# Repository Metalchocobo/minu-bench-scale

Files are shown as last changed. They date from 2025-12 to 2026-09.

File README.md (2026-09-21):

# Minù Bench Scale — ESP32 + HX711 + OLED SSD1322 + INA219 (LiFePO4 USB-C + Mini360) · v2026-09-18

Bilancia da banco per uso interno in laboratorio (gelato/pasticceria), pensata per guidare e rendere affidabili le pesate ingredienti (non “pesatura legale”).

Progetto meccanico separato: la [soluzione economica proposta per un solo prototipo](docs/mechanical/prototype-affordability/README.md) prevede cella e supporti commerciali T130, con scocca, fondo e piatto FDM personalizzati; costo completo e innesti sono ancora da verificare. Il [CAD della Proposta 02](docs/mechanical/concept-02/README.md) contiene invece quattro parti in alluminio su misura e non è il pacchetto da ordinare per questa soluzione. L'obiettivo resta 20 kg utili, otto tasti, display posseduto e ricarica USB; portata e accoppiamenti richiedono collaudo. Le varianti meccaniche non definiscono l'alimentazione montata, descritta nella sezione 2 e in [WIRING](docs/WIRING.md).

Hardware di riferimento:
- **ESP32 DevKit**
- **HX711** (ADC 24 bit) per cella di carico con eccitazione a **5 V**
- **OLED SSD1322** 256×64 (3,12", SPI)
- **Batteria NASTIMA BK06-LF60-NATC**, LiFePO4 **6,4 V nominali / 6 Ah**, con BMS e ricarica USB-C integrati
- **Mini360 DAOKAI B0B82GL5XN**, chip **MP1482DS**, uscita regolata a **5,11 V** (valore riferito sul montaggio)
- **INA219** (CJMCU-219) per tensione/corrente batteria (high-side)
- **Tastierino 4×2** + **buzzer**

---

## 0) Stato e obiettivo

Target:
- Portata: **20 kg**
- Lettura visualizzata: **1 g** nel campo operativo fino a ±16 kg
- Oltre il campo operativo il peso reale non viene trasformato in 16.000 g: compare lo stato bloccante **SOVRACCARICO**, con isteresi di rientro

Funzioni principali (firmware HX711):
- Lettura HX711 con filtri + stati **STABLE / UNSTABLE / LIVE / SOVRACCARICO**
- **Zero-tracking** vicino allo zero + **snap-to-zero** allo scarico
- **TARA** automatica e manuale con centro robusto: tollera il rumore ambientale, distingue la deriva reale e segnala acusticamente gli errori tecnici
- Monitor batteria con **tacche** + stato **charging** stabilizzato; soltanto campioni INA219 validi, plausibili e freschi alimentano filtri e protezioni
- Protezione “batteria scarica” con **avviso + beep + light-sleep**, anti-flapping (debounce 10 s, recovery stabile 30 s) e cooldown avvisi 5 min
- **HX health** runtime: stati **OK / WARN / ERROR / ERROR HARD**, badge **"Errore Cella"** (testo piccolo + triangolino) in alto a destra in WARN, schermata error bloccante (senza mostrare l'ultimo peso), blocco tara/calib, audio 0015.mp3 una sola volta all’ingresso in ERROR

### HX health (runtime, HX711)

Scopo: gestire errori runtime dell’HX711 **senza blocchi in loop** (logica solo a timestamp) e senza impattare feature non correlate.

**Soglie (ms)**
- WARN se nessun campione valido per **≥ 500 ms**
- ERROR se nessun campione valido per **≥ 3.000 ms**
- ERROR HARD se nessun campione valido per **≥ 30.000 ms** oppure **mai** registrato un valore valido
- Ritorno a OK solo dopo campioni validi “OK stabile” per **≥ 800 ms**

**Cosa conta come “campione valido”**
- Valido quando nel loop: `hx711_is_ready()` è true e `hx711_read()` completa.
- Mitigazione “DOUT mascherato” (es. partitore/pull-down): se il raw resta inchiodato (±1 count) per **> 1500 ms**, quei campioni vengono trattati come **non validi** per HX health (non aggiornano `lastRawMs`). Le soglie WARN/ERROR si conteggiano dall’inizio della flatline.
- `hx711_is_ready() == true` e lettura `hx711_read()` completata nel normale loop (niente medie bloccanti).

**Nota importante (cablaggio DOUT su ESP32)**
- Se **DOUT è su GPIO34..39** (es. **GPIO35**), l’ESP32 **non ha pull-up interni**: a modulo scollegato il pin può fluttuare e risultare “ready” a caso.
- In quel caso la rilevazione “modulo non trovato” non è affidabile solo via firmware.
- Una modifica robusta richiede un GPIO libero con pull-up o una rete esterna coerente con i livelli dell'HX711. **GPIO22 non è libero**: nel pinout corrente pilota il buzzer. Qualsiasi cambio di DOUT va quindi coordinato tra cablaggio, `config/config_pins.h` e documentazione.

**Stati e comportamento**

| Stato | Quando | UI | Audio | Azioni |
|---|---|---|---|---|
| OK | campioni regolari | UI normale | nessuno | tara/calib abilitate |
| WARN | assenza campioni ≥ 500 ms | triangolino warning alto a destra | nessuno | tara manuale abilitata; ENTER bloccato finché HX torna OK |
| ERROR | assenza campioni ≥ 3.000 ms | schermata ERROR bloccante, senza mostrare l'ultimo peso | 0015.mp3 **una sola volta** all’ingresso | **tara/calib disabilitate** |
| ERROR HARD | assenza campioni ≥ 30.000 ms o nessun valore valido mai registrato | schermata ERROR bloccante, **non** mostra valore | 0015.mp3 una sola volta all’ingresso | **tara/calib disabilitate** |

---

## 1) Perché HX711 (e perché non NAU7802)

Vincolo emerso sul campo: la cella di carico è stabile/precisa solo se eccitata a **~5 V**.  
Con NAU7802 si è provato a lavorare a 5 V, ma in un setup reale si è verificato **backfeed verso GPIO ESP32** (tensione logica troppo alta) con danni hardware.

Scelta attuale:
- HX711 alimentato a **5 V**
- ESP32 resta a **3,3 V sui GPIO**
- La linea **DOUT va resa 3,3 V safe** (vedi cablaggio)

Firmware disponibili nel repo:
- ✅ `firmware/esp32_hx711_serial/` → corrente
- ⚠️ `archive/esp32_nau7802_serial/` → storico (non consigliato)
- 🧱 eventuali cartelle “legacy” → archivio, non usare per nuove modifiche

---

## 2) Alimentazione (architettura)

**Configurazione montata:** nuova batteria USB-C NASTIMA e Mini360; Andrea riferisce cablaggio completato e primo funzionamento apparentemente regolare. La regolazione ottenuta in uscita dal Mini360 è **5,11 V**; «linea 5 V» nel resto del documento indica questa alimentazione nominale. La conferma non comprende misure di autonomia, transitori, temperatura o ripartenza dopo intervento del BMS.

Schema logico:
1. Alimentatore USB esterno → passaggio USB-C nella scocca → ingresso USB-C del caricatore **interno alla batteria**; ingresso dichiarato **5 V / 1,5 A**.
2. Batteria **+ → F1 → INA219 VIN+ → VIN− → S1 → Mini360 IN+**.
3. Batteria **− → GND comune / Mini360 IN−**; Mini360 **OUT− → GND comune**.
4. Mini360 **OUT+ → linea nominale 5 V**: ESP32 **VIN/5V**, HX711, OLED compatibile e circuito audio con power-gate esistente.

**S1 è un interruttore semplice sul positivo dopo VIN− dell'INA219. VIN− non è massa.** In OFF stacca il Mini360 dalla batteria; la ricarica interna del pacco rimane indipendente. CTK3S e batteria al piombo non fanno parte dell'alimentazione montata. L'uscita del buck resta collegata all'ESP32: S1 non isola l'eventuale alimentazione proveniente dall'USB del PC. Il ritorno USB non è stato caratterizzato sull'esemplare e non è documentato come guasto.

Condensatori esterni, tutti **in parallelo** e con collegamenti corti vicino ai rispettivi pad del Mini360:
- **IN+ ↔ IN−**, dopo S1: **220 µF / 16 V elettrolitico + 100 nF ceramico**.
- **OUT+ ↔ OUT−**: **470 µF / 10 V elettrolitico + 100 nF ceramico**; sul montaggio il ceramico è più vicino al Mini360.
- Vicino all'ESP32 restano previsti **10–47 µF + 100 nF** fra VIN/5V e GND; non sostituiscono quelli del buck.

Cablaggio completo e polarità: [docs/WIRING.md](docs/WIRING.md). Tavole e dati del convertitore: [Mini360](artifacts/mini360/README.md). Le tacche usano fasce indicative LiFePO4 e l'icona `charging` stima la ricarica dalla tensione; avvisi sonori, countdown e protezioni conservano soglie e tempi, indipendenti dall'icona (sezioni 8–9). La combinazione **TOTAL + WIFI** permette di leggere tensione e corrente INA sul display.

---

## 3) Pinout (firmware HX711)

| Funzione | Modulo | GPIO ESP32 | Note |
|---|---|---:|---|
| I2C SDA | INA219 | 32 | attenzione a non invertire con SCL |
| I2C SCL | INA219 | 33 | |
| HX711 SCK | HX711 | 16 | spesso serigrafato **RX2** |
| HX711 DOUT | HX711 | 35 | input-only, scelto per evitare strap pin |
| SPI SCK | OLED SSD1322 | 18 | VSPI |
| SPI MOSI | OLED SSD1322 | 23 | |
| SPI CS | OLED SSD1322 | 25 | |
| SPI DC | OLED SSD1322 | 26 | |
| SPI RST | OLED SSD1322 | 27 | |
| Tastiera R1 | Keypad | 17 | |
| Tastiera R2 | Keypad | 5 | |
| Tastiera R3 | Keypad | 13 | |
| Tastiera R4 | Keypad | 14 | |
| Tastiera C1 | Keypad | 19 | |
| Tastiera C2 | Keypad | 21 | |
| Buzzer | buzzer passivo | 22 | LEDC |
| DFPlayer TX | DFPlayer RX | 4 | resistenza 1 kΩ in serie consigliata |
| DFPlayer RX | DFPlayer TX | 34 | opzionale, input-only |
| DFPlayer power-gate | high-side esterno | 2 | HIGH = ON; non alimenta direttamente il modulo |
| DFPlayer BUSY | DFPlayer | 39 | input-only; pull-up esterna consigliata |
| LED standby | LED esterno | 15 | active-high, con resistenza in serie |

---

## 4) Cablaggio HX711 (importante)

### 4.1 Cella di carico → HX711
Collega i 4 fili della cella su **E+, E-, A+, A-** (colori variabili: verifica lo schema della tua cella).

### 4.2 HX711 → ESP32 (logica)

**Alimentazioni**
- HX711 **VCC → 5 V**
- HX711 **GND → GND comune**

**SCK (clock)**
- ESP32 GPIO16 → HX711 SCK **diretto (3,3 V va bene)**  
- Consigli pratici:
  - **220 Ω in serie** sul filo SCK vicino all’ESP32 (anti-ringing/spike)
  - **100 kΩ pulldown** tra SCK e GND vicino al modulo HX711 (tiene SCK LOW durante boot/reset)

> Non usare i classici level shifter bidirezionali “I2C-style” (BSS138) su **SCK**: possono tenere la linea alta e mandare HX711 in **power-down**.

**DOUT (data)**
Se HX711 è a 5 V, **DOUT può andare a 5 V**: va reso “3,3 V safe”.

Soluzione consigliata: **partitore resistivo**
- DOUT (HX711) → **10 kΩ** → GPIO35 (ESP32)
- GPIO35 (ESP32) → **20 kΩ** → GND

(Altri valori equivalenti vanno bene, l’obiettivo è restare ~≤3,3 V sul pin ESP32).

Nota pratica:
- Se colleghi DOUT diretto, prima **misura** con multimetro: se HIGH >3,6 V, è rischioso (nel tempo può rovinare l’ESP32).

---

## 5) HX711: 10 SPS vs 80 SPS

La velocità **non** si imposta da software sull’HX711: dipende dal pin/ponte **RATE** del breakout.

- Tipico default: **10 SPS**
- Per passare a **80 SPS**: modifica la pista/ponticello “RATE” sul retro del modulo (dipende dal modello)

---

## 6) Firmware: comportamento “80 Hz senza rumore a display”

Con HX711 a **80 SPS**:
- il firmware legge tutti i campioni,
- ma **decima/filtra** diversamente per WORK vs LIVE.

Concetto:
- **WORK**: più stabile (decisioni di stato, zero-tracking, ecc.)
- **LIVE**: più reattivo a display, con anti-flicker (e smoothing leggero EMA sul float)

Impostazioni attuali (HX711=80 SPS):
- WORK: decimazione **N=5**
- LIVE: decimazione **N=3** + **EMA veloce** sul valore in grammi prima della quantizzazione (alpha ~0.45)

### Display: anti-flicker
WORK e LIVE usano due visualizzazioni diverse:
1) **LIVE**: il display usa mezzi grammi virtuali (`N.0` / `N.5`) solo sull'OLED. Il valore interno usato da stack/MQTT resta in grammi interi.
2) **LIVE zero clamp**: resta a `0.0` finche' `|g| < 0.50 g`; una volta uscito dallo zero torna a `0.0` solo sotto ~`0.35 g`.
3) **LIVE half window**: su circa **600 ms** analizza media filtrata e candidati interi:
   - frazione bassa / prevalenza bassa (`<= 30%` verso l'intero alto) -> mostra `N.0`
   - zona centrale / oscillazione bilanciata (`31-69%`) -> mostra `N.5`
   - frazione alta / prevalenza alta (`>= 70%`) -> mostra `N+1.0`
   - sticky band da ~`0.08 g` sui confini `.0/.5/1.0` per evitare rimbalzi continui
4) **WORK**: resta quantizzato a grammo intero con banda zero a `1.3 g` / `0.9 g` e isteresi tra interi.

### Anti-spike guard (RAW)
Taglia i glitch singoli (es. un salto momentaneo a valori negativi/assurdi): se un campione fa un salto > **150 g**,
viene scartato e accettato solo se il campione successivo conferma (oppure se anche il successivo resta oltre soglia,
così non rallentiamo i carichi rapidi).

Nota: la guard scarta solo **frame singoli** (o confermati) e quindi non cambia la logica WORK/zt/stati, se non in presenza di glitch reali.

### TARE
- Auto-TARE e tara manuale stimano lo zero con **trimmed mean**: ordinano i campioni e scartano le due code prima della media. Vibrazioni periodiche di frullatori o lavorazioni sul banco allargano il range ma non spostano necessariamente il centro, quindi il range resta diagnostico e non blocca la tara.
- La tara manuale parte dal rilascio del tasto, usa 64 campioni e rifiuta soltanto una deriva sostenuta fra l'inizio e la fine della finestra. Un doppio beep basso più l'audio opzionale `0016.mp3` segnalano un fallimento reale; un beep acuto conferma il successo.
- La tara di lavoro post-**ENTER** è immediata quando il peso è già quieto. Se non lo è, ENTER apre un'acquisizione visibile di massimo **1,5 s**: appena arriva STABLE registra e tara; al timeout usa un centro RAW robusto soltanto se non rileva una deriva continua.

### Auto-TARE al boot
- Dopo **300 ms** di assestamento raccoglie fino a **64 campioni** in un massimo di **2 s**. Con almeno 32 campioni validi calcola sempre il centro robusto, scartando un ottavo dei valori per ogni coda, applica lo zero e completa il boot anche su un banco rumoroso.
- La qualità del segnale non è un gate di avvio: il range viene scritto nel log per diagnosi, mentre lo **zero-tracking** resta prudente e rifinisce gli scarti residui entro la propria finestra di ±1,5 g soltanto quando trova una successiva finestra quieta. Non viene allargato, così non può inseguire le vibrazioni o assorbire più facilmente un peso reale.
- Il boot si blocca soltanto se non arrivano almeno 32 campioni validi o se la calibrazione non consente di convertire i raw. In quel caso mostra **Sensore non valido**, emette sempre il doppio beep del buzzer anche senza DFPlayer, richiede **TARE** e riproduce opzionalmente `0016.mp3`.

Questa separazione è intenzionale: il rumore ambientale influenza la precisione istantanea ma non equivale a un guasto; assenza di campioni e calibrazione invalida sono invece errori tecnici che non permettono di costruire uno zero.

Anche la differenza fra TARE ed ENTER è intenzionale. TARE è una richiesta esplicita dell'operatore di assumere il centro corrente come zero. ENTER registra invece una quantità: prova prima la quiete normale e, solo dopo il timeout visibile, accetta la media robusta di un liquido che oscilla attorno a un centro fermo; una variazione ancora direzionale viene rifiutata.

I parametri (N di media, isteresi, ecc.) sono nel firmware e sono pensati per essere ritoccati in base al tuo rumore reale.

---

## 7) TARA (UI e logica)

Tasto **TARE**:
- arma la tara alla pressione e avvia il campionamento dopo il rilascio debounced, così pressione e rilascio non contaminano la misura; una pressione trattenuta oltre 1,5 s annulla l'operazione
- dopo 60 ms di assestamento valuta gli ultimi 64 campioni, taglia gli 8 estremi per lato e applica il centro robusto normalmente entro circa 0,8–1,0 s dal rilascio
- il range non annulla più l'operazione; il confronto fra la media robusta dei primi e degli ultimi 16 campioni rifiuta soltanto una deriva oltre **10 g/s**, cioè un piatto ancora realmente in movimento. Il timeout tecnico è 1,6 s
- mostra “**- TARA -**” durante l’acquisizione; un movimento reale, campioni insufficienti o un blocco di sicurezza mostrano “**TARA FALLITA** / Premi TARA e riprova” e non modificano l’offset
- durante la tara la pesata è “bloccata” a display (l’utente non deve pesare)
- se la tara manuale riesce, emette un beep positivo, azzera lo stack e salva la tara di riferimento della sessione
- se fallisce, emette il doppio beep di errore e richiede opzionalmente `0016.mp3`; il buzzer resta autorevole anche con AUDIO OFF o DFPlayer assente
- è bloccato nello stato **SOVRACCARICO**, per evitare che un carico oltre il campo operativo venga nascosto impostandolo come zero

Zero di lavoro post-**ENTER**:
- con HX OK, snapshot fresco, peso positivo e assenza di sovraccarico, un peso già STABLE in WORK o quieto da almeno 400 ms in LIVE viene registrato subito
- se il gate normale non è pronto, emette un beep basso e mostra **ACQUISIZIONE PESO** con barra di avanzamento per un massimo di **1,5 s**; appena il peso diventa quieto registra e tara senza attendere la fine della barra
- al timeout calcola un centro robusto sui campioni RAW successivi alla pressione. Il range resta diagnostico per tollerare l'oscillazione dei liquidi; una deriva oltre **4 g/s**, campioni insufficienti o non freschi rifiutano l'operazione. Il valore robusto deve inoltre restare nel campo ±16 kg
- nel fallback applica come nuovo zero lo stesso centro RAW da cui ricava i grammi registrati
- registra nello stack anche offset/zero-tracking precedenti e, per un comando session-aware, UUID, `product_id`, sessione e receipt del `confirm`; questi dati rendono reversibile il commit con CLEAR breve
- solo dopo il nuovo zero registra il peso nello stack e prepara il `confirm` MQTT; la response resta in retry finché Laravel l'ha persistita e il browser completa clear + ACK
- durante l'attesa ricontrolla sensore, calibrazione, offset e identità esatta del comando MQTT; se una condizione cambia, oppure MQTT va offline con un comando attivo, offset, stack e comando restano invariati
- non azzera lo stack e non aggiorna la tara di riferimento della sessione

Durante acquisizione e feedback ENTER gli altri tasti vengono ignorati, evitando doppi inserimenti. Il successo **REGISTRATO / Tara applicata** resta visibile per circa **1,3 s** dopo il beep; il rifiuto mostra **PESO IN MOVIMENTO / NON REGISTRATO** oppure **ACQUISIZIONE FALLITA / NON REGISTRATO** per circa **2 s** dopo il doppio beep. Tutte queste schermate si chiudono da sole.
La tara manuale è rifiutata durante un upload OTA, che continua quindi senza interruzioni.

---

## 8) Monitoraggio batteria INA219

Il pacco montato è LiFePO4 con ricarica USB-C interna. L'INA219 esterno misura tensione ai morsetti e corrente verso il Mini360; non misura la corrente netta delle celle. Le tacche rappresentano fasce indicative di tensione, non percentuali calibrate di capacità residua.

### 8.1 Collegamenti INA219
- VCC → **3V3**
- GND → GND
- SDA → GPIO32
- SCL → GPIO33
- VIN+ dopo F1 sul positivo batteria; VIN− verso S1 e poi IN+ Mini360 (vedi [cablaggio](docs/WIRING.md))

Se INA non viene trovato:
- prima cosa: controlla **SDA/SCL non invertiti**.
- Il bus I2C usa un timeout `Wire` di **50 ms** per limitare blocchi su transazioni INA219 anomale.

Validità runtime:
- tensione e corrente aggiornano stato, filtro e rilevamento charging soltanto se ogni lettura I2C termina con successo e i valori sono finiti e plausibili
- un errore di lettura non viene convertito in una falsa tensione bassa: resta disponibile l'ultimo campione valido per la sola UI, marcato con la propria età; `charging` e i suoi timer vengono azzerati su letture invalide o scadute, senza far avanzare il debounce
- i limiti di plausibilità correnti sono 3–9 V sul bus, ±330 mV sullo shunt e ±3.500 mA
- countdown e sleep di protezione richiedono sempre un campione valido più recente di **1,5 s**; un valore stale non può spegnere la bilancia

Lettura sul display: tenere premuti insieme **TOTAL + WIFI**, in qualunque ordine. La schermata **BATTERIA** mostra la tensione filtrata ai morsetti con due decimali e la corrente verso il carico in mA, aggiornate dalle letture INA ogni **500 ms**. Al rilascio di uno dei due tasti torna la schermata ordinaria; entrambi devono essere rilasciati prima di usarli di nuovo. La combinazione non commuta il WiFi e non esegue TOTAL. Dopo **15 s** interviene la normale protezione da tasto bloccato, che chiude la lettura fino al rilascio completo.

Se il sensore è assente o la lettura è invalida/scaduta, appare il relativo messaggio senza valori numerici. Errori, sovraccarico, ENTER, TARE e calibrazione mantengono la priorità; campionamento peso, MQTT e protezione batteria continuano normalmente. Questa schermata non modifica soglie, calibrazione o rilevamento `charging`.

### 8.2 Soglie tacche (default firmware, tensione filtrata)
Fasce iniziali LiFePO4 definite in `config/config_battery.h`, da verificare durante una scarica reale:
- **4 tacche (FULL)**: ≥ **6,60 V**
- **3 tacche (GOOD)**: **6,50 V ≤ V < 6,60 V**
- **2 tacche (LOW)**: **6,35 V ≤ V < 6,50 V**
- **1 tacca (CRITICAL)**: **6,10 V ≤ V < 6,35 V**
- **0 tacche (EMPTY)**: < **6,10 V**

FULL indica la fascia alta, non certifica una carica completa. La lettura riferita di **6,63–6,64 V** dopo 15 minuti con USB scollegata rientra nella fascia alta; le soglie inferiori non derivano ancora da una scarica misurata. Restano il filtro di tensione e i tempi esistenti, senza nuova isteresi o debounce delle tacche.

Nota: c'è un **cuscinetto** tra 0 tacche e il light-sleep per batteria scarica. La sequenza di countdown parte a **≤ 5,80 V** dopo il debounce previsto.

### 8.3 Indicatore “in carica” da tensione
Con la NASTIMA, la corrente USB entra nel caricatore interno al pacco senza attraversare lo shunt esterno. L'INA219 misura **la corrente diretta al carico**, che resta disponibile nella diagnostica ma non determina `charging`. L'icona usa invece la tensione filtrata, con soglie iniziali scelte dalle letture riferite da Andrea:

- si accende con **V ≥ 6,70 V** per almeno **5 s** continui
- si spegne con **V ≤ 6,68 V** per almeno **10 s** continui
- nella banda **6,68 V < V < 6,70 V** conserva lo stato; una conferma interrotta riparte da zero
- non impone un tempo minimo acceso aggiuntivo
- usa soltanto campioni validi e freschi: una lettura invalida o scaduta spegne l'indicazione e azzera i timer; per riaccenderla serve una nuova conferma completa

Il campionamento resta ogni **500 ms**, con filtro EMA di tensione **α = 0,2**. È una **stima indicativa della ricarica**, non una prova di USB collegata né una misura della carica residua. Con batteria bassa la ricarica può essere attiva senza raggiungere 6,70 V; dopo aver scollegato l'USB l'icona resta accesa finché non è confermata la soglia di uscita. Questa indicazione non disabilita le protezioni per tensione bassa.

---

## 9) Batteria scarica: avviso + light-sleep (protezione ESP)

La protezione qui è pensata per l’ESP32 (evitare latenze/reset quando il buck 5V perde margine). Entra in light-sleep, ma non scollega fisicamente Mini360 o batteria e non sostituisce il BMS del pacco. Avvisi, countdown e soglia hard-low restano attivi anche con l'icona `charging` accesa: il collegamento USB o lo stato dell'icona non annullano la protezione. Il recupero dipende dalla tensione misurata.

Comportamento:
- **0 tacche (EMPTY)**: icona batteria **lampeggiante** sotto **6,10 V**. L'avviso sonoro ha una soglia separata dalle tacche:
  - **0011.mp3** (batteria bassa) con **cooldown 5 min**
  - beep buzzer con **cooldown 5 min**
  - L'avviso 0011 e il beep richiedono **5,80 V < V < 5,85 V** per almeno **10 s** (`V_EMPTY_WARNING_MAX_V`); sotto questa finestra interviene il percorso countdown/critico. Cambiare le tacche non cambia questa finestra o il recupero del countdown.
- Se V scende a **≤ 5,80 V** per ≥ **5 s**:
  - schermo “batteria scarica, collega alimentatore”
  - **0012.mp3** (batteria critica) **subito all'ingresso countdown** e **di nuovo a metà** (a ~60 s)
  - beep ogni **10 s** per **120 s**
  - segue la schermata **Zzz per 5 s**, poi entra in **LIGHT-SLEEP**; la soglia hard-low può anticipare lo sleep
- La soglia hard-low **≤ 5,70 V** deve restare confermata da campioni INA validi e freschi per circa **3 s** prima dello sleep; il debounce non aggiunge un rilevamento della presenza USB.
- Prima del light-sleep per batteria scarica: DFPlayer viene **spento** via MOSFET (zero consumo audio in sleep).
- Prima della disconnessione pulita MQTT viene pubblicato retained lo stato `sleeping`, così il gestionale non conserva uno status `online` mentre la bilancia dorme.
- Anti-troncamento audio (DFPlayer): applicato un gap ~200 ms tra stop → play e ignorati i primi ~300 ms di BUSY=idle dopo il play (evita tagli tipo 0001→0002).
  - Nota HW: BUSY su GPIO39 non ha pull-up interno; se il BUSY resta instabile, aggiungere pull-up esterno verso 3V3 (10k..47k).
- Wake: premendo un tasto la tastiera risveglia l'ESP32; quel tasto viene consumato fino al rilascio e non può avviare anche TARE, ENTER, CLEAR, SKIP o un nuovo sleep

---

---

## 10) Risparmio energetico per inattività (5 minuti)
Se per **5 minuti** non viene premuto alcun tasto, il peso visualizzato resta fermo entro ±5 g e non esistono comando MQTT operativo o response outbox ancora agganciato al Manager, la bilancia entra in **LIGHT-SLEEP**. Un outbox già passato alla modalità locale continua a vivere in RAM e riprende i retry al wake senza tenere acceso il display.

Caratteristiche:
- Wake: **qualsiasi tasto**.
- L'inattività viene azzerata anche da una variazione del peso visualizzato **> 5 g** (in LIVE o WORK).
- Ogni `weigh`/clear MQTT accettato azzera il timer; un comando operativo o una response ancora agganciata al Manager bloccano l'auto-sleep, mentre dopo il fallback locale non lo bloccano più.
- Prima della sospensione MQTT viene pubblicato retained `state=sleeping`; il LWT `offline` resta riservato alle disconnessioni impreviste.
- Il tasto che provoca il wake viene ignorato come comando finché non viene rilasciato.
- **Nessun reset** dello stato/pesata: riprende esattamente dove era.
- WiFi/OTA vengono sospesi prima dello sleep e riattivati dopo il wake **solo se l'utente ha lasciato il WiFi ON**.
- **SLEEP breve**: al rilascio avvia la sequenza di standby manuale (schermata **Zzz...** per ~5 s + audio 0003), poi light-sleep anche se è presente un semplice comando `weigh` MQTT. Se il worker MQTT sta connettendo, la richiesta resta accodata e lo sleep parte appena il trasporto viene rilasciato, senza richiedere una seconda pressione. Una response ancora nel lock operatore, un upload OTA o il sovraccarico continuano invece a bloccarlo; una response già detached no.
- **SLEEP tenuto per 2 secondi**: non entra in standby; commuta il DFPlayer tra **AUDIO OFF** e **AUDIO ON**, salva la scelta in NVS e la mantiene dopo riavvii e spegnimenti completi, con conferma sul display e buzzer.

### Indicatore esterno sleep (LED)
Quando il display è spento, per capire che la bilancia è in sleep, usa un LED su:
- **GPIO15** → **resistenza 330–2.2kΩ** → **anodo LED** → catodo a **GND** (HIGH = LED acceso).

## 11) WiFi + OTA (opzionale)

Il firmware HX711 supporta:
- WiFi **non bloccante** (background)
- OTA via Arduino IDE (porta di rete)

Dove si configura:
- Le credenziali **non** stanno nel codice e **non** vanno versionate.
- Si impostano via **seriale** e vengono salvate in **NVS** (persistono tra aggiornamenti firmware).

Note pratiche:
- di default è attivo **ENABLE_WIFI_OTA = 1**
- l’icona WiFi sul display segue lo stato di connessione (se WiFi è abilitato a compile-time)
- con due reti configurate, il firmware prova gli slot in sequenza; prima di passare allo slot successivo interrompe il tentativo STA corrente e attende una breve pausa non bloccante, cosi il nuovo SSID viene applicato davvero dal driver ESP32

Configurazione credenziali (max 2 reti, via seriale):
- `wifi set 1 "SSID" "PASS"`
- `wifi set 2 "SSID" "PASS"`
- `wifi creds` (lista SSID con password mascherata)
- `wifi creds showpass 1` / `wifi creds showpass 2` (recupero: stampa password in chiaro)
- `wifi clear 1` / `wifi clear 2` / `wifi clear all`
- `wifi apply` (ricarica credenziali e riavvia i tentativi senza reboot)

Password OTA (consigliata):
- `ota status`
- `ota set "PASS" [reboot]`
- `ota clear [reboot]`
- `ota reboot`

Note: la password non viene salvata in chiaro: in NVS resta solo un hash (MD5). Per rendere effettivi set/clear serve un reboot.

Persistenza:
- le credenziali restano in NVS anche dopo OTA/upload standard.
- si perdono solo con un **erase flash** completo o modifiche invasive alle partizioni.

Tasti:
- **WIFI**: al rilascio abilita/disabilita il WiFi in modo **persistente** (salvato in NVS), salvo utilizzo nella combinazione **TOTAL + WIFI**.
  - Feedback al rilascio: **bip** (buzzer). La connessione vera e propria avviene in background.
  - All’avvio il WiFi segue la preferenza utente, non l’ultimo stato momentaneo (es. WiFi spento in sleep).
  - Durante il light-sleep per inattività il WiFi viene comunque spento per consumi, ma al wake viene riattivato **solo** se la preferenza è ON.
  - Lo `scale_id` non dipende dallo stato del modulo WiFi: viene letto dal MAC STA in eFuse anche se la preferenza parte OFF. Se l'identità hardware non è valida, MQTT resta disabilitato invece di usare `000000000000`.
  - Audio:
    - **0005.mp3**: Wi‑Fi modulo ON (toggle manuale)
    - **0006.mp3**: Wi‑Fi modulo OFF (toggle manuale)
    - **0008.mp3**: connessione Wi‑Fi avvenuta (anche in background)
    - **0007.mp3**: errore connessione Wi‑Fi (connect failed / SSID non disponibile, con cooldown)
    - Dopo un wake da light-sleep la riconnessione **non** viene annunciata (comportamento come prima).

- **MODE**: cambio modalità WORK/LIVE con **bip** immediato (buzzer) + audio **0017/0018.mp3**.

Se non ti serve OTA/WiFi:
- imposta `#define ENABLE_WIFI_OTA 0` per ridurre consumi e complessità

---

## 12) MQTT — Integrazione gestionale

Il firmware comunica in tempo reale con il browser del gestionale Laravel/Backpack tramite Mosquitto. Il browser usa WSS, la bilancia MQTTS; Laravel gestisce associazioni, UI e persistenza REST, ma non è nel percorso MQTT real-time.

Abilitazione: `#define ENABLE_MQTT 1` in `net_ota_cloud.h` (richiede `ENABLE_WIFI_OTA 1`).

### Credenziali

Le credenziali MQTT (host, username, password) **non** sono nel codice sorgente. Si configurano via seriale e vengono salvate in NVS (persistono tra aggiornamenti firmware), come per WiFi e OTA.

Comandi seriali:
- `mqtt set "host" "user" "pass"` — salva credenziali MQTT in NVS
- `mqtt creds` — mostra host e user (password mascherata)
- `mqtt creds showpass` — mostra password in chiaro
- `mqtt clear` — cancella credenziali da NVS
- `mqtt apply` — ricarica credenziali e riconnette senza reboot
- `mqtt status` — mostra stato connessione, scale_id, comando attivo

Se le credenziali non sono configurate, MQTT resta inattivo (nessun tentativo di connessione).

Porta bilancia: **8883** (MQTTS/TLS). Porta browser: **8884** (WSS/TLS). Il certificato CA ISRG Root X1 è nel firmware. `MQTT_SCALE_NAME` e `MQTT_FW_VERSION` sono definiti in `net_ota_cloud.h`; la versione corrente è **1.5.2**.

### Topic e QoS effettivo

La bilancia si identifica con il MAC STA letto direttamente dall'eFuse ESP32 (lowercase, senza separatori, 12 hex), usato come `scale_id` nei topic MQTT. L'identità è disponibile anche con WiFi inizialmente OFF; il valore tutto zero è invalido e impedisce l'avvio MQTT.

| Topic | Direzione | QoS | Retain | Uso |
|---|---|---:|---:|---|
| `minu/scale/{scale_id}/command` | Browser → bilancia | 1 | `weigh`/`clear` sì; `confirm_request` no | comando retained e richiesta ENTER remota fenced |
| `minu/scale/{scale_id}/response` | Bilancia → browser | 0 | no | `command_ack`/`confirm_request_ack` transitori; `confirm`, `skip` e `undo` durable con retry applicativo |
| `minu/scale/{scale_id}/ack` | Browser → bilancia | 1 | no | `response_ack` o `response_reject` terminale |
| `minu/scale/{scale_id}/status` | Bilancia → browser | online/sleeping 0; LWT offline 1 | sì | heartbeat diagnostico e stato operativo |
| `minu/scale/{scale_id}/owner` | Browser → browser + bilancia | 1 | sì | lease della scheda e `expected_command_id` |

PubSubClient pubblica a QoS 0: per questo una response non viene considerata consegnata dal solo risultato di `publish()`. Il buffer della libreria viene impostato e verificato a runtime con `mqttClient.setBufferSize(640)`; il solo define `MQTT_MAX_PACKET_SIZE` non è sufficiente. L'envelope owner resta bounded perché `user_name` è normalizzato a massimo 48 byte UTF-8 e ciascun ID a 64 caratteri, incluso `expected_command_id`; lo stesso limite copre lo status diagnostico completo.

Firmware 1.5.2 ripubblica lo status retained ogni **5 secondi** e ad ogni variazione diagnostica. Oltre ai campi discovery contiene `boot_id`, `transport_id`, `status_seq`, `published_at` epoch, `uptime_ms`, `operational_mode`, `tare_required`, `fallback_reason`, `last_command_error`, `rx_probe_seq`, `rx_mask`, `rx_health` e `pending_response_id`. `tare_required` è un booleano esplicito: quando un incidente di sincronizzazione non è rollbackabile resta `true`, con `operational_mode=local`, finché una TARE fisica termina con successo. `rx_mask` usa bit owner=1, command=2, ack=4; `rx_probe_seq`, mantenuto per compatibilità dello schema, conta le generazioni SUBSCRIBE/resubscribe del watchdog passivo. `published_at` permette al Manager di non scambiare uno status retained online vecchio per una connessione corrente.

### Payload session-aware e command fence

Comando di pesatura:

```json
{"type":"weigh","uuid":"...","product_id":123,"name":"Zucchero","target_weight":450,"session_id":"...","connection_id":"...","command_id":"..."}
```

`command_id` identifica una singola attivazione del comando, è lungo 8–64 caratteri e ammette lettere ASCII, cifre, `-` e `_`. Il valore vuoto resta ammesso soltanto per compatibilità con i browser precedenti. Il Manager conserva l'ID sui retry soltanto quando sessione, UUID, prodotto, nome e target sono identici; una variazione semantica genera un ID nuovo. Un replay identico con lo stesso `command_id` non reinizializza il comando e riemette `command_ack`; su reload aggiorna soltanto il `connection_id` del documento corrente. Lo stesso ID riutilizzato con contenuto business diverso viene ignorato senza ACK e senza modificare lo stato attivo.

Da firmware 1.4.1 un `weigh` dotato di `connection_id` è attivabile soltanto quando il retained `owner` è fresco e coincide con la sua coppia sessione/connessione. La bilancia calcola la vita residua dai timestamp originali del lease, quindi un owner retained vecchio non viene ringiovanito al reconnect. Il lease di controllo resta di 30 secondi; da 1.5.0 la presenza operativa scade dopo 25 secondi dall'arrivo dell'ultimo owner valido, così tollera un heartbeat da 10 secondi saltato senza sommare lo skew dell'orologio alla finestra di presenza. Un heartbeat con timestamp strettamente avanzato sullo stesso lease può ottenere al massimo 5 secondi di tolleranza per clock/jitter quando l'età è entro 10 secondi; un retained replay uguale o un lease già scaduto non riceve mai questa tolleranza. Da 1.5.2, quando la bilancia è già in fallback con un baseline owner noto, il recupero non dipende più dal confronto tra epoch tablet ed ESP32. Il primo owner di una nuova connessione/lease viene conservato come candidato inattivo; soltanto un secondo heartbeat con timestamp strettamente avanzato sulla stessa generazione prova un publisher vivo e abilita la presenza monotona. Un retained isolato o un replay uguale non può quindi riaprire il controllo. Il percorso non si applica agli snapshot retained iniziali senza baseline, che restano soggetti al TTL wall-clock. Da 1.4.4 il loop elabora fino a quattro pacchetti MQTT già disponibili prima di valutare il fallback locale: il burst bounded copre il normale owner/command accodato senza affamare il campionamento di tasti e bilancia. Dopo ogni reconnect attende inoltre il nuovo snapshot retained `command`: il solo owner non può riattivare per un loop un vecchio comando RAM prima dell'arrivo di un eventuale clear o ingrediente nuovo. Se l'owner sparisce o gli snapshot necessari non arrivano, il comando moderno resta raw in RAM ma non è operativo né visibile. Lo sgancio abilita una modalità locale: TARE e ENTER fisici restano utilizzabili anche con MQTT connesso, senza generare una seconda response remota. Un retained `weigh` della connessione sganciata non può riattivarla: serve un heartbeat più nuovo o una nuova connessione. Solo il relativo `command_ack` riaggancia la modalità gestita. I comandi privi di `connection_id` conservano il comportamento legacy.

Da firmware 1.5.0 la bilancia non si fida più del solo risultato locale di `subscribe()`, perché PubSubClient 2.8 non espone il SUBACK. Il controllo è passivo e non pubblica probe sui topic business: durante un contesto remoto usa owner heartbeat validi, traffico retained `command` e ACK terminali come prova delle singole subscription. Se un ingresso realmente atteso tace, esegue al massimo tre subscribe distanziate di 2,5 secondi e poi ricostruisce una volta il trasporto, conservando byte-per-byte l'outbox. Da 1.5.1 la prova del topic è separata dalla convergenza business: un `command` ricevuto ma diverso da `expected_command_id` prova che la subscription funziona, mantiene il comando non azionabile e attende la riconciliazione senza risottoscrivere o riavviare il socket. La finestra per un comando realmente assente parte dal cambio effettivo dell'aspettativa e non viene prorogata dai successivi heartbeat con lo stesso valore. Un `weigh` moderno strutturalmente valido che precede l'owner esatto apre analogamente un'attesa owner deduplicata per `command_id + connection_id`: un PUBLISH owner successivo prova il trasporto anche se è malformed o appartiene ancora al proprietario precedente, mentre la vera assenza avvia il repair bounded. La stessa fingerprint può ricostruire il socket una sola volta; se anche il nuovo trasporto resta senza evidenza, la bilancia rimane in `LOC` senza loop di reconnect. L'evidenza non attraversa il cambio socket e il timer non viene prorogato dai retry o da nuovi ID arrivati mentre una grace è già aperta. Quando non c'è una response o `confirm_request` in corso, `expected_command_id=""` è una dichiarazione autorevole di clear e rimuove anche un comando raw RAM se il broker non possiede alcun retained da riprodurre; un `weigh` successivo resta ignorato finché l'owner continua ad attendere clear. Durante una response il campo è omesso e outbox/comando restano immutabili; l'assenza mantiene inoltre la compatibilità con Manager precedenti. L'assenza di traffico a bilancia idle senza owner non provoca reconnect. Per uno stesso outbox l'assenza ACK causa un solo rebuild; se il backend continua a non rispondere, il retry prosegue senza loop di reconnect e status espone `ack_timeout`.

Pulizia comando:

```json
{"type":"clear","session_id":"...","connection_id":"...","command_id":"..."}
{"type":"clear","session_id":"...","connection_id":"...","command_id":"...","lifecycle":"pagehide"}
{"type":"clear","session_id":"...","connection_id":"...","lifecycle":"pagehide"}
```

Senza response pending la bilancia accetta un `clear` live soltanto se la fence è coerente: un comando moderno richiede lo stesso `session_id`, lo stesso `command_id` e un `connection_id` non vuoto. Se esiste un owner fresco, la connessione deve essere la sua; in assenza di owner fresco, il retained clear esatto è trattato come tombstone autorevole del broker. Inoltre, il primo snapshot `command` dopo reconnect è autorevole sul raw RAM: un retained clear moderno lo rimuove anche se nel frattempo il broker è avanzato a un'altra coppia sessione/comando. Se il relativo weigh era stato respinto prima di entrare nel raw RAM per owner mancante, il clear con la stessa fingerprint `command_id + connection_id` chiude comunque l'attesa owner diagnostica senza toccare un eventuale outbox. Il nuovo documento proprietario può così pulire il comando del predecessore, mentre un `pagehide` tardivo della vecchia connessione non può cancellare quello nuovo finché il nuovo owner è vivo. Da 1.4.2 il clear `lifecycle=pagehide`, autenticato dall'esatta sessione/connessione owner, può sganciare subito l'operatore anche senza comando o con una response pending; cancella il raw soltanto quando coincide anche la fence comando e non modifica mai l'outbox. I clear normali REST-before-ACK restano ignorati durante il pending. Le regole v1.2/legacy restano invariate.

Conferma transitoria di attivazione firmware:

```json
{"type":"command_ack","command_id":"...","session_id":"...","connection_id":"...","uuid":"...","product_id":123,"state":"active"}
```

Il firmware pubblica `command_ack` sul topic `response` soltanto dopo avere attivato un `weigh` con `command_id` e quando lo stesso comando è realmente azionabile: non emette `state=active` durante fallback `LOC`, TARE obbligatoria o prima della convergenza owner/command. Lo ripubblica per ogni replay identico dello stesso ID una volta ristabilito lo stato azionabile. Da firmware 1.4 riecheggia anche la connessione corrente, così un documento ricaricato non diventa pronto prima che il firmware abbia visto il suo nuovo `connection_id`. Da 1.4.2 ogni nuova eco owner esatta invalida nel Manager la precedente prova di attivazione e forza il replay dello stesso `weigh`: la pagina torna pronta solo sul nuovo ACK, quindi un fallback firmware non può restare nascosto dietro un ACK in cache. Questo ACK è QoS 0, non usa l'outbox, non contiene `response_id` e non rappresenta una mutazione Laravel. I comandi precedenti senza `command_id` non producono il nuovo ACK.

Conferma remota dal Manager:

```json
{"type":"confirm_request","request_id":"...","session_id":"...","connection_id":"...","command_id":"...","uuid":"...","product_id":123}
{"type":"confirm_request_ack","request_id":"...","command_id":"...","connection_id":"...","state":"accepted|staged|failed|rejected","reason":"..."}
```

`confirm_request` è QoS 1 ma **non retained**. È accettata soltanto dalla connessione corrente e per l'esatta identità del `weigh`; il callback MQTT la accoda e il loop esegue lo stesso percorso di ENTER fisico: preflight, lock TARE, eventuale acquisizione da 1,5 s, zero di lavoro, push reversibile e staging del `confirm`. `request_id` rende idempotenti doppio click e retry: lo stesso ID riemette l'ultimo ACK senza ripetere ENTER, un ID diverso durante acquisizione/outbox riceve `rejected/busy`. Una cache RAM conserva gli ultimi due esiti terminali `failed`/`rejected`: finché l'ID resta in uno dei due slot, la perdita del relativo ACK QoS 0 non può trasformarlo più tardi in un nuovo ENTER. `accepted` e `staged` sono solo stati transitori e non fanno avanzare il Manager; `failed`/`rejected` lasciano attivo lo stesso ingrediente. L'unico successo funzionale resta la response durable `confirm` completata da Laravel, clear e `response_ack`.

Response firmware:

```json
{"type":"confirm","uuid":"...","product_id":123,"session_id":"...","command_id":"...","response_id":"a1b2c3d40000012300000001","actual_weight":448.0}
{"type":"skip","uuid":"...","product_id":123,"session_id":"...","command_id":"...","response_id":"a1b2c3d40000012300000002"}
{"type":"undo","uuid":"...","product_id":123,"session_id":"...","response_id":"a1b2c3d40000012300000003","undo_of_response_id":"a1b2c3d40000012300000001"}
```

`confirm` e `skip` riportano il `command_id` originale quando il comando lo possiede. `undo` è prodotto soltanto da un CLEAR breve su una voce session-aware reversibile: non inventa un nuovo `command_id`, perché la correlazione durabile è già espressa da `undo_of_response_id`, che punta alla receipt del `confirm` originario. Una voce locale o legacy priva di tale receipt viene annullata soltanto sul firmware.

ACK browser:

```json
{"type":"response_ack","response_id":"a1b2c3d40000012300000001"}
{"type":"response_reject","response_id":"a1b2c3d40000012300000001","reason":"manager_incident"}
```

Il firmware conserva una sola response session-aware in RAM e la ripubblica ogni **1 secondo** finché riceve un esito terminale con la stessa `response_id`. `response_ack` significa mutazione applicata; `response_reject` è accettato esclusivamente con `reason=manager_incident`, elimina l'outbox senza simulare un successo e resta idempotente sui replay. Il payload staged, inclusi `session_id`, l'eventuale `command_id` e `response_id`, resta byte-per-byte immutabile. Il lock fisico di consegna è limitato a **10 secondi**, termina prima su `pagehide` fenced/owner scaduto e viene sganciato immediatamente se l'operatore preme fisicamente TARE o ENTER. L'outbox continua in background, mentre quell'input e i successivi TARE/ENTER diventano esclusivamente locali. SKIP/CLEAR remoto, nuovi `weigh` e nuove response restano serializzati sul singolo outbox. Un `confirm` quarantinato viene ripristinato localmente una sola volta soltanto se la sua receipt è ancora l'ultima voce e il lock operatore non era stato sganciato; altrimenti stack e riferimento vengono invalidati, senza creare successi, undo o ACK per una receipt inesistente. Un `undo` rifiutato prima del detach lascia lo stack invariato. Se il restore detached era già stato applicato, un reject tardivo non tenta una compensazione pericolosa: invalida stack/riferimento locali, mostra `SYNC ERROR — Premi TARA`, blocca ENTER/SKIP/CLEAR e richiede una TARE fisica. Fino alla TARE riuscita lo status espone `tare_required=true`, la modalità resta locale e un eventuale comando raw viene conservato ma non è azionabile né riceve `command_ack`; dopo la TARE lo stesso contesto valido può essere riattivato e confermato una sola volta.

Outbox e cache dei due esiti terminali sono RAM: un reboot le perde, e più di due request terminali diversi possono espellere il più vecchio. Il Manager normale mantiene una sola richiesta irrisolta per scheda; una garanzia attraverso reboot o publisher concorrenti richiederebbe un journal persistente dedicato.

Per firmware/browser v1.4 l'ordine è transazionale:

1. il browser invia a Laravel la response completa, inclusi `scale_id`, `response_id`, `product_id`, UUID e azione;
2. Laravel registra una receipt durabile e applica la mutazione nella stessa transazione; il replay identico è idempotente;
3. soltanto dopo commit o replay già processato il browser pubblica il `clear` retained e attende il PUBACK QoS 1;
4. soltanto dopo il PUBACK del clear pubblica `response_ack` e ne attende il PUBACK QoS 1;
5. infine aggiorna la UI. Se la mutazione non può essere applicata ma Laravel registra durablemente l'incidente, il browser pubblica prima il clear e, dopo il relativo PUBACK, invia `response_reject` con `reason=manager_incident`; senza commit dell'incidente non invia alcun esito terminale.

Il PUBACK broker di `response_ack` non prova che il firmware fosse ancora online e l'abbia elaborato. Uno status `offline` o `sleeping` invalida quindi una consegna non conclusa; se il firmware ripubblica una response già persistita, il browser ripete clear e ACK senza ripetere REST o callback UI. Una response dello stesso prodotto della pagina, incluso `undo`, forza la riconciliazione anche se l'ingrediente desiderato è già avanzato o assente; una response di un altro prodotto viene conciliata senza cancellare il comando corrente.

La coppia (`scale_id`, `response_id`) resta l'identità della receipt. La `session_id` e l'eventuale `command_id` del payload staged descrivono l'origine e non vengono ritargettati. Solo un `response_ack` esatto o un `response_reject/manager_incident` esatto chiude l'outbox e azzera il comando; esiti estranei, nuovi comandi, clear e scadenza owner non possono alterarlo. Se il browser desidera attivare un comando arrivato mentre l'outbox era pending, lo ripubblica dopo avere completato receipt, clear retained ed esito terminale.

I browser precedenti restano supportati. Un comando v1.2 privo di `command_id` ma con sessione può essere cancellato solo da un clear anch'esso privo di ID con la stessa `session_id`; per un comando realmente legacy senza sessione il clear può riportare la sessione del Manager nuovo. Un comando privo di `session_id` usa response one-shot senza `response_id`, senza receipt/ACK applicativo e senza undo remoto.

### Ownership browser

Ogni scheda browser usa un `session_id` stabile durante reload e reconnect, un `connection_id` diverso per ogni documento e un nuovo `command_id` per ogni attivazione logica, conservato nei retry dello stesso comando. Un Web Lock esclusivo impedisce a una scheda duplicata di riusare l'ID copiato da `sessionStorage`; il fallback cross-tab ruota l'ID anche quando la presenza di un'altra istanza resta incerta. Il topic owner retained contiene anche `connection_id`, `lease_id` ed `expected_command_id` quando non c'è una response in corso: il valore è l'ID desiderato oppure `""` per dichiarare che il firmware non deve avere un comando attivo. Il controllo è confermato dall'eco esatta di utente, sessione, connessione e lease, mentre lo stato comando deve coincidere con l'hint. Il proprietario rinnova il lease ogni **10 secondi**; dopo **30 secondi** senza rinnovo un'altra scheda può reclamarlo. Il firmware considera presente il consumer per **25 secondi dall'arrivo** dell'ultimo owner valido, tollerando un heartbeat saltato. Una tolleranza massima di 5 secondi sul TTL è concessa soltanto a timestamp strettamente progressivi dello stesso lease con skew entro 10 secondi; replay uguali e lease scaduti restano esclusi. Il timestamp monotono è verificato soltanto all'interno dello stesso `connection_id + lease_id`. In fallback 1.5.2, una nuova generazione diventa prima un candidato inattivo e viene attivata solo dal secondo heartbeat strettamente progressivo sulla stessa lease; il Manager produce entrambe le prove nella recovery fenced. Il recupero non dipende dall'epoch ESP32 e un retained isolato resta innocuo.

```json
{"user_id":123,"user_name":"Andrea","session_id":"...","connection_id":"...","lease_id":"...","expected_command_id":"...","timestamp":1784720000}
```

**Alla connessione:**
- la bilancia pubblica status `online` retained con scale ID, nome e firmware version;
- registra un LWT `offline` retained;
- si sottoscrive prima a `owner`, poi a `command` e `ack`, richiedendo QoS 1;
- il browser attende i SUBACK di response/status/owner/command, uno status fresco e la conferma esatta del lease prima di pubblicare o ripubblicare un comando attivo; se un SUBACK manca/fallisce o lo status retained fresco non arriva, il connection barrier resta non-ready e ritenta per intero la coorte con callback fenced;
- il browser non registra un LWT che modifichi `command`: con firmware 1.4.2+, su una vera uscita `pagehide`, l'owner esatto pubblica un solo `clear` retained con `lifecycle=pagehide` e poi chiude il socket in modo graceful, anche senza comando o con una response in corso. I passaggi interni tra ingredienti/modalità, i form che tornano alla pesatura e il reload dopo una response marcano invece un handoff: chiudono il vecchio socket senza detach, così il nuovo documento può sostituire owner e comando senza attivare il fallback sticky. Il publish di uscita resta best-effort; se il processo viene terminato prima della consegna, il lock operatore di una response cede al primo TARE/ENTER o entro 10 secondi, mentre la presenza operativa owner decade entro 25 secondi;
- la UI è verde soltanto dopo l'eco retained del comando e il relativo `command_ack` firmware; durante reconnect o riparazione resta in sincronizzazione.
- quando il documento torna visibile, invalida subito la prova di attivazione precedente, sospende l'heartbeat e rilegge l'owner retained; rinnova lo stesso lease soltanto se è ancora esatto, quindi non sovrascrive un takeover avvenuto mentre la scheda era sospesa. La relativa eco fa ripubblicare lo stesso `weigh` e richiede un ACK nuovo.

Ordine di rollout 1.5 raccomandato: aggiornare prima il firmware, poi Manager/backend che pubblicano `expected_command_id`, gestiscono lo status diagnostico e possono usare `response_reject`. Così un terminale reject non incontra mai un firmware precedente che lo ignorerebbe lasciando l'outbox aperto. Non è richiesto alcun cambio ACL: la bilancia continua a pubblicare soltanto `status` e `response`, senza probe su `owner`, `command` o `ack`.

Cambio e disassociazione bilancia sono bloccati finché una `confirm_request` è attiva o una response è in sincronizzazione. Una request staged passata al timeout browser non mantiene il lock e non può essere rieseguita. Se la response inizia mentre il salvataggio del cambio è già in corso, la transizione MQTT attende in modo non bloccante la fine della consegna. Clear e rilascio owner sulla vecchia bilancia vengono pubblicati soltanto dalla connessione che possiede il lease esatto.

**Comando `weigh`:** il browser invia UUID ingrediente, `product_id`, nome e peso target. La bilancia emette un bip distintivo di ricezione, azzera il timer inattività e mostra il target sul display (icona target + grammi).

**Comando `confirm_request`:** il pulsante Conferma del Manager, con bilancia associata, chiede alla bilancia di eseguire ENTER. Non sostituisce il retained `weigh`, non chiama direttamente la conferma Laravel e viene ritentato con lo stesso `request_id` finché il firmware comunica `staged`, `failed` o `rejected`. Dopo reconnect il Manager riattiva prima lo stesso `weigh` e attende un `command_ack` fresco. Se dopo `staged` cade il trasporto o viene revocato l'owner esatto e la response non torna entro 10 secondi, sblocca il percorso manuale senza ripetere ENTER e continua a conciliare un eventuale `confirm` tardivo.

**Conferma manuale:** il pulsante **Pesata già fatta** marca l'ingrediente eseguito senza inventare un peso o una provenienza bilancia. Resta l'unica conferma quando la bilancia non è pronta; nello stato verde `ready` viene mostrato insieme a **Conferma bilancia**. Durante una `confirm_request` attiva o response in corso entrambe le azioni restano bloccate; il timeout browser di una request già staged riabilita soltanto il manuale.

**Comando `clear`:** per i comandi moderni annulla soltanto la stessa coppia `session_id + command_id`; con owner fresco richiede la sua connessione, senza owner accetta il retained tombstone con connessione non vuota. Le eccezioni compatibili per v1.2/legacy sono quelle descritte sopra. Non modifica lo stack locale.

### Tasti (con MQTT attivo)

- **ENTER**: con un owner vivo usa soltanto il comando `weigh` esatto; senza comando emette un warning. Quando non esiste più un consumer remoto, un outbox supera 10 secondi senza ACK oppure l'operatore preme ENTER mentre quell'outbox è ancora agganciato, passa immediatamente alla modalità locale anche con MQTT connesso: applica tara/push locali senza creare una seconda response. Una cattura già iniziata viene annullata se cambia contesto
- **Conferma dal Manager**: con firmware 1.4+ richiama lo stesso flusso di ENTER. La pagina non cambia ingrediente su `accepted`/`staged` né su errore; avanza soltanto dopo la persistenza durable della pesata e l'ACK end-to-end
- **SKIP breve**: scatta al rilascio e prepara `skip` per il comando attivo; senza comando emette un buzzer di avviso
- **SKIP tenuto 5 secondi**: apre il wizard calibrazione senza inviare prima uno `skip`
- **CLEAR breve**: annulla subito una voce locale; per una voce con receipt session-aware prepara `undo` e ripristina offset/zero-tracking soltanto al relativo ACK
- Finché il lock remoto è attaccato SKIP/CLEAR vengono rifiutati. Una pressione fisica di TARE/ENTER forza invece il fallback e prosegue localmente; non crea una seconda response

### Display MQTT

- **Icona MQTT** (frecce ↑↓) nella barra di stato: visibile quando il WiFi è connesso
  - Fissa: connesso al broker
  - Lampeggiante: disconnesso dal broker; il fallback locale non altera più questa icona
- **Badge modalità** compatto nella stessa barra:
  - `APP`: owner Manager fresco e modalità remota ancora agganciata
  - `LOC`: nessun Manager operativo, fallback locale oppure trasporto non disponibile
  - Il badge resta fisso: il lampeggio è riservato alla riconnessione MQTT
- **Riga info**: valori only, senza label (`WORK | STABLE` / `WORK | UNSTABLE`); in modalità LIVE mostra solo `LIVE`
- **Ingrediente**: quando arriva un comando `weigh`, il nome ingrediente è mostrato sulla riga sotto (max 15 caratteri; oltre: 15 + tre puntini ravvicinati)
- **Peso target**: quando è attivo un comando `weigh`, il peso obiettivo viene mostrato accanto all'icona target

### Disconnessione e riconnessione

- Alla disconnessione dal broker: **doppio beep** buzzer + icona MQTT lampeggiante
- Riconnessione automatica con **backoff esponenziale** (2s → 4s → 8s → 16s → 30s max)
- DNS, connessione TCP, handshake TLS, MQTT CONNECT e SUBSCRIBE sono eseguiti da un worker FreeRTOS separato con proprietà esclusiva del trasporto. Il loop principale continua quindi a campionare tastiera, HX711 e UI anche se broker o DNS non rispondono
- Il tentativo usa timeout TCP **2,5s**, handshake TLS **10s**, socket MQTT **1s** e keepalive **15s**; dopo CONNECT il timeout I/O TLS scende a **500ms** e il client passa al loop principale con un handoff atomico
- Il worker non è registrato nel WDT del loop. Sleep normale e reload credenziali ne attendono l'handoff o richiedono un abort cooperativo, senza accessi concorrenti al client
- Prima di una sospensione pulita pubblica retained `sleeping`, poi esegue DISCONNECT; il retained non resta quindi falsamente `online`. Il LWT `offline` copre le cadute impreviste.
- Comando e outbox RAM restano disponibili e, al wake, la connessione e gli eventuali retry vengono ripristinati
- Il log di sospensione (`[MQTT] Sospeso`) viene emesso solo se c'era stato MQTT attivo da chiudere, evitando spam seriale quando il WiFi e' giu

### NTP

Il firmware sincronizza l'orologio via NTP (`pool.ntp.org`) all'avvio, necessario per la validazione del certificato TLS. I tentativi di connessione MQTT sono rinviati finché il clock non è sincronizzato.

---

## 13) Weigh Stack — Stack pesate locale

Stack pesate in RAM (LIFO, max 50 elementi). Ogni voce conserva grammi, offset e zero-tracking precedenti; le pesate session-aware conservano inoltre UUID, `product_id`, sessione e `response_id` del confirm. Lo stack sopravvive al light-sleep ma viene azzerato a ogni reboot, incluso un reset WDT.

### Workflow tipico

1. Metti contenitore, premi **TARA** → avvia tara manuale; se riesce azzera stack e salva la tara di riferimento
2. Aggiungi ingrediente e premi **ENTER** sulla bilancia oppure **Conferma** nel Manager → se è già quieto accetta subito; altrimenti mostra la barra **ACQUISIZIONE PESO** fino a 1,5 s, poi accetta appena STABLE o usa il centro robusto se non c'è deriva. A quel punto applica lo zero di lavoro, registra nello stack e prepara il `confirm` MQTT
3. Ripeti per ogni ingrediente
4. **TOTAL** (breve, al rilascio) → mostra overlay di controllo con **Registrato**, **Effettivo** e **Differenza** (10 secondi)
5. **CLEAR** (breve) → annulla realmente l'ultima pesata: subito se locale, oppure dopo receipt/ACK dell'`undo` se associata a Laravel; a quel punto ripristina offset/zero-tracking e rimuove la voce LIFO
6. **CLEAR** (2 secondi) → svuota soltanto lo stack locale, senza produrre una serie di undo remoti

### Tasti

| Tasto | Breve | Lungo (2s) |
|---|---|---|
| **TARE** | Tara manuale; se riesce azzera stack e salva riferimento | — |
| **ENTER** | Valida peso + zero di lavoro + push + MQTT confirm | — |
| **TOTAL** | Al rilascio mostra overlay confronto: Registrato / Effettivo / Differenza | Con WIFI tenuto: lettura batteria |
| **CLEAR** | Avvia undo LIFO; per una voce remota applica il ripristino dello zero dopo l'ACK | Svuota solo lo stack locale |

**Note:**
- ENTER con peso <= 0: ignorato (nessun push, nessuna tara, nessun MQTT)
- ENTER con HX non OK o snapshot vecchio è ignorato. Un peso non quieto avvia invece l'acquisizione da 1,5 s; se continua a muoversi o i campioni non sono validi, il doppio beep e l'avviso auto-dismiss confermano che non è stato registrato
- ENTER e TARE in **SOVRACCARICO**: bloccati senza modificare zero, stack o MQTT
- Lo zero di lavoro post-ENTER NON azzera lo stack e NON aggiorna il riferimento
- Se la tara manuale fallisce per deriva reale o campioni insufficienti, offset, riferimento e stack restano invariati
- Le overlay si chiudono dopo 10 secondi; l'overlay TOTAL si chiude anche con TOTAL, TARE o ENTER
- Long press "solido" usato su CLEAR: l'azione breve scatta al rilascio solo se la soglia non è stata raggiunta. Il clear lungo è una manutenzione locale e non annulla in massa le azioni già persistite in Laravel.

### Comandi seriali

- `stack [status]` — mostra contatore, totale, stato riferimento
- `stack list` — lista tutti gli elementi con indice e peso
- `stack clear` — svuota lo stack

### Interazione con MQTT

- ENTER session-aware esegue: validazione → zero di lavoro → push reversibile → staging del `confirm` → associazione della receipt generata alla voce. Se lo staging non riesce, push e zero vengono annullati.
- La richiesta remota del Manager non duplica questa logica: viene consumata nel loop, rispetta lo stesso lock TARE e chiama lo stesso helper di ENTER. Un fallimento non genera `confirm`, quindi Laravel e la pagina restano sull'ingrediente corrente.
- CLEAR breve legge la voce senza rimuoverla. Se contiene una receipt remota, prepara un nuovo outbox `undo` con `undo_of_response_id`; offset/zero-tracking vengono ripristinati e la voce viene rimossa soltanto dopo l'ACK browser, quindi dopo la persistenza Laravel. Se il primo publish QoS 0 fallisce, lo stato locale resta invariato e l'outbox continua i retry.
- Una voce locale o legacy senza receipt viene annullata subito e solo localmente; non viene inventato un undo Laravel non correlabile.
- Una response in attesa continua a serializzare SKIP, CLEAR e le mutazioni del wizard. TARE ed ENTER non vengono mai scartati: la prima pressione fisica forza lo sgancio locale immediato, mentre senza input il fail-safe scatta comunque entro 10 secondi. Il payload remoto continua il retry immutabile e le mutazioni seriali/calibrazione restano serializzate sul singolo outbox.
- Il payload MQTT `clear` inviato dal browser non equivale al tasto CLEAR: pulisce soltanto UUID, target e sessione del comando retained e non modifica lo stack.

---

## 14) Troubleshooting rapido (i classici)

**DOUT sempre HIGH / letture 0 fisse**
- spesso SCK resta HIGH → HX711 in power-down
- verifica pulldown 100 kΩ su SCK e che non ci sia un level shifter “I2C” su SCK

**INA219 “non trovato”**
- SDA/SCL invertiti (errore più comune)
- indirizzo diverso da 0x40 (raro, ma possibile)

**Rumore alto a 80 SPS**
- normale: si gestisce con decimazione/filtri e con layout/cavi puliti (cella, massa, schermature se serve)

---

## 15) Firmware e cartelle

Firmware corrente (HX711):
- `firmware/esp32_hx711_serial/`

Archivio (legacy, non mantenuto):
- `archive/esp32_nau7802_serial/`

> Nota: la documentazione operativa (cablaggi, comandi seriali, DFPlayer, sleep, debug) è in questo README.

### Architettura modulare

Il firmware è organizzato in moduli con namespace C++ per una migliore manutenibilità:

```
firmware/esp32_hx711_serial/
├── esp32_hx711_serial.ino   # Main loop, comandi seriali e gestione tasti
├── config/
│   ├── config_pins.h        # Pin hardware (HX711, I2C, SPI, keypad, buzzer, DFPlayer)
│   ├── config_audio.h       # AudioConfig:: (volume, timing, tracce MP3)
│   ├── config_scale.h       # ScaleConfig:: (filtri, stati, ZT, display)
│   └── config_battery.h     # BatteryConfig:: (soglie tensione, timing shutdown)
├── audio.h / audio.cpp      # Audio:: (DFPlayer: play, coda, power-gating)
├── scale_filters.h / .cpp   # ScaleFilters:: (mediana, MA, spike guard, storico)
├── scale_state.h / .cpp     # ScaleState:: (offset, tara, stati, ZT, display)
├── dfplayer_driver.h / .cpp # DFPlayer:: (UART, comandi base)
├── buzzer.h / .cpp          # Buzzer:: (beep, toni)
├── hx711_driver.h / .cpp    # HX711 low-level (SCK/DOUT, read)
├── keypad.h / .cpp          # Keypad:: (4x2, debounce, one-shot, wake suppression)
├── battery_monitor.h / .cpp # BatteryMonitor:: (INA219, validità/freshness, charging)
├── hx_health.h / .cpp       # HxHealth:: (OK/WARN/ERROR/ERROR_HARD)
├── ui_display.h / .cpp      # UiDisplay:: (OLED SSD1322, layout, icone)
├── net_ota_cloud.h / .cpp   # Net:: (WiFi/OTA/MQTT, outbox confirm/skip/undo)
├── mqtt_store.h / .cpp      # MqttStore:: (credenziali MQTT in NVS)
├── weigh_stack.h / .cpp     # WeighStack:: (stack LIFO reversibile + receipt metadata)
└── calibration_wizard.h/.cpp # CalWizard:: (wizard calibrazione on-display)
```

**Namespace principali:**
- `Audio::` — gestione DFPlayer (coda FIFO, priorità, power-gating, anti-troncamento)
- `ScaleFilters::` — filtri segnale (mediana 3, media mobile, spike guard, storico range/slope)
- `ScaleState::` — macchina a stati (STABLE/UNSTABLE/LIVE), zero-tracking, tara, quantizzazione display
- `Net::` — WiFi/OTA/MQTT (TLS, identity eFuse, status, comandi e outbox response)
- `MqttStore::` — persistenza credenziali MQTT in NVS
- `WeighStack::` — stack pesate locale reversibile (grammi, offset/ZT precedenti, provenienza e receipt)
- `ScaleConfig::` / `AudioConfig::` / `BatteryConfig::` — parametri configurabili (soglie, timing, tracce)

### Task Watchdog
Il firmware include un **Task Watchdog** (8 secondi) attivo già durante il setup, con reset esplicito nei loop di boot intenzionali. Nel loop principale viene resettato a ogni iterazione. Il worker di connessione MQTT è separato e non è registrato nel WDT del loop, quindi DNS/TCP/TLS non richiedono di alterarne il timeout.

All'avvio il firmware verifica che il `loopTask` sia davvero iscritto al WDT: in seriale stampa `[WDT] OK` se l'aggancio e' attivo, oppure `[WDT] FAIL i=... a=... s=...` se init/add/status falliscono. Il reset periodico del watchdog viene eseguito solo dopo questa verifica.

Dopo un reset WDT la sessione runtime viene azzerata in modo coerente: stack, riferimento, offset di lavoro, zero-tracking e filtri. Nessuna tara runtime parziale viene recuperata da RTC. La UI informa del reset e avvia direttamente una nuova Auto-TARE robusta: il rumore non blocca il recupero, mentre l'assenza di campioni validi mantiene il blocco tecnico con richiesta TARE. La calibrazione persistente in NVS resta valida.

### DFPlayer Mini (audio eventi) + power-gating controllato
Il firmware può suonare file MP3 (es. avviso sleep). Per evitare click e stati strani, **non fa power-cycle a fine brano**.

Comportamento attuale:
- DFPlayer viene portato in stato **pronto** automaticamente **all’avvio** e a ogni **wake** (alimentazione ON + UART init + volume), così un suono può partire subito.
- La riproduzione MP3 è progettata per essere **non bloccante**: mentre l’audio suona, la bilancia continua a leggere HX711 e ad aggiornare UI/log.
- I comandi UART verso DFPlayer vengono inviati senza `flush()` bloccanti: se il modulo audio o UART1 si pianta, il firmware non resta fermo in attesa infinita dello svuotamento TX.
- **Gestione priorità audio**: alcuni MP3 sono **non interrompibili** e, se richiesti mentre un altro non interrompibile sta suonando, vengono messi in **coda FIFO** (solo fra loro). Tutti gli altri MP3 sono **interrompibili**: interrompono l’audio interrompibile in corso e ripartono subito, **senza accodarsi**. Se è in corso un non interrompibile, le richieste interrompibili vengono ignorate (resta il **bip** del buzzer sui tasti).
  - Non interrompibili: **0002, 0007, 0008, 0012, 0013, 0014, 0015, 0016**.
- Durante l’uso resta alimentato, salvo recovery automatico/manuale.
- Se un brano supera il timeout di riproduzione, il firmware fa un **hard reset non bloccante** del DFPlayer: chiude UART, porta GPIO2 LOW per ~800 ms, riaccende il modulo, reinizializza UART/volume e svuota la coda audio.
- **SLEEP tenuto per 2 secondi** commuta manualmente il DFPlayer:
  - da ON a OFF: chiude UART, svuota la coda, taglia VCC via GPIO2 e salva uno snapshot diagnostico;
  - da OFF a ON: esegue un power-cycle non bloccante e mostra prima `RIAVVIO MODULO...`, poi `DFPLAYER PRONTO`;
  - la scelta ON/OFF viene salvata nella NVS `minu_audio` e ripristinata dopo light-sleep, reboot e interruzioni di alimentazione; sui dispositivi senza preferenza salvata il valore predefinito resta ON.
- Il comando seriale `mp3 reset` forza lo stesso hard reset per debug da banco.
- Viene spento **quando la bilancia entra in standby/light-sleep per inattività** e anche **prima del light-sleep per batteria scarica**.

Diagnostica audio:
- un ring buffer RAM conserva gli ultimi **24 eventi** (`request`, `play`, assenza transizione BUSY, timeout, reset, ready e toggle manuali); sopravvive al light-sleep ma non a un'interruzione di alimentazione;
- al timeout e quando l'operatore passa manualmente ad AUDIO OFF viene salvato in NVS un solo snapshot compatto con stato, traccia, BUSY e comando GPIO2; non vengono eseguite scritture flash per ogni riproduzione;
- `mp3 history` stampa snapshot persistente e cronologia RAM; `mp3 history clear` cancella entrambi senza modificare la preferenza AUDIO ON/OFF;
- `mp3 status` include anche enable manuale, stato alimentazione firmware, UART e livello GPIO2.

Nota: il firmware mantiene comunque il percorso “cold-start” sul primo `mp3` (utile se in futuro vuoi tornare all’accensione on-demand).

### Collegamenti minimi
- **ESP32 GPIO4 (TX1)** → **1kΩ in serie** → **DFPlayer RX**
- **DFPlayer TX** → **ESP32 GPIO34 (RX1)** (opzionale, ma consigliato)
- **DFPlayer BUSY** → **ESP32 GPIO39**
  - BUSY è tipicamente **3.3V** (ok per ESP32)
  - GPIO39 non ha pull interni: se a riposo il segnale risulta instabile/flottante, aggiungi **pull-up 10k..47k a 3V3**
  - evita il pulldown a GND (rischi di leggere "busy" fisso)
- **Altoparlante**: usa **SPK1/SPK2** (8Ω ok)

### Power-gating (high-side) consigliato
- **ESP32 GPIO2** comanda l'alimentazione DFPlayer (HIGH=ON) tramite **NPN + P-MOSFET high-side**.

> Nota: evitiamo di usare il comando "sleep" interno del DFPlayer (0x0A) perché su molti cloni non si risveglia in modo affidabile; per risparmio batteria serio è meglio tagliare VCC.

### Bypass per test (senza MOSFET)
Per provare oggi:
- collega **DFPlayer VCC direttamente a +5V** e **GND a GND**
- lascia GPIO2 non connesso (o connesso ma senza circuito), il firmware funziona lo stesso
- in bypass il comando `mp3 reset` può reinizializzare UART/stato firmware, ma **non può tagliare davvero VCC** al DFPlayer

> Nota: non usiamo più il comando DFPlayer "sleep" (0x0A) durante i test perché su molti cloni non si risveglia in modo affidabile.
> Per il risparmio energetico vero, la strada solida è tagliare VCC con MOSFET high-side.

### Comandi seriale
- `mp3 1` (suona `/MP3/0001.mp3`)
- `mp3 1 5` (cap a 5s, solo come paracadute)
- `stop` (stop della riproduzione; **non** spegne il DFPlayer)
- `vol 20`
- `mp3 status`
- `mp3 reset` (hard reset DFPlayer via power-gate; richiede MOSFET/GPIO2 per tagliare VCC)
- `mp3 history` (snapshot persistente + ultimi 24 eventi RAM)
- `mp3 history clear` (cancella la diagnostica audio)

### Calibrazione

La bilancia può essere calibrata in due modi:
1. **Wizard on-display** — per calibrazione guidata senza PC
2. **Comandi seriali** — per calibrazione remota/debug

#### Wizard calibrazione (on-display)

Il wizard si attiva tenendo premuto **SKIP** per 5 secondi.

**Passi del wizard:**

| Step | Schermata | Azione | Tasti |
|---:|---|---|---|
| 1/4 | ZERO | Piatto vuoto, acquisisci offset | **ENTER** = conferma, **CLEAR** = annulla |
| 2/4 | PLACE | Appoggia peso di riferimento | **ENTER** = conferma, **CLEAR** = annulla |
| 3/4 | VALUE | Seleziona peso in grammi | **SKIP** = +, **TARE** = -, **ENTER** = vai a conferma |
| 4/4 | CONFIRM | Verifica CPG calcolato | **ENTER** = salva in NVS, **CLEAR** = annulla |

**Selezione peso:**
- Da 500g a 20kg
- Step di 500g sotto 2000g
- Step di 50g sopra 2000g

**Validazione:**
- Il CPG deve essere nel range 20-1000 (supporta diverse celle di carico)
- Se fuori range, il wizard rifiuta la calibrazione

**Feedback:**
- Beep singolo: conferma step
- Beep doppio + schermata **SALVATA**: calibrazione scritta e riletta da NVS
- Schermata **ERRORE**: salvataggio o verifica NVS fallita
- Doppio beep basso: errore/annullato

#### Calibrazione via seriale

Per calibrazione remota o debug:

- `cal status` — stampa offset, CPG, ZT counts, grammi attuali
- `cal zero` — imposta il valore raw corrente come nuovo offset (tara "permanente")
- `cal ref <grammi>` — con un peso noto posizionato, calcola il nuovo CPG
- `cal save` — salva offset e CPG in NVS e segnala errore se `Preferences` fallisce
- `cal load` — ricarica offset e CPG da NVS

**Procedura di calibrazione seriale:**
1. Bilancia vuota, esegui `cal zero`
2. Posiziona un peso noto (es. 500g), esegui `cal ref 500`
3. Verifica con `cal status` che i grammi siano corretti
4. Salva con `cal save`

**Note:**
- `cal zero` e `cal ref` sono disabilitati se HX health è in ERROR
- tara/calibrazione sono bloccate durante **SOVRACCARICO**
- `cal ref` rifiuta valori ≤ 0 e CPG fuori range 20-1000
- Dopo `cal zero` o `cal ref` i filtri vengono resettati automaticamente
- dopo WDT viene ricaricata la calibrazione NVS senza applicare una tara runtime RTC

### Legenda MP3 eventi (cartella /MP3)
Metti i file in **SD:/MP3/** con nome a 4 cifre (es. `0001.mp3`).

| File | Evento |
|---:|---|
| 0001.mp3 | Avvio bilancia |
| 0002.mp3 | Boot completato |
| 0003.mp3 | Entrata risparmio energetico (standby manuale o automatico: schermata Zzz... 5s prima del light-sleep) |
| 0004.mp3 | Uscita risparmio energetico (wake) |
| 0005.mp3 | Wi‑Fi **modulo ON** (toggle manuale) |
| 0006.mp3 | Wi‑Fi **modulo OFF** (toggle manuale) |
| 0007.mp3 | Errore connessione Wi‑Fi (connect failed / SSID non disponibile, con cooldown) |
| 0008.mp3 | Connessione Wi‑Fi avvenuta (anche in background) |
| 0011.mp3 | Batteria bassa (una sola volta all'ingresso in 0 tacche, beep resta attivo) |
| 0012.mp3 | Batteria critica (una sola volta all'ingresso fase critica, beep resta attivo) |
| 0013.mp3 | Standby pre‑sleep per batteria scarica (schermata Zzz... 5s prima del light-sleep) |
| 0014.mp3 | Errore lettura batteria (INA) |
| 0015.mp3 | Errore sensore peso (HX) |
| 0016.mp3 | Tara non eseguita, riprovare (errore tecnico al boot o movimento reale nella tara manuale; il buzzer suona comunque) |
| 0017.mp3 | Modalità WORK |
| 0018.mp3 | Modalità LIVE |

### Debug seriale HX711 (opzionale)
Di default il log continuo del sensore è disattivato.

Nota: il parser comandi seriali è **non bloccante** (nessun timeout/attesa). I comandi vengono eseguiti solo quando invii una riga completa (terminata da invio). 
Comandi:
- `hxlog on` / `hxlog off`
- `hxlog ?`
- `hxlog rate <ms>` (50..5000)

### Tastiera: debounce + one-shot + long press
La tastiera ha un debounce software (40 ms) e genera eventi **one-shot**: una pressione produce **un solo evento**, anche se tieni premuto il tasto. **WIFI e TOTAL agiscono al rilascio**, così possono essere premuti insieme per la lettura batteria senza attivare le rispettive azioni singole.

Se un tasto o una linea resta chiusa per almeno 15 secondi, quel tasto viene soppresso fino al rilascio elettrico: il loop continua a girare e gli altri tasti restano leggibili.

Dopo un wake il tasto che ha risvegliato la bilancia resta soppresso fino al rilascio: il wake non genera una seconda azione applicativa. Se il wake o la protezione da tasto bloccato coinvolgono WIFI/TOTAL, viene consumata l'intera coppia fino al rilascio completo.

**Combinazione batteria:** tenere **TOTAL + WIFI** per leggere volt e mA; rilasciare per tornare alla pesata. Dettagli e limiti della misura nella sezione 8.1.

**Long press:**
- **SKIP breve**: l'azione scatta al rilascio
- **SKIP tenuto per 5 secondi**: avvia il wizard di calibrazione on-display senza eseguire prima lo SKIP breve/MQTT
- **CLEAR breve**: al rilascio avvia l'undo LIFO reale
- **CLEAR tenuto per 2 secondi**: svuota soltanto lo stack locale, senza undo Laravel multipli
- **SLEEP breve**: entra in standby al rilascio
- **SLEEP tenuto per 2 secondi**: commuta DFPlayer AUDIO OFF/ON, salva il log quando passa a OFF e annulla lo standby

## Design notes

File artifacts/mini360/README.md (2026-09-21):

# Alimentazione montata: batteria USB-C e Mini360 DAOKAI

Configurazione montata con batteria USB-C NASTIMA e convertitore DAOKAI, Amazon ASIN **B0B82GL5XN**, con integrato **MP1482DS identificato nella foto dell'esemplare**. Andrea conferma cablaggio completato e primo funzionamento apparentemente regolare il **18 settembre 2026**. Uscita regolata a **5,11 V**, valore ottenuto e riferito da Andrea; il riferimento nominale resta una linea a 5 V. Nessuna modifica o caricamento del firmware eseguiti per questo montaggio.

Il task di cablaggio e documentazione è completato. La conferma di funzionamento è una prova pratica iniziale; non sono riportate misure di autonomia, stabilità con Wi-Fi/audio, temperatura, transitori USB o recupero dopo intervento del BMS.

## Tavole

- [1 — Alimentazione, positivo/GND, fusibile e condensatori (PNG)](./01-alimentazione-mini360.png) · [SVG ingrandibile](./01-alimentazione-mini360.svg)
- [2 — Pad reali del retro, regolazione e INA219 (PNG)](./02-pad-regolazione-ina219.png) · [SVG ingrandibile](./02-pad-regolazione-ina219.svg)
- [3 — Condensatori sui morsetti di ingresso e uscita (PNG)](./03-condensatori-mini360.png) · [SVG ingrandibile](./03-condensatori-mini360.svg)

Le tre tavole rappresentano gli stessi componenti. I blocchi delle tavole 1 e 3 sono funzionali, non viste fisiche dei piedini. La tavola 2 riproduce l'orientamento del **retro** mostrato nell'immagine originale del venditore: scritta MINI-360 dritta, freccia a sinistra; OUT− in alto a sinistra, OUT+ in basso a sinistra, IN− in alto a destra, IN+ in basso a destra. La tavola 3 ingrandisce soltanto i collegamenti dei quattro condensatori.

## Batteria e ricarica

La batteria USB scelta per il montaggio è la NASTIMA **BK06-LF60-NATC**, ASIN **B0FDB3VWDF**, LiFePO4 **6,4 V nominali / 6 Ah**, con BMS e caricatore USB-C interni. «6 V» è la denominazione commerciale del pacco; la configurazione montata non usa la precedente SLA con CTK3S.

La ricarica usa l'ingresso USB-C del pacco attraverso il collegamento femmina da scocca → maschio interno. Il limite dichiarato dell'ingresso è **5 V / 1,5 A (7,5 W)**; un alimentatore con maggiore potenza nominale non aumenta questo limite. Il ramo di potenza esterno usa i morsetti del pacco. Non applicare direttamente i 5 V USB ai morsetti batteria. La prova iniziale riferita non documenta separatamente il funzionamento durante ricarica o l'avvio dopo stacco del BMS.

## Collegamenti del ramo di potenza

| Da | A |
|---|---|
| Morsetto positivo batteria | F1 vicino alla batteria → VIN+ INA219 |
| VIN− INA219 | Interruttore semplice S1 → IN+ Mini360 e positivo di C1/C2 |
| Morsetto negativo batteria | IN− Mini360 e negativo comune |
| OUT+ Mini360 | Linea 5 V di tutti i carichi |
| OUT− Mini360 | Negativo comune/GND |
| Linea 5 V | ESP32 VIN/5V, HX711 VCC, OLED compatibile 5 V e circuito audio esistente |
| GND comune | ESP32, HX711, OLED, INA219 e circuito audio |
| VCC INA219 | 3V3 ESP32 |
| SDA INA219 | GPIO32 ESP32 |
| SCL INA219 | GPIO33 ESP32 |

**VIN− dell'INA219 è ancora sul positivo; non è GND.** Il suo shunt è prima del buck, così la tensione misurata resta quella del ramo batteria. Il circuito audio conserva il power-gate esistente: GPIO2 non alimenta direttamente il DFPlayer.

**S1 è l'interruttore semplice ON/OFF, posto sul positivo dopo VIN− dell'INA219 e prima di IN+ del Mini360 e di C1/C2.** In OFF interrompe l'alimentazione del buck dalla batteria. OUT+ rimane collegato alla linea 5 V dell'ESP32 e delle periferiche; la massa resta comune. Gli ingressi di misura dell'INA219 restano sul ramo batteria anche quando il suo VCC è spento: il datasheet TI ammette questa condizione (§8.3.1). La ricarica USB interna del pacco rimane indipendente da S1. I contatti di S1 devono avere una portata DC adatta alla corrente del ramo batteria.

| Posizione di un interruttore semplice | Effetto in OFF |
|---|---|
| Prima del Mini360, come disegnato | Toglie il consumo del buck dalla batteria; lascia la sua uscita collegata all'ESP32. |
| Dopo il Mini360, sul positivo di tutti i carichi | Separa il buck dalla linea ESP32/USB; lascia il buck alimentato dalla batteria. |

**USB del PC collegata all'ESP32:** se i 5 V USB raggiungono il pin VIN/5V della scheda, raggiungono anche OUT+ del Mini360. Con S1 OFF possono rialimentare internamente il convertitore e il suo ingresso; S1 aperto impedisce a questo percorso di raggiungere il positivo della batteria. Il circuito USB/VIN dell'esatta scheda ESP32 e il comportamento del Mini360 in questa condizione non sono stati verificati. OFF, da solo, non garantisce quindi isolamento dall'USB del PC. Con S1 ON, l'interruttore non separa le due sorgenti di alimentazione.

Applicare 5 V all'uscita non costituisce di per sé una sovratensione su un'uscita regolata a 5 V. L'eventuale ritorno di corrente non implica automaticamente un danno: l'effetto dipende dal circuito e dalla corrente. Per isolare il Mini360 durante la programmazione senza dipendere dalle protezioni non verificate, occorre separare fisicamente OUT+ dalla linea 5 V dei carichi, a circuito disalimentato. Il semplice cablaggio disegnato non realizza tale separazione automaticamente.

L'USB di ricarica del pacco è un collegamento diverso dall'USB del PC sull'ESP32: entra nel caricatore interno della batteria. In OFF viene eliminato l'assorbimento del Mini360 dalla batteria; restano le funzioni interne al pacco (BMS e caricatore). Non si dichiara quindi consumo totale nullo della batteria.

F1 **T2 A** è il valore progettuale proposto per cablaggio corto di potenza in rame di almeno **0,5 mm²**; valore effettivamente montato e spunti non sono stati riferiti separatamente. Usare portafusibile isolato e rating DC idoneo. Non è una misura della corrente della bilancia o una garanzia di protezione dei semiconduttori del buck.

Condensatori ripresi dalle indicazioni già presenti nel README del progetto:

| Lato del Mini360 | Componente | Collegamenti |
|---|---|---|
| **Ingresso** | C1, elettrolitico **220 µF / 16 V** | + a IN+, − a IN− |
| **Ingresso** | C2, ceramico **100 nF** | Tra IN+ e IN−, in parallelo a C1; senza polarità |
| **Uscita** | C3, elettrolitico **470 µF / 10 V** | + a OUT+, − a OUT− |
| **Uscita** | C4, ceramico **100 nF** | Tra OUT+ e OUT−, in parallelo a C3; senza polarità |

**Saldare ogni coppia il più vicino possibile ai rispettivi pad del Mini360**, direttamente sulla schedina se c'è spazio oppure subito accanto con collegamenti corti. In particolare, il ceramico deve avere un percorso corto fra positivo e negativo. Le distanze nelle tavole servono solo alla leggibilità: non indicano di collocare C1/C2 presso l'INA219 o C3/C4 presso l'audio. I condensatori sono in parallelo all'alimentazione, mai in serie sul filo positivo. C1/C2 sono entrambi dopo S1.

100 nF = 0,1 µF, spesso marcato **104**. Sugli elettrolitici la banda con il simbolo − indica il terminale negativo. Non rimuovere i condensatori già montati sul Mini360. Riutilizzare gli eventuali condensatori esterni già presenti se idonei, senza duplicarli automaticamente.

Sul montaggio Andrea ha posizionato **prima il ceramico di uscita, più vicino al Mini360, poi l'elettrolitico**. È coerente con lo schema: entrambi sono collegati agli stessi OUT+ e OUT−, in parallelo.

Vicino all'ESP32 rimangono i condensatori locali già previsti: **10–47 µF + 100 nF** fra VIN/5V e GND. Servono nel punto di alimentazione dell'ESP32 e non sono ripetuti come nuovi componenti nelle tavole.

## Regolazione del convertitore

**Regolazione del montaggio: 5,11 V riferiti da Andrea.** Non è stato riferito un collaudo strumentale delle variazioni a vuoto, con Wi-Fi/audio e durante le commutazioni. La procedura seguente mantiene il riferimento nominale di 5,00 V per una futura regolazione; non richiede di modificare il montaggio funzionante per inseguire il centesimo.

1. Con PC scollegato, lasciare il filo **OUT+ → linea 5 V dei carichi fisicamente staccato e isolato**. Il carico non deve essere collegato al buck ancora da regolare.
2. Collegare correttamente IN+ e IN− tramite il ramo F1 → INA219 → S1, poi portare S1 su ON per alimentare il convertitore.
3. Misurare direttamente OUT+ rispetto a OUT− con tester in volt DC e ruotare a piccoli passi il trimmer fino a **5,00 V**.
4. Portare S1 su OFF e scollegare la batteria prima di completare la saldatura del filo OUT+ verso i carichi. Nessuna saldatura a circuito alimentato.
5. Ricollegare la batteria, chiudere S1 e verificare la tensione anche con Wi-Fi e audio attivi. Se la tensione scende perché manca margine in ingresso, non compensare aumentando arbitrariamente il trimmer.
6. Fissare il modulo con supporto isolante; nessun pad o saldatura deve toccare la scocca metallica.

È un **buck**, non un buck-boost: non può mantenere 5 V regolati quando l'ingresso si avvicina a 5 V. Il chip **MP1482DS**, leggibile sui moduli fotografati, ha un ingresso operativo di **4,75–18 V** e una corrente d'uscita nominale dell'integrato di **2 A**. La minima tensione d'ingresso non garantisce 5 V in uscita a quel valore. Le specifiche commerciali generiche 23 V / 3 A non qualificano questo esemplare; i 2 A del chip non certificano la corrente continua sostenibile dalla schedina nel vano. Restano da misurare margine d'ingresso e comportamento termico con il carico reale. I limiti del chip non sostituiscono quelli degli altri componenti, inclusi i condensatori esterni.

## Monitoraggio quando la ricarica è interna al pacco

Con la NASTIMA, la corrente USB entra nel pacco internamente e non attraversa l'INA219 posto sui morsetti di uscita: questo cablaggio misura **la corrente diretta al buck**, non la corrente netta delle celle. Il firmware stima `charging` dalla tensione filtrata: ON a **≥ 6,70 V per 5 s**, OFF a **≤ 6,68 V per 10 s**, stato conservato nella banda intermedia. Campioni invalidi/scaduti azzerano indicazione e timer. Le soglie sono basate sulle letture riferite da Andrea: **l'icona non prova la presenza USB o la ricarica**, che a batteria bassa può essere attiva senza raggiungere 6,70 V. Le tacche usano fasce indicative LiFePO4, non percentuali calibrate.

Avvisi sonori e protezioni restano attivi anche con l'icona accesa. Il countdown parte a **≤ 5,80 V dopo 5 s**, dura **120 s**, poi mostra **Zzz per 5 s** prima del light-sleep; la soglia hard-low **≤ 5,70 V per 3 s** può anticiparlo. Soglie e tempi restano indipendenti dalla mappa delle tacche. Il light-sleep non scollega fisicamente il Mini360. Soglie e comportamento corrente sono nel [README principale](../../README.md#8-monitoraggio-batteria-ina219).

## Analisi e verifica del ritorno dall'USB del PC

**Identificazione:** nella foto fornita da Andrea si legge **MP1482DS** sui moduli centrale e destro. La marcatura corrisponde a quella prevista dal datasheet MPS. La foto mostra il fronte, con integrato, induttore, trimmer e passivi; non costituisce una verifica della continuità completa delle piste o del lato posteriore.

Nel datasheet originale MP1482, pagina 2, i massimi assoluti sono **21 V sul nodo SW** e **20 V su VIN**. Applicare 5 V all'uscita non dimostra di per sé il superamento di questi limiti. Il limite massimo operativo di VIN è invece 18 V: un massimo assoluto non è una tensione d'impiego.

Nel circuito applicativo MPS, OUT è collegato a SW attraverso l'induttore. La struttura del MOSFET superiore permette il percorso `OUT+ → induttore → SW → diodo interno → IN+`. IN aperto non è fissato a zero: può caricarsi dal lato OUT. La soglia di avvio per sottotensione è **4,10 V tipici** (3,80–4,40 V), pagina 3; il circuito applicativo prevede una resistenza di pull-up da 100 kΩ su EN. Da questi dati si deduce che una sorgente esterna sull'uscita può anche riattivare il regolatore. È un'inferenza circuitale, non una misura sull'esemplare. Il datasheet non garantisce questa modalità né consente di concludere che un guasto sia inevitabile. La limitazione di corrente del MOSFET basso non equivale all'isolamento OUT/IN.

**Rilevanza pratica:** la sola rialimentazione del Mini360 non è un difetto. Se tensioni, corrente e temperatura rimangono accettabili, il suo assorbimento dal PC può essere irrilevante per l'uso previsto. Va distinto questo caso dal trasferimento attivo di energia verso IN. La nota TI SLYT689, sezione 6, descrive quest'ultimo nei buck in PWM forzato quando l'uscita esterna supera il riferimento e il lato ingresso non assorbe l'energia. L'analisi del controllo MP1482 rende questo comportamento pertinente da verificare, senza dimostrarlo sull'esemplare.

Le fonti consultate includono una prova strumentale del DSN-MINI-360 con MP1482DS pubblicata da Gough: misura un assorbimento a vuoto di circa 3–12,5 mA nelle condizioni provate, alimentando IN. Non misura il ritorno alimentando OUT, quindi quei numeri non sono una previsione dell'assorbimento dall'USB. Sul forum ufficiale MPS, una discussione sul Nano Every riporta 4,65 V applicati a OUT e 5,46 V misurati a IN: è un esempio concreto di rialimentazione attiva, ma riguarda MPM3610 e non MP1482. Nelle fonti pubbliche consultate non è emersa una prova specifica di MP1482 con OUT a 5 V e IN aperto che ne quantifichi corrente e transitori.

**Prima misura, sul solo ESP32:**

1. Con tutte le sorgenti scollegate, separare la batteria e il filo OUT+ del buck dalla linea 5 V della scheda. Lasciare l'ESP32 senza altre alimentazioni esterne.
2. Alimentare l'ESP32 soltanto dalla sua USB.
3. Usare il multimetro in volt DC, puntale nero su GND e rosso sul pin VIN/5V, senza cortocircuitare pin adiacenti.
4. Una lettura prossima a 5 V dimostra la presenza della tensione USB su quel pin nelle condizioni della prova. Collegare il buck a quel pin esporrebbe anche OUT+ a tale tensione. La misura non caratterizza il buck né i transitori; una lettura nulla non certifica da sola ogni stato della scheda.

Per caratterizzare il Mini360 servono modulo isolato, sorgente da banco con limitazione di corrente e osservazione delle tensioni e della corrente, incluse le transizioni. La sola limitazione di corrente non esclude una sovratensione su IN generata da un convertitore sincrono. Una prova di accensione prolungata dall'uscita, usando direttamente il PC, non è un criterio di validazione. Il multimetro può rilevare il ritorno a regime; per escludere picchi e commutazioni indesiderate serve anche un oscilloscopio. Non sono riportate queste misure specifiche; la prima prova positiva della bilancia non viene estesa a una caratterizzazione del ritorno USB.

## Fonti e riproduzione

- [Prodotto indicato da Andrea](https://www.amazon.it/dp/B0B82GL5XN).
- [Immagine originale DAOKAI con i quattro pad e la vista del retro](https://m.media-amazon.com/images/I/71XIQphK08L._US500_.jpg).
- [Descrizione DAOKAI e galleria riportate dal distributore](https://snapklik.com/en-ca/product/daokai-10pcs-mini-360-power-supply-buck-module-dc-to-dc-adjustable-buck-converter-4-75-23v-to-1-0-17v-ultra-small-step-down-voltag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).
- [Manuale originale della NASTIMA USB-C](https://m.media-amazon.com/images/I/91H3v%2BEZy2L.pdf).
- [Texas Instruments: effetti generali dell'alimentazione applicata all'uscita di un buck spento](https://www.ti.com/document-viewer/lit/html/SSZTAG7/GUID-A966A819-DB0C-4D5D-AA2C-345810AA0674). Non è una caratterizzazione del Mini360 specifico.
- [Foto dell'esemplare fornita da Andrea](../../.codex-remote-attachments/01a0916e-df51-71a3-a685-71b7142ab0dd/86ad795f-8b1d-4ca9-9806-ef48b400f0ee/1-Photo-1.jpg): marcatura MP1482DS.
- [Datasheet originale MPS MP1482, revisione 1.31](https://www.monolithicpower.com/en/documentview/productdocument/index/version/2/document_type/Datasheet/lang/en/sku/MP1482/document_id/344/), pagine 2–6 e circuito applicativo a pagina 11.
- [Gough: prova strumentale DSN-MINI-360 con MP1482DS](https://goughlui.com/2025/09/30/tested-dsn-mini-360-mp1482-based-2a-buck-converter-module-4-5-18v-in/): funzionamento normale, non prova del ritorno da OUT.
- [MPS: MPM3610 su Arduino Nano Every alimentato da USB](https://forum.monolithicpower.com/t/mpm3610-in-arduino-nano-every/1284): caso analogo con integrato diverso.
- [TI SLYT689: alimentare l'uscita senza alimentazione all'ingresso](https://www.ti.com/lit/an/slyt689/slyt689.pdf): sezioni 2, 3 e 6 distinguono assorbimento e funzionamento inverso attivo.
- [Pinout attuale della bilancia](../../docs/WIRING.md).
- [Datasheet Texas Instruments INA219](https://www.ti.com/lit/ds/symlink/ina219.pdf), §8.3.1: tensione sul bus ammessa anche con alimentazione VCC spenta.

Rigenerare con `python artifacts/mini360/draw_wiring.py`, poi `node artifacts/mini360/render.cjs`. Il renderer usa Sharp dal runtime locale configurato; aggiornare il percorso se il runtime cambia.

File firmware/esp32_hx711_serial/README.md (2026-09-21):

# esp32_hx711_serial — Firmware HX711 (ESP32)

Le fonti canoniche sono mantenute nella root del repository:

- `../../README.md` — comportamento firmware, comandi, MQTT, build e diagnostica.
- `../../docs/WIRING.md` — pinout e cablaggio fisico.

## Alimentazione montata e configurazione firmware

La bilancia usa la batteria USB-C NASTIMA LiFePO4 e il Mini360 MP1482DS, con uscita regolata a **5,11 V** e primo funzionamento positivo riferito da Andrea. Le tacche usano fasce indicative LiFePO4 definite in `config/config_battery.h`. L'icona `charging` usa la tensione filtrata: ON a **≥ 6,70 V per 5 s**, OFF a **≤ 6,68 V per 10 s**, stato conservato nella banda intermedia, senza un tempo minimo acceso aggiuntivo. Campioni invalidi/scaduti azzerano indicazione e timer. La corrente INA219 è quella del carico: la ricarica interna USB non attraversa lo shunt esterno. Queste soglie, scelte dalle letture riferite, non provano la presenza USB o la carica residua; a batteria bassa la ricarica può essere attiva senza raggiungerle. Avvisi sonori, countdown e protezioni conservano soglie e tempi e restano attivi anche con `charging` acceso. Soglie effettive e limiti sono nel [README principale](../../README.md#8-monitoraggio-batteria-ina219); percorso elettrico in [WIRING](../../docs/WIRING.md#9-alimentazione-e-masse).

**Lettura batteria:** tenere premuti **TOTAL + WIFI** per visualizzare tensione e corrente INA aggiornate; rilasciare per chiudere. I tasti singoli WIFI/TOTAL agiscono al rilascio e vengono consumati dalla combinazione. Campioni invalidi/scaduti non vengono mostrati; safety, TARE, ENTER e calibrazione hanno priorità. La schermata è diagnostica e non modifica soglie o rilevamento ricarica. Dettagli nella [sezione INA219](../../README.md#81-collegamenti-ina219).

## Riferimento rapido MQTT firmware 1.5.2

- Un `weigh` può includere `command_id` (8–64 caratteri; lettere ASCII, cifre, `-`, `_`; vuoto solo per legacy). Il firmware lo memorizza con UUID, prodotto, `session_id` e `connection_id`. Se quest'ultima è presente, il comando diventa operativo soltanto con l'owner retained fresco ed esatto e, dopo reconnect, dopo avere processato anche lo snapshot retained `command` corrente.
- Dopo l'attivazione di un comando tokenizzato e solo quando è realmente azionabile pubblica sul topic `response` un `command_ack` transitorio con `command_id`, `session_id`, `connection_id`, UUID, prodotto e `state=active`. Fallback `LOC`, TARE obbligatoria e convergenza owner/command incompleta non producono ACK. Un replay identico dello stesso ID non reinizializza la pesata, ma riaggancia un eventuale fallback locale, aggiorna la connessione corrente e riemette l'ACK. Un payload business conflittuale viene ignorato senza ACK.
- Il Manager può pubblicare sul topic `command`, QoS 1 e non retained, una `confirm_request` fenced da `request_id`, sessione, connessione, comando, UUID e prodotto. Il loop la esegue tramite lo stesso helper e lo stesso lock TARE di ENTER fisico. Lo stesso request ID non ripete l'azione; una cache RAM mantiene gli ultimi due esiti terminali anche se il relativo ACK si perde. `accepted`/`staged` non avanzano la pagina e `failed`/`rejected` lasciano attivo l'ingrediente corrente.
- Un `clear` live cancella un comando moderno solo se coincidono `command_id` e `session_id`: con owner fresco richiede la connessione corrente, mentre senza owner accetta il retained tombstone esatto. Al reconnect il primo retained clear moderno è invece lo snapshot autorevole del broker e pulisce il raw RAM anche se la coppia è già avanzata. La stessa fingerprint comando/connessione chiude inoltre l'attesa owner se il weigh era stato respinto prima di entrare nel raw RAM, senza modificare l'outbox. Il clear speciale `lifecycle=pagehide` sgancia l'owner corrente anche senza comando; cancella il raw solo se coincide anche la fence comando. Un comando v1.2 senza ID richiede la stessa sessione; un comando realmente legacy senza sessione accetta il clear senza ID del Manager nuovo.
- Una response durable `confirm` o `skip` conserva il `command_id` originale. L'`undo` usa `undo_of_response_id` e non inventa un nuovo command ID.
- Se l'owner scade, un comando moderno viene conservato raw in RAM ma reso non operativo e non visibile. Da 1.4.2 la bilancia passa alla modalità locale: TARE e ENTER fisici funzionano senza creare nuove response MQTT; un nuovo `weigh` valido riaggancia il Manager. Da 1.4.4 il loop elabora prima un burst limitato a quattro pacchetti MQTT già disponibili e soltanto dopo valuta la scadenza. Da 1.5.0 la presenza usa 25 secondi dall'arrivo di un owner valido, tollerando un heartbeat da 10 secondi saltato. Solo un timestamp strettamente avanzato sullo stesso lease, con età entro 10 secondi, ottiene fino a 5 secondi di clock/jitter grace; replay uguali e lease scaduti non vengono estesi. Da 1.5.2 il takeover da `LOC` non dipende più dal confronto tra epoch tablet ed ESP32: una nuova connessione/lease diventa un candidato inattivo e soltanto un secondo heartbeat con timestamp strettamente avanzato sulla stessa generazione prova che il tablet è vivo. Gli snapshot retained iniziali e i replay uguali non diventano freschi.
- Il watchdog passivo valida le subscription con i soli owner heartbeat, retained command ed esiti ACK già previsti dal protocollo. Non pubblica probe sui topic business e non richiede nuove ACL. Da 1.5.1 un messaggio `command` ricevuto prova il canale anche quando il suo stato non coincide ancora con `expected_command_id`: la bilancia resta non azionabile fino alla convergenza, ma non risottoscrive né riconnette un socket sano. Un `weigh` moderno valido arrivato prima dell'owner esatto apre una grace owner monotona e deduplicata per comando/connessione; un successivo PUBLISH owner prova il topic anche se il payload è business-divergente. Solo la vera assenza avvia le subscribe bounded ogni 2,5 secondi e al massimo un reconnect per fingerprint; al secondo esaurimento resta `LOC` senza socket churn. L'evidenza owner deve appartenere al trasporto corrente e nuovi ID durante una grace non ne prorogano la scadenza. La grace command parte dal cambio effettivo dell'aspettativa e non viene estesa da heartbeat uguali. Un owner fresco con `expected_command_id=""` pulisce autorevolmente il raw RAM anche senza retained clear, salvo response o `confirm_request` pendenti, e ignora weigh tardivi finché attende clear. Manager legacy senza il campo resta invariato. Per la stessa response l'ACK timeout causa un solo reconnect e resta diagnosticato come `ack_timeout`.
- L'outbox durable resta immutabile e continua il retry ogni secondo fino al `response_ack` esatto o al terminale `response_reject/manager_incident`, ma non può bloccare indefinitamente l'operatore. Il lock fisico dura al massimo 10 secondi, termina prima su `clear` con `lifecycle=pagehide`/perdita owner e viene sganciato immediatamente dalla prima pressione fisica di TARE o ENTER. Un owner/snapshot remoto mai ricevuto usa la stessa grace. DNS, TCP, TLS e MQTT CONNECT vengono eseguiti da un worker FreeRTOS separato: il loop continua sempre a campionare tastiera e bilancia. TARE/ENTER diventano locali; SKIP/CLEAR remoto e nuovi outbox restano serializzati. Un `confirm` quarantinato viene rollbackato una sola volta solo con receipt esatta ancora in testa e operatore non sganciato; altrimenti la cronologia viene invalidata, senza fake success, undo o ACK. Un undo rifiutato prima del detach non cambia lo stack; se era già stato applicato localmente, il firmware invalida stack/riferimento, mostra `SYNC ERROR` e attiva lo stesso gate cross-layer. Lo status espone `tare_required=true`, resta `operational_mode=local` e conserva un eventuale comando raw senza renderlo azionabile o ACKarlo. Solo una TARE fisica riuscita rimuove entrambi i gate e consente allo stesso comando valido di riattivarsi con un singolo `command_ack`.
- Lo status retained viene aggiornato ogni 5 secondi con epoch, boot/transport ID, sequenza, modalità, `tare_required`, causa fallback, ultimo errore, mask owner/command/ack e response pending. Il buffer PubSubClient runtime è 640 byte; il Manager limita `user_name` owner a 48 byte UTF-8 e gli ID a 64 caratteri.
- Rollout base 1.5 raccomandato: prima il firmware, poi Manager/backend che pubblicano/interpretano i nuovi campi e possono emettere `response_reject`. Per le patch 1.5.1/1.5.2 su un impianto già 1.5.0, distribuire prima il bundle Manager con recovery owner fenced a doppia prova e poi aggiornare la bilancia. Il firmware precedente tollera la seconda pubblicazione; il firmware 1.5.2 la usa per rimuovere la dipendenza dall'epoch locale durante il takeover da `LOC`. Non serve modificare le ACL MQTT della bilancia.
- Con un owner vivo ENTER richiede un comando attivo. Senza consumer remoto usa il percorso standalone anche se MQTT è ancora connesso; con MQTT disconnesso e un comando remoto non ancora dichiarato stale attende al massimo la stessa finestra di 10 secondi.
- La barra OLED separa il trasporto dalla modalità operativa: le frecce MQTT sono fisse quando il broker è connesso e lampeggiano soltanto durante la disconnessione; il badge compatto `APP` indica un owner Manager fresco, mentre `LOC` indica fallback/standalone. Il badge non lampeggia.
- Se ENTER arriva prima della quiete, il firmware emette un beep basso e mostra **ACQUISIZIONE PESO** per massimo 1,5 s. Registra appena raggiunge STABLE; al timeout accetta il centro RAW robusto solo senza deriva continua e usa lo stesso centro per peso e zero. Movimento persistente o campioni non validi producono doppio beep e un avviso leggibile; successo e fallimento si chiudono automaticamente dopo circa 1,3 s e 2 s.

Verifica locale:

```sh
c++ -std=c++17 -Wall -Wextra -Werror tests/firmware_mqtt_protocol_harness.cpp -o /tmp/firmware_mqtt_protocol_harness
/tmp/firmware_mqtt_protocol_harness
arduino-cli compile --fqbn esp32:esp32:esp32 firmware/esp32_hx711_serial
```

Il test batteria compila il monitor reale con letture INA219 simulate e verifica soglie, tempi, isteresi e interruzioni dei campioni. Dalla root, nel Developer Command Prompt MSVC (output fuori dal repository):

```bat
if not exist "%TEMP%\minu-battery-harness" mkdir "%TEMP%\minu-battery-harness"
cl /nologo /std:c++17 /EHsc /W4 /I tests\battery_stubs tests\firmware_battery_harness.cpp firmware\esp32_hx711_serial\battery_monitor.cpp /Fe:"%TEMP%\minu-battery-harness\firmware_battery_harness.exe" /Fo:"%TEMP%\minu-battery-harness/"
"%TEMP%\minu-battery-harness\firmware_battery_harness.exe"
```

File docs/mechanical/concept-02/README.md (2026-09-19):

# Minù — Proposta meccanica 02

**Stato economico:** questo assieme richiede quattro parti in alluminio su misura e non è la soluzione consigliata per il singolo prototipo economico. La [valutazione corrente](../prototype-affordability/README.md) propone un gruppo di pesatura commerciale e nuove plastiche FDM; i suoi innesti non sono rappresentati negli STEP/STL di questa cartella o nello ZIP Concept 02.

**Alimentazione installata:** batteria USB NASTIMA BK06-LF60-NATC LiFePO4 6,4 V / 6 Ah e Mini360 MP1482DS, con uscita regolata da Andrea a 5,11 V e primo funzionamento riferito positivo. Il gruppo Waveshare rappresentato in questo CAD resta una variante meccanica non installata. Per il cablaggio corrente vedere [WIRING](../../WIRING.md) e per il comportamento firmware il [README principale](../../../README.md).

Prototipo parametrico per una bilancia con **20 kg di carico utile di progetto**, scocca e piatto esterno in plastica, fondo interno piano e supporto del piatto in alluminio. Il pacchetto contiene l'assieme STEP con componenti separati, i pezzi custom STEP/STL, la distinta di acquisto e le note di montaggio. È una base concreta per il prototipo: la portata, gli accoppiamenti stampati e il funzionamento della ricarica non sono ancora collaudati fisicamente.

## Geometria e materiali

| Elemento | Scelta di progetto |
|---|---|
| Corpo | **300 × 320 × 81 mm**, altezza con piedi nella posizione nominale; la presa USB porta la larghezza complessiva a circa **312 mm** |
| Piatto esterno | **280 × 200 × 4 mm**, plastica PA12 proposta, spigoli raccordati R20 |
| Portapiatto | **276 × 196 × 8 mm**, alluminio 6061-T6, supporto quasi continuo della plastica |
| Fondo | **300 × 320 × 6 mm**, alluminio 6061-T6, superficie superiore piana |
| Guscio | PA12 MJF/SLS, pareti nominali 3 mm; rimovibile dal basamento |
| Cella | Zemic L6D-C3-30kg-0.4B, corpo 130 × 30 × 22 mm; capacità nominale 30 kg per lasciare margine al piatto e al supporto |
| Piedi | 4 Elesa D30, centri X ±132 / Y ±142 mm, regolazione M6 e controdado |
| Comandi | 2 tastierini adesivi BerryBase B-SM4T da 4 tasti, totale **8 tasti** |
| Display | Riutilizzo dell'**OLED SSD1322 SPI 256×64, 3,12 pollici** documentato nel progetto; cornice separata e sostituibile |
| Ricarica proposta | USB-C laterale Premier PCM-0726, verso modulo Waveshare UPS HAT(D) con due 21700 |

Il fondo non ha una griglia di nervature. Sono presenti soltanto i fissaggi funzionali: cella, piedini, fermi di sovraccarico e vassoi rimovibili. La scocca ha sedi per dadi lungo il perimetro. Le schede si dispongono sopra un vassoio isolante piano; non devono appoggiare direttamente sull'alluminio.

Il percorso del carico è **piatto plastico → portapiatto metallico → distanziale mobile → cella → distanziale fisso → fondo metallico → piedi**. Il guscio e i cavi devono rimanere separati dal piatto mobile. Gli arresti regolabili sono previsti per intervenire oltre il campo di misura; il gioco corretto deve essere determinato sul prototipo.

## File da aprire

- [Schema quotato di ingombro e percorso del carico](drawings/layout-and-load-path.svg): pianta e disposizione del gruppo di pesatura.
- [Assieme STEP completo](step/MINU_concept_02_COMPLETE_NOMINAL_ASSEMBLY.step): ogni componente è un solido nominato, compresi viti, dadi, rondelle e i sottopezzi del modello ufficiale del gruppo UPS. Filetti standard semplificati nei pezzi generati; non sono eliche da stampare.
- [Distinta con link ai fornitori](distinta-acquisti.md) e [CSV](distinta-acquisti.csv): acquisti, componenti inclusi nei kit e parti da produrre sono distinti.
- [Note di lavorazione CNC](manufacturing-notes.md): coordinate dei fori, filetti e svasature. Queste specifiche accompagnano obbligatoriamente gli STEP nominali.
- [Revisione strutturale](structural-review.md): equilibrio statico, screening analitico degli spessori e limiti dei calcoli.
- [Revisione comandi e passaggi](review-controls.md): controlli degli innesti e misure ancora da confermare.
- [Verifica geometrica automatica](verification.json): **444 solidi**, STEP reimportato valido e **15 STL** chiusi con orientamento coerente. Il [controllo delle interferenze](interference-audit.json) riporta zero intersezioni inattese nelle 1.004 coppie candidate: verifica completa, seguita dal ricalcolo dei tre pezzi modificati nell'ultimo percorso USB-C. I contatti interni al kit ufficiale UPS sono esclusi; gli innesti elettrici intenzionali sono elencati separatamente.

I file della cartella `stl/` sono soltanto parti in plastica da stampare; i metalli e la viteria si acquistano o lavorano separatamente. Gli STL conservano le coordinate dell'assieme: lo stampatore deve orientare e posare ogni pezzo sul piano. Le quote nominali non incorporano una compensazione specifica della macchina o del materiale.

## Fornitori e parti custom

La cella è disponibile tramite [Essmann](https://www.essmann-shop.com/en/single-point-load-cell-zemic-l6d-c3-30kg-0.4b/11250496); i tastierini tramite [BerryBase](https://www.berrybase.de/en/membrane-keypad-4-keys-without-labelling-with-adhesive-layer); il passapannello tramite [Adafruit](https://www.adafruit.com/product/6069) oppure direttamente [Premier Cable, Cina](https://www.premier-cable.store/products/panel-mount-usb-3-1-type-c-waterproof-cable). Per l'alimentazione è indicato il [kit Waveshare cinese 25507](https://www.waveshare.net/shop/UPS-HAT-D.htm), comprendente le batterie.

**Piatto, guscio, cornice e supporti non sono ricambi generici da marketplace:** sono i pezzi a disegno allegati. [JLC3DP](https://jlc3dp.com/) è un fornitore cinese per la stampa PA12; [JLCCNC](https://jlccnc.com/) per i quattro pezzi in alluminio e la valutazione delle lavorazioni custom. I file possono essere forniti anche a un'officina e a uno stampatore locali. Non sono stati caricati presso terzi, né sono stati effettuati ordini.

## Sequenza di montaggio prevista

1. Lavorare e sbavare basamento, portapiatto e distanziali secondo le note CNC. Controllare la planarità delle zone che stringono la cella e del piano che sostiene la plastica.
2. Avvitare i quattro piedini nei filetti M6 del fondo e montare i controdadi. Inserire i quattro grani di arresto; tenerli inizialmente arretrati per non influenzare la prima caratterizzazione.
3. Fissare il lato cavo della cella al distanziale da 6 mm e al fondo con due M6×25 e rondelle. Collegare il lato mobile al distanziale da 22 mm. Serrare alla coppia confermata per la cella e per la specifica giunzione.
4. Montare i vassoi isolanti e il gruppo UPS con i suoi ritegni. Disporre le schede esistenti sul vassoio elettronica; definire i loro attacchi dopo aver misurato i PCB posseduti. Fermare i cavi sul fondo, lasciando libero il corpo deformabile della cella.
5. Assemblare la cornice OLED, il vetrino e il supporto posteriore. Adattare il carrier al display reale, senza serrare componenti o connettori del PCB. Incollare le due membrane nelle sedi e far passare le code attraverso i passaggi protetti.
6. Inserire la USB-C dall'interno, con flangia e O-ring interni e dado esterno. Nella variante Waveshare rappresentata dal CAD, collegare la prolunga all'ingresso USB-C dell'UPS; l'uscita USB-A alimenta il cablaggio 5 V. Questa variante richiede la verifica elettrica e l'adattamento firmware descritti sotto.
7. Inserire i dadi M3 nelle sedi captive del guscio, chiudere la scocca e fissarla dal fondo. Collegare il portapiatto al distanziale mobile con due M6×45 svasate, quindi fissare il piatto plastico con sei M3×10 svasate.
8. Livellare i piedi. Con masse note crescenti, misurare il comportamento al centro e ai bordi, i giochi verso scocca e arresti e il ritorno allo zero. Regolare gli arresti sulla deformazione reale; bloccare i controdadi senza precaricare il piatto.

L'accesso alle schede richiede lo smontaggio di piatto/portapiatto e guscio. Non sollevare la bilancia afferrando il piatto: la cella riceverebbe un carico di segno opposto.

## Cosa resta da confermare prima della produzione funzionale

1. **Display e schede possedute.** Nel repository sono identificati i moduli elettrici, non tutti gli ingombri e interassi dei PCB. La cornice OLED e il vassoio sono predisposizioni sostituibili; i singoli attacchi non possono essere dichiarati compatibili con moduli non misurati.
2. **Campioni commerciali e stampa.** Verificare uscita/pinout delle code BerryBase, sagoma reale di dado e tappo USB, giochi delle sedi captive e adesione delle membrane sul PA12 scelto. Il percorso USB-C misura circa 303,7 mm, rispetto ai 300 ±15 mm dichiarati: deve essere adattato alla lunghezza effettiva del campione, specialmente se corta. Scegliere compensazioni di stampa con il fornitore.
3. **Cella e carico.** Confermare con Zemic orientamento ammesso del piatto 280×200 e coppia di serraggio per 30 kg, quindi collaudare i 20 kg utili, anche eccentrici. Una lettura da 1 g non equivale ad accuratezza da 1 g; il solo errore combinato dichiarato della cella C3 equivale a 6 g sul fondo scala.
4. **Variante batteria nel CAD.** Il modello presenta il gruppo Waveshare con due 21700, non la NASTIMA e il Mini360 già installati. I suoi ingombri e fissaggi non attestano la compatibilità con la batteria posseduta. Il firmware attuale usa tacche indicative LiFePO4 2S e protezioni a 5,80/5,70 V: l'eventuale adozione della variante Waveshare richiede un intervento elettrico/firmware separato. Vedere [ricarica e alimentazione](research-power.md), compreso il limite di corrente non pubblicato della prolunga USB-C.

La validità del CAD e degli STL non dimostra la portata fisica o la precisione della bilancia. Gli accoppiamenti verificati sono nominali e i cablaggi flessibili rappresentano percorsi di progetto.

## Riproducibilità

Generatore [generate_assembly.py](generate_assembly.py), unità millimetri, assi X larghezza, Y profondità (fronte negativo), Z verticale. Ambiente verificato: Python 3.12, CadQuery 2.8, trimesh. Il modello originale Waveshare resta sotto `sources/`.

```powershell
python -m pip install cadquery==2.8.0 trimesh
python docs/mechanical/concept-02/generate_assembly.py
python docs/mechanical/concept-02/build_bom.py
python docs/mechanical/concept-02/structural_screening.py
```

L'anteprima leggera usa `build_preview.py` e richiede inoltre `fast-simplification`. Riduce le triangolazioni e omette i componenti elettronici vendor più piccoli soltanto per la visualizzazione; non modifica STEP e STL. Nessuna modifica al firmware, al pinout o alla configurazione elettrica installata in questa proposta.

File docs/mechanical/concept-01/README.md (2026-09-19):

# Minù — Scocca Concept 01

Proposta preliminare per una bilancia da banco con scocca, basamento e piatto in plastica. **20 kg è il requisito di progetto; la portata dell'insieme non è ancora verificata.** Il concept permette di valutare forma, ingombri e disposizione delle nervature. Gli attacchi della cella e le giunzioni tra pezzi devono essere definiti prima di realizzare una bilancia funzionante.

## Forma e ingombri

- Larghezza × profondità × altezza complessiva: **280 × 300 × 110 mm**, con piedini indicativi.
- Piatto: **280 × 200 mm**, nella zona posteriore.
- Angoli raccordati, frontale inclinato liscio, basamento arretrato e piatto separato dalla scocca.
- Nessun display, tastiera o connettore definito in questa fase.
- Nessun telaio generale in alluminio. La cella e futuri inserti o viti locali restano componenti separati.

Le dimensioni sono scelte di questo concept, ispirate agli ingombri della [EVA 9901 descritti nella scheda commerciale METRO](https://www.metro.it/marketplace/product/8e3196b6-624e-4b28-9775-db98ee96afa2). Non costituiscono un rilievo della bilancia di Andrea. La scheda attuale Kaufgut presenta campi dimensionali diversi; per questa proposta si usa esplicitamente il riferimento commerciale 280 × 300 × 110 mm.

## Struttura proposta

Tre parti plastiche separate:

1. **Basamento nervato:** collega la zona di appoggio fissa della futura cella alle zone dei quattro piedi.
2. **Scocca:** protegge il volume interno e forma il frontale. Non deve sostenere direttamente il piatto durante la pesata.
3. **Piatto nervato:** distribuisce il carico verso la zona mobile della futura cella. La faccia superiore resta piana.

Il percorso previsto del peso è **piatto → attacco mobile → cella → attacco fisso → basamento → piedi**. La cella single-point è un'ipotesi di architettura; il suo volume nel CAD è soltanto una riserva di spazio. Non è stata selezionata una cella e non sono definiti interassi, distanziali, coppie di serraggio o arresti di sovraccarico. Il piatto non deve appoggiarsi alla scocca: un contatto parassita aggirerebbe il sensore.

Quote effettive del modello:

| Elemento | Geometria preliminare |
|---|---|
| Pelle superiore del piatto | 6 mm |
| Nervature del piatto | 6 mm di spessore × 30 mm di altezza, passo 40 mm |
| Isola mobile del piatto | 80 × 64 mm, centrata sotto il piatto |
| Fondo basamento | 6 mm |
| Nervature principali basamento | 4 mm di spessore × 25 mm di altezza |
| Pareti scocca | 3,2 mm nominali |
| Riserva indicativa cella | 38 × 100 × 22 mm, senza interassi |

La riserva cella non interseca i tre solidi plastici a riposo. Le isole interne hanno aperture di alleggerimento e accesso per la rimozione della polvere; tali aperture non sono fori di montaggio della cella.

Il controllo preliminare delle sezioni è in [structural-screening.md](structural-screening.md). Serve per scegliere proporzioni plausibili delle nervature; non sostituisce il calcolo dell'assemblato né le prove sotto carico.

## File

- `concept-estetico.png`: immagine illustrativa generata con ImageGen. Mostra la direzione estetica; le superfici non sono un rendering metrico del CAD.
- `generate_concept.py`: modello parametrico in CadQuery, commentato in inglese.
- `step/`: solidi modificabili, singoli e assemblato con riferimenti separati.
- `stl-forma/`: tre parti triangolate per valutare e stampare la geometria preliminare. Nessuna cella o piedino di riferimento incluso.
- `preview-mesh.json`: triangolazione alleggerita dello stesso CAD per l'anteprima.
- `verification.json`: controlli geometrici effettivamente eseguiti e parametri del modello.
- `imagegen-prompt.txt`: prompt del concept estetico; generazione tramite strumento integrato, senza CLI/API esterna.

Tutte le quote sono in **millimetri**. Gli STL non contengono l'unità: impostare mm nel software di stampa. Le parti mantengono le coordinate dell'assemblato; il service deve orientare e posizionare ciascuna parte sul piano di costruzione.

Verifica locale eseguita: ciascun pezzo è un solido CAD valido; ogni STL è una mesh chiusa con orientamento coerente e un solo componente. Non risultano volumi di intersezione fra le tre parti plastiche, né fra esse e il riferimento cella. Questi controlli verificano la geometria, non la resistenza sotto carico.

## Stampa presso terzi

Per lo sviluppo funzionale si propone **PA12 con MJF o SLS**, previa verifica di materiale, processo, tolleranze e orientamento con il service. HP indica il PA12 fra i materiali adatti a scocche e componenti tecnici: [materiali HP](https://www.hp.com/us-en/printers/3d-printers/materials.html). La scelta di processo fa parte del dimensionamento; una stampa di forma in un materiale diverso non dimostra il comportamento della futura versione funzionale.

Il service può usare gli STL per un preventivo o un campione di forma. **Non presentare questo pacchetto come progetto già verificato per sostenere 20 kg in esercizio.** Prima della stampa funzionale vanno chiusi gli attacchi della cella, le giunzioni, i piedi reali e i finecorsa, quindi ricontrollate deformazioni e interferenze. Le prove dovranno comprendere carico centrato, ai bordi e agli angoli, ritorno a zero e permanenza del peso nel tempo.

Per le interfacce della cella, il produttore richiede appoggi rigidi e piani e indica la protezione meccanica dai sovraccarichi: [manuale A&D LCB27](https://www.aandd.jp/products/manual/loadcells/lcb27.pdf). È una fonte per l'architettura, non una selezione di quel modello.

## Rigenerazione

Usare Python compatibile con CadQuery e installare le dipendenze in un ambiente esterno al repository:

```sh
python -m pip install cadquery==2.8.0 trimesh
python generate_concept.py
```

Questo progetto meccanico non modifica firmware, cablaggio o calibrazione della bilancia esistente.

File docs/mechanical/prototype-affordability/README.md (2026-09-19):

# Un solo prototipo: supporti commerciali e plastiche personalizzate

La prima soluzione da sviluppare è **cella con due supporti commerciali della famiglia T130, piatto e scocca in plastica stampata**, secondo le immagini fornite da Andrea. La [valutazione tecnica e di acquisto](t130-assessment.md) distingue quote leggibili, ipotesi di montaggio e dati ancora mancanti. La bilancia donatrice resta un'alternativa economica di confronto.

## Architettura proposta

- Cella da **30 kg candidata**, per lasciare spazio alla tara mobile oltre ai **20 kg utili** richiesti.
- Staffa media **220 × 125 mm** mobile sotto il piatto; staffa grande **259 × 169 mm** fissa sotto la cella. Ruoli coerenti con le fotografie, da confermare sul kit.
- Piatto plastico **280 × 200 mm**, nervato inferiormente e sostenuto dalla staffa superiore.
- Fondo plastico con piano interno liscio, nervature inferiori e piedi più esterni dei fori 240 × 150 mm della staffa. Le zone plastiche fra staffa e piedi restano strutturali.
- Guscio moderno con OLED già posseduto, almeno otto tasti e predisposizione USB. Batteria e circuito di ricarica richiedono integrazione separata.
- Viti, dadi, rondelle, piedi e distanziali da scegliere in formati standard e includere nel futuro CAD.

## Stato dei costi

La schermata AliExpress mostra **17,39 € per la variante selezionata «20kg load cell»**; non dimostra il prezzo di un kit completo. Le staffe sono presentate come opzioni separate. Prezzi di cella 30 kg, staffe, MOQ e consegna sono ancora da verificare, anche per la seconda inserzione Alibaba indicata dall'utente.

Il limite di **250 €** discusso resta soltanto un obiettivo progettuale proposto, non un budget approvato né un preventivo dimostrato. Non si applica al T130 la ripartizione di costo della soluzione con donatrice. La stampa va quotata per **una copia di ogni pezzo**, sul file effettivo e con materiale e orientamento definiti.

## Riferimenti

- [Supporti T130: quote, carico, stabilità e acquisto](t130-assessment.md).
- [Servizi di stampa singola e limiti delle tariffe di esempio](printing-route.md).
- [Altri telai commerciali](ready-made-frames.md).
- [Bilance donatrici come alternativa](donor-options.md): Steinberg completa a 43 € alla ricerca del 7 settembre 2026, non costo della bilancia personalizzata.

Il [Concept 02](../concept-02/README.md) e il relativo ZIP rappresentano ancora quattro parti metalliche custom: **non sono i file da ordinare per il gruppo T130**. Le immagini non bastano per dichiarare accoppiamenti definitivi, portata del nuovo assieme o accuratezza di 1 g. Mancano quote complete, prezzi del singolo ordine e verifica strutturale. Nessun nuovo CAD o acquisto; firmware e alimentazione installata restano invariati.

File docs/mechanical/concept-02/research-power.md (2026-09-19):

# Alimentazione USB-C della proposta meccanica

Variante meccanica Waveshare del 7 settembre 2026, non installata: permette di definire un ingombro concreto e rimovibile nel CAD. L'alimentazione corrente usa invece la batteria USB NASTIMA BK06-LF60-NATC LiFePO4 6,4 V / 6 Ah e il Mini360 MP1482DS, con uscita regolata da Andrea a 5,11 V e primo funzionamento riferito positivo. Il vecchio impianto SLA / CTK3S è sostituito; cablaggio corrente e limiti del monitoraggio firmware sono descritti in [WIRING](../../WIRING.md) e nel [README principale](../../../README.md).

## Componenti selezionati

| Quantità | Componente | Acquisto e documentazione | Interfaccia meccanica |
|---:|---|---|---|
| 1 kit | **Waveshare UPS HAT (D), SKU 25507**, versione cinese con 2 batterie 21700, protezione acrilica e viteria | [Waveshare Cina](https://www.waveshare.net/shop/UPS-HAT-D.htm). Contenuto del kit verificato nella pagina; prezzo e spedizione in Italia da confermare. | PCB 85 × 56 mm; ingombro complessivo del modello ufficiale **85 × 62,464 × 38,6 mm**. Batterie e protezione inferiori comprese. |
| alternativa | **Waveshare UPS HAT (D) EN, SKU 25567** | [Waveshare internazionale](https://www.waveshare.com/product/ups-hat-d.htm), USD 24,99 rilevati. **Batterie escluse**: non sommare i due kit nella distinta. | Stesso riferimento meccanico; procurare le due batterie 21700 compatibili dal fornitore. |
| 1 | **Premier PCM-0726 / Adafruit 6069**, prolunga USB-C da pannello, 300 mm | [Adafruit](https://www.adafruit.com/product/6069), oppure [Premier Cable Cina](https://www.premier-cable.store/products/panel-mount-usb-3-1-type-c-waterproof-cable). | Flangia interna, dado e tappo esterni; foro e fissaggi nel CAD. Dettagli in research-controls.md. |
| 1 | **Adafruit 2697**, cavo USB-A → jack, 22 AWG, 1 m, da trasformare in cablaggio interno | [Adafruit](https://www.adafruit.com/product/2697), USD 2,75 rilevati. | Conservare il maschio USB-A, accorciare a circa 200 mm, eliminare il jack e terminare sul distributore 5 V esistente. Lunghezza definitiva secondo percorso, con riserva di manutenzione. Sagoma del connettore e percorso sono inviluppi di progetto. |
| 1 esterno | **Raspberry Pi alimentatore USB-C 15 W, spina EU**, 5,1 V / 3 A | [Produttore e rivenditori](https://www.raspberrypi.com/products/power-supply/), [scheda ufficiale](https://datasheets.raspberrypi.org/power-supply/usb-c-power-supply-product-brief.pdf). | Esterno alla bilancia; il cavo entra nella presa sul guscio. Non inserito tra i pezzi interni da stampare. |

Prezzi osservati, in valute e regimi fiscali diversi: non rappresentano il costo totale consegnato. Nessun acquisto effettuato per questa variante Waveshare. Il kit cinese con batterie evita di dichiarare compatibile un elemento 21700 più lungo del vano nominale: il produttore indica **21 × 70 mm**. Ad esempio, una Samsung 50E da 70,6 mm non è stata approvata come sostituzione.

## Funzione e disposizione

Percorso previsto: alimentatore USB-C esterno → prolunga da pannello → ingresso USB-C UPS → batterie / convertitore → uscita USB-A 5 V → cablaggio verso l'elettronica esistente. Il modulo integra caricatore con gestione simultanea di carica e carico, protezioni, convertitore e misura INA219. Fonte: [manuale Waveshare](https://www.waveshare.com/wiki/UPS_HAT_%28D%29).

Il vano di alimentazione è sul fondo piano, su un vassoio isolante rimovibile. L'ingombro comprende la protezione acrilica e i contatti superiori: non è stato usato il solo spessore del PCB. I cablaggi si fissano al basamento; nessun cavo deve tendersi contro cella o piatto mobile. L'accesso ai connettori e ai comandi del modulo richiede l'apertura del guscio.

Il modello 3D ufficiale è conservato in [sources/waveshare-ups-hat-d/UPS-HAT_D.stp](sources/waveshare-ups-hat-d/UPS-HAT_D.stp), scaricato dal [file ZIP del produttore](https://files.waveshare.com/wiki/UPS-HAT-D/UPS-HAT-D%203D%20Drawing.zip). Il riferimento contiene 297 solidi; limiti originali X −85…0, Y 0…62,464, Z −28,1…10,5 mm. Lo schema è in [sources/waveshare-ups-hat-d-schematic.pdf](sources/waveshare-ups-hat-d-schematic.pdf).

## Verifiche elettriche che il CAD non sostituisce

- Il produttore descrive l'UPS come uscita fino a 2,5 A; la corrente effettiva dipende dallo stato batteria e dal carico. Il progetto deve misurare consumo e picchi di ESP32, OLED e audio prima di fissare autonomia e margine.
- La prolunga PCM-0726 riporta conduttori 24 AWG ma non una corrente continua certificata di 3 A. Verificare il limite del fornitore e la caduta di tensione del percorso completo; la dimensione dei fili da sola non certifica i connettori.
- Il firmware attuale usa tacche indicative per **LiFePO4 2S** e protezioni a **5,80/5,70 V**, incompatibili con il pacco 1S della variante Waveshare. Prima dell'eventuale adozione di questa variante occorre una modifica separata di monitoraggio, soglie batteria, calibrazione corrente e gestione spegnimento. INA219 UPS usa indirizzo 0x43 e il gestore MCU 0x2D secondo manuale; non sono una sostituzione automatica del sensore attuale. Per i limiti delle tacche e dello stato charging con la NASTIMA installata, vedere il [README principale](../../../README.md).
- Terminare il cablaggio 5 V verificando polarità e isolamento. Non alimentare simultaneamente l'ESP32 dalla USB di programmazione e dalla nuova linea VIN senza avere verificato il circuito della specifica DevKit.

Questa è una predisposizione meccanica per la variante Waveshare; la sua catena di ricarica non è stata provata sul banco.

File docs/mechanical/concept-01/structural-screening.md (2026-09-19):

# Controllo preliminare della rigidezza — concept 01

Il requisito di progetto è **20 kg di carico utile**. Il CAD rappresenta un piatto e un basamento portanti in plastica; la scocca esterna non deve sostenere il piatto. Questo controllo orienta le proporzioni delle nervature: **non dimostra ancora la portata dell'assemblato**.

## Geometria considerata

Quote lette in `generate_concept.py`, in millimetri:

- Piatto 280 × 200, pelle superiore 6, superficie a Z = 110.
- Nervature monolitiche 6 × 30, passo 40, da Z = 74 a Z = 104.
- Isola mobile 80 × 64, centrata in X = 0, Y = 50; fondo, pilastri e setti ancora senza interfaccia con una cella selezionata.
- Traverso a Y = 30: bordo laterale a X = 136 e bordo dell'isola a X = 40; tratto esterno **L = 96**.
- Nervatura longitudinale a X = 20: estremità anteriore Y = −47 e bordo isola Y = 18; tratto esterno **L = 65**.
- Distanza geometrica nominale fra fondo nervature e tetto della scocca: 3.
- Basamento: pavimento 6 e nervature 4 × 25. Il presente calcolo non verifica il basamento.

## Modello semplificato

Si isola una nervatura con una striscia della pelle larga **24 mm**: questa sezione a T esiste nel CAD lungo i due tratti considerati. La larghezza ridotta mantiene la striscia entro la proiezione dell'isola alla radice del traverso Y = 30. Il resto della griglia, il bordo e la restante pelle non contribuiscono al modello.

Alla radice si assume un **incastro perfettamente rigido al bordo dell'isola**. L'isola reale, la sua connessione alla cella e il basamento non sono incastri ideali: la loro deformazione è esclusa. Si applica all'estremità della singola nervatura l'intero carico verticale statico di 20 kg, senza ripartirlo arbitrariamente fra più nervature.

Omettere il resto della griglia penalizza la nervatura isolata; assumere la radice rigida favorisce il risultato. Per questo **il calcolo non è un limite superiore garantito della deformazione del piatto completo**. Non copre un carico all'angolo, la flessione locale della pelle fra nervature, il breve bordo oltre la nervatura o una torsione dell'insieme.

## Materiale e formule

Ipotesi di screening: PA12, comportamento elastico lineare isotropo, **E = 1500 N/mm²**. È il modulo di flessione tipico X dichiarato per EOS PA 2200 asciutto ed è inferiore al suo modulo di trazione tipico di 1650 N/mm². Non è un minimo garantito per qualsiasi PA12, orientamento, condizionamento o service. [Scheda primaria EOS PA 2200](https://www.eos.info/es/soluciones-de-polimeros/materiales-polimeros/fichas-tecnicas/mds-pa-2200).

La sezione comprende anima 6 × 30 e ala 24 × 6. Misurando Z dal fondo dell'anima:

- area anima = 180 mm²; baricentro a 15 mm;
- area ala = 144 mm²; baricentro a 33 mm;
- baricentro complessivo = 23 mm;
- momento d'inerzia **I = 39 852 mm⁴**;
- massima distanza dal baricentro **c = 23 mm**.

Con F = 20 × 9,81 = **196,2 N**:

```text
z_bar = sum(A_i * z_i) / sum(A_i)
I = sum(b_i * h_i^3 / 12 + A_i * (z_i - z_bar)^2)
M_root = F * L
sigma_max = M_root * c / I
delta_bending = F * L^3 / (3 * E * I)
```

I tratti sono relativamente corti rispetto alla loro altezza. Si aggiunge quindi una stima del contributo di taglio, senza presentare la sola flessione come spostamento totale. Assumendo Poisson ν = 0,40, G = E / [2(1 + ν)] = 535,7 N/mm² e una sezione resistente a taglio pari alla sola anima A_web = 180 mm²:

```text
k = 5 / 6
delta_shear = F * L / (k * G * A_web)
delta_section_estimate = delta_bending + delta_shear
```

ν e il fattore di taglio sono assunzioni del modello, non proprietà misurate sul pezzo. La stima non include concentrazioni di tensione nei raccordi e nelle giunzioni.

## Risultati

| Tratto isolato | Carico | Tensione normale massima nominale | Freccia da flessione | Contributo stimato di taglio | Somma stimata |
|---|---:|---:|---:|---:|---:|
| Laterale, L = 96 mm | 20 kg | 10,87 MPa | 0,968 mm | 0,234 mm | **1,20 mm** |
| Anteriore/posteriore, L = 65 mm | 20 kg | 7,36 MPa | 0,300 mm | 0,159 mm | **0,46 mm** |

I risultati descrivono una singola sezione con i vincoli sopra indicati. Rendono plausibile l'impiego di nervature profonde in plastica per il requisito di 20 kg e motivano la centratura dell'isola mobile. **Non costituiscono un esito di verifica dell'assemblato né un margine di sicurezza certificato.** Non si può sottrarre semplicemente 1,20 mm dal gioco nominale di 3 mm e dichiarare garantita l'assenza di contatto: mancano deformazioni dell'isola/base/cella, tolleranze e condizioni di carico fuori da questo modello.

## Verifiche necessarie per un prototipo funzionale da 20 kg

- Definire la cella e i suoi fissaggi, considerando anche il peso del piatto e dei componenti mobili oltre ai 20 kg utili. La sola riserva volumetrica non chiude il percorso del carico.
- Verificare basamento, isole, giunzioni e fissaggi; la flessione del sensore deve avvenire senza contatti con scocca o arresti durante la pesatura normale.
- Verificare piatto intero con carico centrale, laterale e ai quattro angoli, incluse deformazioni locali e distribuzione effettiva del carico. Un'analisi numerica deve usare la geometria dell'assemblato e dati del processo scelto.
- Verificare il pezzo stampato con carico noto, scarico/ritorno a zero, ripetibilità, carico eccentrico e permanenza sotto carico nelle condizioni d'uso. Impatti e arresti di sovraccarico richiedono una verifica separata.
- Confermare materiale, orientamento, qualità e tolleranze con il service. Il comportamento sotto carico prolungato non deriva dal solo modulo elastico: prove su PA12 SLS documentano componenti elastiche, viscoelastiche e irreversibili della deformazione. [Krönert et al., ricerca originale sul creep del PA12 SLS](https://link.springer.com/article/10.1007/s00170-022-09446-z).

**Stato:** geometria stampabile e proporzioni delle nervature controllate preliminarmente; cella/assemblaggio e portata funzionale da verificare. Nessuna FEA o prova fisica eseguita.

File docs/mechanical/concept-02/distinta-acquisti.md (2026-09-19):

# Distinta componenti e lavorazioni - Proposta 02

Quantità derivate dall’assieme CAD. Ricerca del 7 settembre 2026; nessun ordine effettuato. Prezzi, spedizione in Italia e disponibilità richiedono conferma al momento dell’acquisto. I link sono riferimenti concreti di prodotto o lavorazione, non un carrello già verificato. Le quantità da ordinare tengono conto dei componenti inclusi e delle strip da tagliare.

I sottopezzi inclusi nei kit sono elencati per riconoscere i solidi del CAD: **non vanno acquistati due volte**. Il display e le schede gia presenti vengono riutilizzati.

Le voci di alimentazione Waveshare e i relativi cablaggi appartengono soltanto alla variante rappresentata nel CAD, non installata. L'alimentazione corrente NASTIMA + Mini360 e documentata in [WIRING](../../WIRING.md); questa distinta non ne richiede la sostituzione.

| Q.tà CAD | Da ordinare / produrre | Componente / codice | Azione | Fonte |
|---:|---|---|---|---|
| 1 | 1 pezzo | Fondo portante piano alluminio 6 mm — `6061-T6, pezzo a disegno` | Lavorare su file | [Prodotto / servizio](https://jlccnc.com/) |
| 1 | 1 pezzo | Scocca superiore rimovibile — `PA12 MJF/SLS, pezzo a disegno` | Stampare su file | [Prodotto / servizio](https://jlc3dp.com/) |
| 1 | 1 pezzo | Distanziale fisso cella 25 x30 x6 — `6061-T6, pezzo a disegno` | Lavorare su file | [Prodotto / servizio](https://jlccnc.com/) |
| 1 | 1 pezzo | Distanziale mobile cella 25 x30 x22 — `6061-T6, pezzo a disegno` | Lavorare su file | [Prodotto / servizio](https://jlccnc.com/) |
| 1 | 1 pezzo | Zemic L6D-C3-30kg - involucro meccanico — `Essmann 11250496` | Acquistare | [Prodotto / servizio](https://www.essmann-shop.com/en/single-point-load-cell-zemic-l6d-c3-30kg-0.4b/11250496) |
| 1 | 1 pezzo | Portapiatto piano alluminio 8 mm — `6061-T6, pezzo a disegno` | Lavorare su file | [Prodotto / servizio](https://jlccnc.com/) |
| 1 | 1 pezzo | Piatto plastico liscio 280 x200 x4 — `PA12 MJF/SLS, pezzo a disegno` | Stampare su file | [Prodotto / servizio](https://jlc3dp.com/) |
| 2 | 2 pezzi | Rondella M6 ISO7089 — `ISO7089 M6 200HV` | Acquistare | [Prodotto / servizio](https://www.westfieldfasteners.co.uk/BZP-Washer-M6.html) |
| 2 | 2 pezzi | Vite M6 x 25 testa cilindrica — `Keller 240912625, 8.8` | Acquistare | [Prodotto / servizio](https://www.keller-kalmbach.com/products/fasteners/screws/hexagon-socket-cap-screws/iso-4762--din-912-cap-screw/p/240912625) |
| 2 | 2 pezzi | Vite svasata M6 x 45 — `Accu SSK-M6-45-10.9-Z` | Acquistare | [Prodotto / servizio](https://www.accu.co.uk/countersunk-socket-head-screws/495060-SSK-M6-45-10-9-Z) |
| 10 | 10 pezzi | Vite svasata M3 x 10 — `Orbital 5500020 A4` | Acquistare | [Prodotto / servizio](https://www.orbitalfasteners.co.uk/products/m3x10-csk-skt-screw-stst-a4-din-7991) |
| 12 | 12 pezzi | Vite M3 x 16 testa cilindrica — `Westfield WF14263 A4` | Acquistare | [Prodotto / servizio](https://www.westfieldfasteners.co.uk/Bolts-Screws-Metric/A4-Socket-Head-Cap-Screw-M3x16mm.html) |
| 16 | 16 pezzi | Dado M3 — `Westfield WF15111` | Acquistare | [Prodotto / servizio](https://www.westfieldfasteners.co.uk/Metric-Nuts/Hex-Nut-M3-Bright-Zinc-Plate-Class-8.html) |
| 4 | — | Pattino antiscivolo piede Elesa — `INCLUDED_FOOT_SBR` | Incluso nel componente | Su misura / posseduto |
| 4 | 4 pezzi | Piede Elesa LX.30-SW17-AS-M6x22 — `Elesa 531051` | Acquistare | [Prodotto / servizio](https://www.elesa-ganter.nl/p/lx-30-sw17-as-m6x22/127394/) |
| 8 | 8 pezzi | Dado M6 — `M6 DIN934 zincato` | Acquistare | [Prodotto / servizio](https://www.essentracomponents.com/en-gb/p/standard-hex-nuts-metal/051060040952) |
| 4 | 4 pezzi | Grano M6 x60 arresto regolabile — `RW D913V060060, DIN913 45H` | Acquistare | [Prodotto / servizio](https://www.rwproducts.nl/din-913-stelschroef-binnenzeskant-met-afschuining-elvz-m6x60) |
| 1 | 1 pezzo | Vassoio potenza rimovibile — `PA12 MJF/SLS, pezzo a disegno` | Stampare su file | [Prodotto / servizio](https://jlc3dp.com/) |
| 2 | 2 pezzi | Staffa rimovibile ritegno verticale UPS — `PA12 MJF/SLS, pezzo a disegno` | Stampare su file | [Prodotto / servizio](https://jlc3dp.com/) |
| 8 | 8 pezzi | Vite M3 x 10 testa cilindrica — `Westfield WF14261 A4` | Acquistare | [Prodotto / servizio](https://www.westfieldfasteners.co.uk/A4-ScrewBolt-SHCap-M3.html) |
| 1 | 1 pezzo | Piastra elettronica universale rimovibile - faccia piana — `PA12 MJF/SLS, pezzo a disegno` | Stampare su file | [Prodotto / servizio](https://jlc3dp.com/) |
| 4 | 4 pezzi | Vite M3 x 8 testa cilindrica — `Westfield WF14272 A4` | Acquistare | [Prodotto / servizio](https://www.westfieldfasteners.co.uk/A4-ScrewBolt-SHCap-M3.html) |
| 1 | 1 pezzo | Cornice OLED sostituibile con sede universale — `PA12 MJF/SLS, pezzo a disegno` | Stampare su file | [Prodotto / servizio](https://jlc3dp.com/) |
| 1 | 1 pezzo | Vetrino piano OLED 82 x 24 x 1.5 — `PMMA trasparente 1,5 mm` | Tagliare su file | [Prodotto / servizio](https://jlccnc.com/) |
| 1 | — | OLED SSD1322 - inviluppo da confermare — `Posseduto: SSD1322 SPI256x64 3,12pollici` | Riutilizzare | Su misura / posseduto |
| 2 | 2 pezzi | Traversino fermo OLED — `PA12 MJF/SLS, pezzo a disegno` | Stampare su file | [Prodotto / servizio](https://jlc3dp.com/) |
| 2 | 2 pezzi | Tastiera adesiva 1x4 - striscia 1 — `BerryBase B-SM4T` | Acquistare | [Prodotto / servizio](https://www.berrybase.de/en/membrane-keypad-4-keys-without-labelling-with-adhesive-layer) |
| 1 | 1 pezzo | USB-C pannello PCM-0726 / Adafruit 6069 — `Premier PCM-0726 / Adafruit6069` | Acquistare | [Prodotto / servizio](https://www.adafruit.com/product/6069) |
| 1 | — | Dado plastico USB-C - ingombro provvisorio — `INCLUDED_USB_NUT` | Incluso nel componente | Su misura / posseduto |
| 1 | — | O-ring USB-C incluso — `INCLUDED_USB_ORING` | Incluso nel componente | Su misura / posseduto |
| 1 | — | Tappo USB-C parcheggiato - ingombro — `INCLUDED_USB_CAP` | Incluso nel componente | Su misura / posseduto |
| 1 | — | Spina USB-C interna - inviluppo — `INCLUDED_USB_C_PLUG_BODY` | Incluso nel componente | Su misura / posseduto |
| 1 | — | Innesto USB-C nella UPS — `INCLUDED_USB_C_PLUG_METAL` | Incluso nel componente | Su misura / posseduto |
| 1 | 1 pezzo | Spina USB-A uscita 5 V - inviluppo — `Adafruit 2697, 22 AWG` | Acquistare | [Prodotto / servizio](https://www.adafruit.com/product/2697) |
| 1 | — | Innesto USB-A nella UPS — `INCLUDED_USB_A_PLUG_METAL` | Incluso nel componente | Su misura / posseduto |
| 1 | — | Cavo USB-C pannello 300 mm - percorso — `INCLUDED_USB_C_CABLE_300MM` | Incluso nel componente | Su misura / posseduto |
| 1 | — | Cablaggio uscita 5 V 200 mm - percorso — `Adafruit2697 22AWG da accorciare` | Incluso nel cablaggio | [Prodotto / servizio](https://www.adafruit.com/product/2697) |
| 2 | 2 pezzi | Fermacavo apribile - base — `PA12 MJF/SLS, pezzo a disegno` | Stampare su file | [Prodotto / servizio](https://jlc3dp.com/) |
| 2 | 2 pezzi | Fermacavo apribile - coperchio — `PA12 MJF/SLS, pezzo a disegno` | Stampare su file | [Prodotto / servizio](https://jlc3dp.com/) |
| 1 | — | Terminazione 5 V sul vano elettronica - riferimento — `Interfaccia alla distribuzione 5 V posseduta` | Riutilizzare / adattare | Su misura / posseduto |
| 1 | — | Cavo cella verso HX711 - percorso — `INCLUDED_L6D_4WIRE_CABLE_400MM` | Incluso nel componente | Su misura / posseduto |
| 4 | — | Conduttore cella verso HX711 — `INCLUDED_L6D_WIRE_END` | Incluso nel componente | Su misura / posseduto |
| 2 | 2 pezzi | Ponte copricoda tastiera adesivo — `PA12 MJF/SLS, pezzo a disegno` | Stampare su file | [Prodotto / servizio](https://jlc3dp.com/) |
| 6 | 1 ritaglio per 6 piazzole | Adesivo copricoda 0.13 mm — `3M468MP, spessore 0,13 mm` | Consumabile da ritagliare | [Prodotto / servizio](https://www.3m.com/3M/en_US/p/dc/v100808810/) |
| 2 | — | Coda tastiera curva - inviluppo 88 mm con connettore — `INCLUDED_KEYPAD_TAIL` | Incluso nel componente | Su misura / posseduto |
| 2 | — | Connettore femmina 5 pin incluso nella membrana — `INCLUDED_KEYPAD_5P_FEMALE` | Incluso nel componente | Su misura / posseduto |
| 2 | 1 strip da 20 poli | Pettine maschio 1x5 adattatore tastiera — `BerryBase PINH-1X20P` | Acquistare | [Prodotto / servizio](https://www.berrybase.de/en/male-connector-1x-20-pin-rm-2.54-straight) |
| 10 | — | Contatto pettine tastiera — `INCLUDED_HEADER_CONTACT` | Incluso nel componente | Su misura / posseduto |
| 2 | 1 nastro 10 fili da 1 m | Cablaggio su misura matrice tastiera - ramo — `Adafruit6182` | Cablaggio da assemblare | [Prodotto / servizio](https://www.adafruit.com/product/6182) |
| 1 | 1 pezzo | Terminazione adattatore tastiera 6 fili — `BerryBase DUPH-1X06` | Acquistare | [Prodotto / servizio](https://www.berrybase.de/en/dupont-housing-1x6-pin) |
| 6 | 6 pezzi | Contatto terminazione tastiera 6 fili — `BerryBase DUPCP-F` | Acquistare | [Prodotto / servizio](https://www.berrybase.de/en/dupont-crimp-contact-for-cable-awg-22-28-female) |
| 1 | 1 pezzo | Kit USB-C UPS HAT(D), due21700, protezione e viti — `Waveshare25507 CN` | Acquistare | [Prodotto / servizio](https://www.waveshare.net/shop/UPS-HAT-D.htm) |
| 1 | 1 pezzo | Alimentatore USB-C esterno15W spina EU — `Raspberry Pi USB-C5,1V3A` | Acquistare se necessario | [Prodotto / servizio](https://www.raspberrypi.com/products/power-supply/) |
| 1 | 1 pezzo | Adesivo sottile per perimetro vetrino — `3M467MP, ritaglio` | Consumabile | [Prodotto / servizio](https://www.3m.com/3M/en_US/p/dc/v000185218/) |
| 2 | 2 pezzi | Etichette funzioni per tastierini blank — `Strisce grafiche su misura70x20mm` | Stampare grafica | Su misura / posseduto |

## Note di assemblaggio e acquisto

- **CNC_BASE_300x320x6**: Faccia superiore piana. Fori filettati rappresentati al diametro nominale; usare le specifiche di maschiatura nelle note CNC.
- **PRINT_OUTER_SHELL**: Guscio rimovibile, pareti da 3 mm e sedi per dadi M3. Giochi delle sedi da verificare con lo stampatore.
- **CNC_CELL_FIXED_SPACER**: Distanziale fisso da 6 mm; superfici di serraggio piane e sbavate secondo le note CNC.
- **CNC_CELL_MOVING_SPACER**: Distanziale mobile da 22 mm; mantiene il portapiatto separato dal guscio.
- **ZEMIC_L6D_C3_30KG_0_4B**: Cella 30 kg; carico utile di progetto 20 kg, accuratezza 1 g non provata.
- **CNC_CARRIER_276x196x8**: Due svasature M6 e sei filetti M3. Sostiene quasi tutta la superficie inferiore del piatto plastico.
- **PRINT_PAN_280x200x4**: Piatto da stampare, sostenuto dal portapiatto metallico; sei viti M3 svasate.
- **WASHER_M6_ISO7089**: 6,4 x12 x1,6 mm.
- **SCREW_M6x25_ISO4762**: Lato fisso della cella; rondella ISO7089.
- **SCREW_M6x45_DIN7991**: Lato mobile; testa D12, cono90. Coppia e giunto da confermare con Zemic.
- **SCREW_M3x10_DIN7991**: Testa D6; svasatura90; lunghezza totale10.
- **SCREW_M3x16_ISO4762**: Testa D5,5 x3.
- **NUT_M3_DIN934**: Chiave5,5, altezza2,4; sedi captive stampate.
- **ELESA_531051**: 4 piedi completi di pattino; filetto M6 nel basamento.
- **NUT_M6_DIN934**: Chiave10, altezza5. Acquistabile a standard anche in ferramenta.
- **SETSCREW_M6x60_DIN913_FLAT_END**: 4 fermi regolabili; gioco di progetto da tarare sul prototipo.
- **PRINT_POWER_TRAY**: Vassoio isolante rimovibile del gruppo UPS, con quattro fissaggi al fondo.
- **PRINT_POWER_RETAINING_STRAP**: Due staffe trattengono il bordo della lastra acrilica inferiore del kit UPS; stampare entrambi i file, le sagome differiscono.
- **SCREW_M3x10_ISO4762**: Selezionare M3 x10, testa D5,5 x3.
- **PRINT_ELECTRONICS_TRAY**: Superficie piana isolante per le schede possedute. I loro singoli attacchi richiedono le misure dei PCB.
- **SCREW_M3x8_ISO4762**: Selezionare M3 x8, testa D5,5 x3.
- **PRINT_DISPLAY_BEZEL**: Cornice sostituibile; sede del modulo e superficie sicura di serraggio da adattare al display posseduto.
- **CUT_DISPLAY_WINDOW**: Richiedere taglio/fresatura82x24x1,5; tolleranza e disponibilita lastra da preventivo.
- **REUSE_OLED_SSD1322**: Non acquistare. Ingombro e serraggio carrier da adattare al modulo reale.
- **PRINT_DISPLAY_REAR_BAR**: Due traversini rimovibili. Verificare che il modulo reale abbia bordi liberi sui quali serrare.
- **KEYPAD_1x4_BERRYBASE_B_SM4T**: 2 membrane adesive70x20x1, totale8tasti. Pinout/coda da campione. Origine Cina.
- **USB_C_PANEL_6069**: Prolunga USB-C300mm, include dado, O-ring e tappo. Alternativa diretta Cina in research-controls.md.
- **USB_A_OUTPUT_HARNESS_2697**: Un cavo da 1 m: conservare USB-A, accorciare a circa 200 mm ed eliminare il jack. Terminare sulla distribuzione 5 V posseduta dopo verifica elettrica.
- **CUSTOM_USB_A_5V_HARNESS_200MM**: Ricavato dal cavo Adafruit 2697 già elencato; non acquistare un secondo cavo. Percorso CAD indicativo; lunghezza e terminali secondo montaggio. Illustrative routed centreline 188.9 mm; supplied/cut cable nominal 200 mm. Connector bodies and service slack require sample fitting.
- **PRINT_CABLE_CLAMP_LOWER**: Due guide apribili per i percorsi USB; usare i file distinti per le due posizioni.
- **PRINT_CABLE_CLAMP_UPPER**: Coperchi delle guide con quattro viti M3 complessive. Diametro e curvatura dei cavi reali da verificare.
- **CUSTOM_5V_TERMINATION**: Segnaposto di interfaccia, non un morsetto commerciale selezionato. Sagoma e innesto da adattare alla scheda reale.
- **PRINT_KEYPAD_CABLE_HOOD**: Due ponti coprono le uscite delle code; appoggi adesivi esterni alle membrane, senza pressione sulle zone dei tasti.
- **CUT_3M468MP_KEYPAD_HOOD_PAD**: Ritagliare due piazzole 24×2 e quattro 2×6 mm. Spessore 0,13 mm; adesione sulla finitura stampata da verificare.
- **HEADER_1x5_2p54**: Tagliare due pettini da 5 poli da una sola strip. Verificare profondità di innesto sul campione; pin inclusi. Alternativa Cina LCSC C2977586 con minimo 5 strip.
- **CUSTOM_KEYPAD_MATRIX_BRANCH**: Ricavare due rami da 5 fili, taglio iniziale 200 mm ciascuno. Unire le quattro righe a monte dei sei contatti; saldare e isolare i giunti, non inserire due fili nello stesso crimp non specificato. Adeguare le lunghezze al montaggio.
- **HOUSING_1x6_2p54**: Quote dei connettori da verificare sul campione.
- **CRIMP_CONTACT_2p54**: Sei contatti femmina per fili AWG22–28; verificare ritenuta nel contenitore DUPH-1X06 e crimpatura sul filo AWG26 selezionato.
- **WAVESHARE_UPS_HAT_D_KIT**: Un kit; 297 solidi del relativo gruppo nel CAD. EN25567 alternativo senza batterie. Variante meccanica non installata, non ancora provata con firmware.
- **EXTERNAL_USB_C_PSU**: Esterno alla scocca; non fa parte degli STL.
- **DISPLAY_ADHESIVE**: Spessore tipico0,05-0,06mm; adesione sul materiale stampato da verificare. Ritagliare senza coprire apertura80x22.
- **KEY_LABEL_OVERLAY**: SKIP/WIFI/SLEEP/CLEAR e ENTER/TOTAL/MODE/TARE; allineare le zone sensibili al campione. Grafica illustrativa nel viewer.

## Parti gia presenti

ESP32 DevKit, HX711, INA219, DFPlayer Mini, buzzer e altoparlante restano quelli del progetto. Sono previsti spazio e vassoio isolante rimovibile; i singoli attacchi PCB richiedono le misure delle varianti possedute. Sono gia installati la batteria USB NASTIMA BK06-LF60-NATC LiFePO4 6,4 V / 6 Ah e il Mini360 MP1482DS, con uscita regolata da Andrea a 5,11 V e primo funzionamento riferito positivo. Sostituiscono la configurazione SLA / CTK3S; non sono rappresentati dal gruppo Waveshare e dai suoi fissaggi nel CAD.

Il piatto e i supporti sono **pezzi a disegno**: stampare le plastiche e lavorare le quattro parti metalliche dai file allegati. Consultare manufacturing-notes.md per filetti e svasature: i cilindri nominali nel STEP non indicano il diametro di preforo per maschiatura.

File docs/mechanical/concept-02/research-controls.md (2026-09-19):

# Concept 02 - comandi, USB-C e display esistente

Stato: ricerca per il prototipo meccanico, verificata il 7 settembre 2026. Nessun componente acquistato. Le quote di catalogo, le quote progettate e gli ingombri ancora da misurare sono distinti; questi ultimi non costituiscono un attacco produttivo validato.

## 1. Vincoli derivati dal firmware

Il progetto documenta un **OLED SSD1322 SPI da 3,12 pollici, 256 x 64** (`README.md`, elenco hardware), ma non indica produttore, codice del modulo, interassi o profondita del connettore. Si riutilizza il display di Andrea; la distinta non ne prevede l'acquisto.

La tastiera attuale e una matrice passiva **4 righe x 2 colonne**: R1-R4 sui GPIO 17, 5, 13, 14 e C1-C2 sui GPIO 19, 21. Le otto funzioni sono definite in `firmware/esp32_hx711_serial/keypad.cpp`: SKIP, WIFI, SLEEP, CLEAR nella prima colonna; ENTER, TOTAL, MODE, TARE nella seconda. Due tastiere 1 x 4 con un comune indipendente ciascuna possono realizzare la stessa topologia, unendo soltanto le quattro linee dei singoli tasti. Questa e una proposta di cablaggio, da provare sul campione, senza modifica firmware nel presente lavoro. Nessuna alimentazione esterna su righe o colonne.

## 2. Tastiera: otto tasti su due membrane adesive

**Selezione d'acquisto: 2 x BerryBase B-SM4T senza numeri**, produzione Cina. Ingombro dichiarato **70 x 20 x 1 mm**, cavo compreso connettore **88 mm**, cinque poli passo **2,54 mm**. La pagina visitata mostra EUR 1,60 e otto pezzi disponibili; prezzo e giacenza restano da rivedere al momento dell'ordine. Il fissaggio e adesivo e non richiede viti. Le etichette funzionali sono da stampare per il prototipo. L'ordine elettrico dei pin non e pubblicato: si rileva con una prova di continuita prima del collegamento. [BerryBase B-SM4T](https://www.berrybase.de/en/membrane-keypad-4-keys-without-labelling-with-adhesive-layer).

**Alternativa dimensionale e riferimento per la matrice: Adafruit PID 1332.** Ogni membrana misura 69,14 x 20,07 mm; coda e connettore misurano 87,31 x 14,28 mm; connettore femmina a cinque poli, passo 2,54 mm. Il produttore pubblica il pinout: pin 1 comune, pin 2 tasto 2, pin 3 tasto 1, pin 4 tasto 4, pin 5 tasto 3. I quattro tasti sono blu e numerati. La pagina diretta risulta esaurita; un risultato indicizzato riportava una giacenza contraddittoria e non e stato usato come conferma di disponibilita. Lo spessore di questa alternativa non e quotato nella pagina. **Il suo pinout non va trasferito automaticamente alla BerryBase.** [Adafruit 1332](https://www.adafruit.com/product/1332), [pinout ufficiale](https://learn.adafruit.com/matrix-keypad?view=all).

Il riferimento si trova anche dal fornitore cinese **ODSEVEN / Shenzhen Xuan Yao**, che dichiara lo stesso ingombro 69,14 x 20,07 mm. La pagina indica MOQ 10 e fascia USD 0,90-1,24: e una richiesta d'offerta, non una disponibilita confermata per due pezzi. Il codice fornitore e le quote della coda vanno riconfermati. [ODSEVEN su Made-in-China](https://xuanyao.en.made-in-china.com/product/ywxmLVDcCpWX/China-Membrane-1X4-Keypad-Extras-Wholesale.html).

Innesto progettato per entrambi: due sedi lisce **71 x 21 mm**, separate, con bordo e raccordi privi di spigoli taglienti; due passacavo nominali **16 x 6 mm** per far transitare il connettore senza smontarlo. Il posizionamento del passacavo rispetto al punto di uscita della coda e ancora una **quota da campione**. Le foto ufficiali BerryBase e Adafruit mostrano la coda centrata sul bordo lungo superiore, fra i due tasti centrali; la foto del retro Adafruit mostra la giunzione a pochi millimetri dal bordo. La larghezza esterna e lo spessore del connettore BerryBase non sono quotati: il suo passaggio nello slot 16 x 6 resta da verificare sul campione. Non collocare il passacavo al centro dell'intera membrana o sotto i centri di pressione. Il CAD prevede due ponti copricoda **24 x 11 x 2,4 mm**, fissati soltanto all'esterno dell'impronta della membrana con ritagli adesivi spessi 0,13 mm. La loro superficie inferiore lascia libera la curva della coda e non preme i tasti. La membrana e le coperture non attestano una classe IP dell'intera bilancia.

L'helper `controls_cable_details.py` include due nastri con centrolinea curva di 76 mm e connettori terminali lunghi 12 mm, per rappresentare l'ingombro totale di 88 mm pubblicato. Entrambi piegano nel piano YZ, senza curve laterali nel piano del nastro: il tratto inferiore della prima coda e 5 mm sotto quello della seconda, conservando lo sviluppo totale. **La suddivisione 76+12, lo spessore 0,3, la larghezza 14,28, i raggi 2/4 e i corpi dei connettori sono assunzioni CAD da verificare.** I due pettini 1 x 5 alimentano un adattatore cablato passivo verso una terminazione a sei fili sopra il vassoio elettronica. La terminazione non pretende di coincidere con una presa esistente sulla scheda ESP32 posseduta.

Per le coperture e proposto nastro di trasferimento **3M 468MP**, nominalmente 0,13 mm: l'adesione sul PA12 stampato e finito va provata. La scheda 3M riguarda il nastro, non approva questa specifica giunzione; si acquista un piccolo foglio o una striscia convertita per ricavare sei ritagli, con formato e prezzo da fornitore. [Fonte 3M](https://www.3m.com/3M/en_US/p/dc/v100808810/).

L'adattatore e un **cablaggio su misura**, costituito da due rami a cinque conduttori e una terminazione a sei segnali. Materiali da acquistare:

- **Due pettini 1 x 5:** si tagliano da una strip passo 2,54. Una [BerryBase PINH-1X20P](https://www.berrybase.de/en/male-connector-1x-20-pin-rm-2.54-straight), EUR 0,20 e oltre 100 pezzi visualizzati, e sufficiente. La [strip PINH-1X40P](https://www.berrybase.de/en/male-connector-1x-40-pin-rm-2.54-straight) resta un riferimento esaurito. Per acquisto cinese e disponibile [ZHOURI 2.54-1*40, LCSC C2977586](https://www.lcsc.com/product-detail/C2977586.html), MOQ cinque strip: ne viene consumata una, ricavando i due pettini. I dieci contatti metallici nel CAD sono inclusi nei pettini e non vanno ordinati nuovamente.
- **Un housing e sei contatti:** [BerryBase DUPH-1X06](https://www.berrybase.de/en/dupont-housing-1x6-pin), EUR 0,10, e sei [DUPCP-F singoli per AWG22-28](https://www.berrybase.de/en/dupont-crimp-contact-for-cable-awg-22-28-female), EUR 0,05 ciascuno, entrambi indicati disponibili. Sono la stessa famiglia generica proposta dallo stesso venditore; non e una coppia certificata da un fabbricante identificato. Verificare ritenuta del contatto e crimpatura dell'isolamento sul campione. Gli inviluppi dei contatti sono semplificati. Le quattro giunzioni delle righe vanno realizzate a monte: non inserire due conduttori in un crimp non dichiarato per tale uso.
- **Filo per i due rami:** [Adafruit 6182](https://www.adafruit.com/product/6182), nastro separabile a dieci conduttori AWG26, un metro, isolamento silicone e diametro esterno del singolo filo 1,3 mm. Prezzo USD 2,50; 65 pezzi visualizzati. Da un tratto nominale di 200 mm si ricavano dieci fili, riuniti in due rami da cinque; il metro fornito lascia materiale per le giunzioni. Il CAD usa fasci diametro **4,2 mm** come inviluppi di instradamento, non replica del fascio finito. I percorsi nominali sono lunghi 152,339 e 139,017 mm; la lunghezza di taglio si rifinisce sul montaggio.

Cablaggio proposto usando il pinout Adafruit:

| Linea | Membrana A | Membrana B | ESP32 |
|---|---|---|---|
| Comune A | pin 1 | - | C1 / GPIO19 |
| Comune B | - | pin 1 | C2 / GPIO21 |
| R1 | pin 3, SKIP | pin 3, ENTER | GPIO17 |
| R2 | pin 2, WIFI | pin 2, TOTAL | GPIO5 |
| R3 | pin 5, SLEEP | pin 5, MODE | GPIO13 |
| R4 | pin 4, CLEAR | pin 4, TARE | GPIO14 |

Realizzare le giunzioni in un cavetto adattatore a sei fili verso la scheda, con due ingressi a cinque pin; isolare singolarmente saldature e giunzioni prima di riunire il fascio. Verificare a circuito spento continuita e corrispondenza delle otto funzioni prima del collegamento. Il firmware e progettato per l'uso di un tasto alla volta.

## 3. Presa USB-C: connettore commerciale completo

Selezionato **Premier Cable PCM-0726, 0,3 m**, reperibile come **Adafruit 6069**. E una prolunga passiva USB-C femmina da pannello / USB-C maschio interno. Il disegno Adafruit riporta lo stesso codice PCM-0726 del produttore cinese. Include corpo, dado ABS, O-ring e tappo antipolvere con linguetta; la sua funzione nel progetto e portare la presa di ricarica alla parete. [Adafruit 6069](https://www.adafruit.com/product/6069), [acquisto diretto Premier Cable, Cina](https://www.premier-cable.store/products/panel-mount-usb-3-1-type-c-waterproof-cable).

Quote documentate dal produttore: filetto **M12 x 1** lungo **15 mm**, doppio piano **11,40 mm**, flangia **diametro 18 x 6 mm**, retro cilindrico **diametro 11 x 10 mm**. Il corpo e lungo 31 mm, somma di 15 e 16 mm del disegno. Cavo diametro **4,8 mm**, lunghezza libera **300 +/- 15 mm**. L'O-ring e indicato **11 x 1,5 x 14 mm** (interno, sezione, esterno). La pagina Adafruit ammette pareti fino a 13 mm.

La flangia rimane **all'interno**; il tratto filettato attraversa il pannello e riceve dado e tappo all'esterno. Per il prototipo: foro CAD **diametro 12,4 mm** in un pannello spesso **3 mm**, quote scelte dal progetto rispetto al foro nominale diametro 12 del produttore. Prevedere 16 mm interni per il corpo e almeno 25 mm di spazio aggiuntivo per instradare il cavo; quest'ultimo e un ingombro di progetto, non il raggio minimo certificato del cavo. Dado modellato come ingombro diametro 20 x 4 e tappo diametro 18 x 4: **dimensioni provvisorie**, non pubblicate. Usare il dado fornito, senza stampare un dado sostitutivo.

I PDF e il dettaglio quotato sono conservati in `sources/adafruit-6069-drawing.pdf` e `sources/adafruit-6069-dimensions.jpg`. [Disegno completo](https://cdn-shop.adafruit.com/product-files/6069/P6069+PCM-0726_TYPE_C___________F-M_L300MM.pdf), [dettaglio del corpo](https://cdn-shop.adafruit.com/product-files/6069/P6069_____________20240514182020______________%281%29.jpg).

Prezzi letti: Adafruit USD 4,50; Premier USD 16,00 senza IVA, vendita senza MOQ dichiarata. Trasporto e imposte non inclusi nel confronto. La selezione definisce l'interfaccia meccanica, **non il circuito di ricarica**: la prolunga USB deve terminare sull'ingresso del caricatore previsto. Il CAD rappresenta la variante Waveshare, non installata; il cablaggio corrente con batteria USB NASTIMA e Mini360 e descritto in [WIRING](../../WIRING.md). Il caricatore, la gestione CC e la tensione di alimentazione devono appartenere allo schema di alimentazione definito separatamente. Il disegno del cavo mostra la continuita dei contatti CC; la compatibilita effettiva del sistema di ricarica della variante Waveshare resta da provare. Per questa variante proposta nel concept, ingresso USB **5 V / 3 A**, la portata continua della prolunga **non e pubblicata nelle fonti consultate**: va confermata dal fornitore e poi verificata con misura della caduta di tensione e del riscaldamento al carico previsto. La sezione 24 AWG riportata nel disegno non sostituisce la portata nominale dell'assieme di cavo e contatti. Il blocco CAD di terminazione dell'uscita **5 V** indica il punto di collegamento all'elettronica posseduta: non identifica un morsetto commerciale selezionato o gia compatibile.

## 4. Display posseduto: carrier sostituibile

La famiglia e nota, il modulo preciso no. Un esempio plausibile della stessa famiglia e il **KS Display KSE25664-31M**, dichiarato 100,5 x 33,5 x 11,3 mm, area attiva 76,78 x 19,18 mm, sette pin. Serve esclusivamente a impostare un ingombro preliminare; **non identifica il display posseduto**. [KS Display, specifica del modulo](https://ksdisplay.com/mono-oled-display/3.12-inch-oled-display-module-256x64-ssd1322-kse25664-31m/).

Il CAD usa un carrier stampato smontabile con tasca nominale **101,5 x 34,5 mm**, finestra ottica **80 x 22 mm** e vetrino separato **82 x 24 x 1,5 mm**. La geometria del carrier e una scelta del progetto. Quattro viti M3 e dadi lo fissano alla scocca; due traversini con altre quattro viti M3 trattengono posteriormente l'inviluppo del display. Le zone reali di appoggio, la posizione della superficie attiva, l'altezza PCB, i componenti sul retro e l'uscita del connettore restano **da misurare prima della stampa funzionale**. Non usare interassi inventati come se provenissero dal display di Andrea e non applicare pressione sul vetro.

La BOM non deve confondere questi punti: display gia posseduto, carrier stampato da produrre, minuteria del carrier da acquistare. Le viti del display non possono essere confermate finche non si identifica il suo PCB. Un fissaggio a clip regolabili e possibile solo sui bordi meccanicamente liberi del PCB, che al momento non sono noti.

## 5. Minuteria pertinente ai controlli

| Voce | Quantita proposta | Stato |
|---|---:|---|
| Membrane 1 x 4 | 2 | Acquisto, quote esterne pubblicate |
| Connettori maschio 1 x 5 passo 2,54 | 2 | Da acquistare per BerryBase; inclusi nell'alternativa Adafruit |
| Cablaggio adattatore tastiera 2 x 5 verso 1 x 6 | 1 | Da assemblare e collaudare |
| Ponti copricoda | 2 | Stampa, ingombro 24 x 11 x 2,4 |
| Ritagli adesivi copricoda 3M468MP | 6 | Due 24 x 2 e quattro 2 x 6, spessore 0,13 |
| Housing 1 x 6 e contatti compatibili | 1 + 6 | Terminazione del cablaggio adattatore |
| Presa PCM-0726 completa | 1 | Corpo, dado, O-ring e tappo compresi |
| Carrier display | 1 | Stampa, interfaccia modulo da confermare |
| Viti M3 carrier verso scocca | 4 | Svasate M3 x 10 con dadi |
| Viti M3 traversini posteriori | 4 | Cilindriche M3 x 10 con dadi |
| Viti/distanziatori modulo OLED verso carrier | da definire | Dipendono dal display posseduto, nessuna quota inventata |

Le fonti alternative non sono automaticamente intercambiabili. Restano da chiudere soltanto le quote esplicitamente segnate come provvisorie, i cablaggi e le prove sull'assieme; questa ricerca non certifica resistenza, grado IP o accuratezza della bilancia.

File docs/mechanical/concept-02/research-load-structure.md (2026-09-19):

# Componenti della struttura - Concept 02

Ricerca del 7 settembre 2026. Scopo: definire interfacce reali per un prototipo con **20 kg di carico utile**, piatto plastico e interno libero da nervature strutturali. Nessun ordine o preventivo trasmesso.

## 1. Selezione acquistabile

| Componente | Scelta | Quantita | Fonte e stato |
|---|---|---:|---|
| Cella single point | **Zemic L6D-C3-30kg-0.4B** | 1 | [Essmann, articolo 11250496](https://www.essmann-shop.com/en/single-point-load-cell-zemic-l6d-c3-30kg-0.4b/11250496): pagina consultata, EUR 56,60 esclusi IVA e trasporto, disponibilita indicata 2-5 giorni. |
| Piedi regolabili antiscivolo | **Elesa LX.30-SW17-AS-M6x22**, codice **531051** | 4 | [Elesa+Ganter](https://www.elesa-ganter.nl/p/lx-30-sw17-as-m6x22/127394/): prodotto esatto indicizzato; apertura diretta 403, prezzo e stock non confermati. Quote verificate sul PDF del produttore. |
| Viti cella, lato fisso | M6 x 25, ISO 4762, acciaio 8.8 zincato, **Keller 240912625** | 2 | [Keller & Kalmbach](https://www.keller-kalmbach.com/products/fasteners/screws/hexagon-socket-cap-screws/iso-4762--din-912-cap-screw/p/240912625): prodotto e quote verificati; vendita B2B, prezzo con account. |
| Viti cella, lato mobile | M6 x 45, **DIN 7991**, acciaio 10.9 zincato, **Accu SSK-M6-45-10.9-Z** | 2 | [Accu](https://www.accu.co.uk/countersunk-socket-head-screws/495060-SSK-M6-45-10-9-Z): prodotto e quote verificati, confezione da un pezzo; prezzo non rilevato. |
| Rondelle lato fisso | M6 ISO 7089, acciaio 200 HV | 2 | [Westfield Fasteners, variante 200 HV](https://www.westfieldfasteners.co.uk/BZP-Washer-M6.html), quote 6,4 x 12 x 1,6 mm. |
| Controdadi dei piedi | M6 DIN 934 acciaio zincato, **Essentra 051060040952 / 10180143** | 4 | [Essentra](https://www.essentracomponents.com/en-gb/p/standard-hex-nuts-metal/051060040952), chiave 10, altezza 5 mm; confezione industriale da 250. Si puo acquistare lo stesso standard da ferramenta in quantita minore. |
| Fermi di sovraccarico | M6 x 60 DIN 913, acciaio 45H, **RW Products D913V060060** | 4 | [RW Products](https://www.rwproducts.nl/din-913-stelschroef-binnenzeskant-met-afschuining-elvz-m6x60), chiave 3, passo 1; disponibilita dichiarata presso fornitore 2-5 giorni. |
| Controdadi dei fermi | M6 DIN 934, stesso articolo sopra | 4 | Stessa fonte Essentra; in totale otto dadi M6 tra piedi e fermi. |

Le quantita riguardano questo sottogruppo. La distinta generale del CAD comprende anche viti di scocca, piatto, elettronica e connettori.

## 2. Interfaccia della cella

Fonte primaria: **Zemic, L6D Rev12, dicembre 2022**, copia del produttore fornita da Essmann: [PDF online](https://www.essmann-shop.com/media/eb/a6/ea/1752248218/L6D_Datasheet.pdf?ts=1752248218), [copia locale](sources/Zemic-L6D-Rev12.pdf). Pagina 3 renderizzata e letta visivamente.

- Corpo **130 x 30 x 22 mm**; quattro filetti passanti **M6-6H** su rettangolo **106 x 15 mm**; centri a 12 mm dalle estremita longitudinali.
- Zone di appoggio terminali **25 x 30 mm**. Lato cavo fisso; lato freccia carico mobile. Riservare l'uscita cavo sia alta sia a mezza altezza.
- Piattaforma massima dichiarata **250 x 350 mm**. **Il PDF non associa le due dimensioni agli assi della cella**: l'orientamento del piatto 280 x 200 rispetto alla cella resta da confermare con Zemic.
- Portata nominale 30 kg, deflessione dichiarata 0,6-0,8 mm per questa fascia. Non usare il sovraccarico ammissibile come portata operativa.
- Il produttore indica viti M6 classe 8.8 lubrificate. La tabella di coppia distingue `<30 kg` e `>30 kg`, lasciando ambiguo il caso esatto **30 kg**. Confermare coppia e approvazione del fissaggio mobile svasato 10.9 prima del serraggio definitivo.

**Una divisione visualizzata di 1 g non equivale ad accuratezza di 1 g.** Il solo errore combinato C3 dichiarato, 0,020% del fondo scala, equivale qui a 6 g; a questo si aggiungono gli effetti dell'assemblaggio. La cella e il sistema vanno verificati con masse note e carichi eccentrici.

## 3. Piatto e supporti: produzione su disegno

La ricerca non ha individuato un telaio commerciale economico con disegno quotato completo e interfacce comprovate per questa cella. I bracket generici trovati su marketplace non vengono dichiarati compatibili. Non basta il testo "30 kg" per inserirli nel CAD come componenti pronti al montaggio.

La soluzione proposta mantiene **piatto esterno e scocca in plastica**, con quattro semplici parti in alluminio tagliato/lavorato. Il carico segue: piatto -> carrier mobile -> distanziale mobile -> cella -> distanziale fisso -> basamento -> piedi.

| Parte su misura | Dimensioni di progetto iniziali | Lavorazione |
|---|---|---|
| Basamento liscio | 300 x 320 x 6 mm | Alluminio 6061-T6, contorno raccordato, foratura e filetti secondo CAD. La superficie superiore resta piana salvo attacchi funzionali. |
| Carrier del piatto | 276 x 196 x 8 mm | Alluminio 6061-T6, fori svasati per fissaggio alla cella, fissaggi del piatto plastico; sbalzo plastico perimetrale nominale 2 mm. |
| Distanziale fisso | 25 x 30 x 6 mm | Alluminio, due passaggi viti sul passo 15 mm. |
| Distanziale mobile | 25 x 30 x 22 mm | Alluminio, due passaggi viti sul passo 15 mm. |
| Copertura/piatto plastico | Superficie 280 x 200 mm, pelle nominale 4 mm | PA12 MJF/SLS; geometria di aggancio e sede inferiore definite nel CAD. |

Queste dimensioni sono **scelte progettuali, non dimensioni di prodotti a catalogo**. La geometria effettiva da fabbricare e la sua distinta vengono generate dal CAD finale. L'altezza dei distanziali lascia libera la parte deformabile della cella.

Fornitori concreti: [JLCCNC - fresatura CNC](https://jlccnc.com/) per basamento, carrier e distanziali; [JLC3DP - stampa MJF/SLS](https://jlc3dp.com/) per piatto e scocca. Sono servizi cinesi di produzione su file, **non ricambi standard**. Il prezzo richiede caricamento dei file e conferma delle lavorazioni. Per una produzione locale gli stessi STEP e disegni possono essere forniti a un'officina CNC.

## 4. Innesti e quote ancora da validare

- Piedi: la scheda [Elesa LX, novembre 2025](https://www.elesa.com/siteassets/PDF/PDF_EN/LX.pdf), pagina 3, indica D30, corpo l2=12, L35 e L1=36 con pattino SBR. Quindi l'inviluppo inferiore con pattino e circa 13 mm. Una diversa edizione USA riporta stud piu corto di 1 mm: nel CAD si riserva l'inviluppo maggiore e si verifica il campione.
- Due viti fisse M6x25 attraversano rondella 1,6 + base 6 + distanziale 6: ingaggio nominale nella cella **11,4 mm**. Due svasate M6x45 attraversano carrier 8 + distanziale 22: ingaggio **15 mm**. Le svasate si misurano testa compresa; non aggiungere una rondella sotto la testa conica.
- I quattro piedi si regolano nei filetti **M6x1 del basamento**, poi si bloccano con i dadi superiori. Un solo dado superiore con foro libero non consentirebbe di regolare la quota sotto carico. I fermi M6x60 devono impegnare tutti i 6 mm del basamento.
- Svasata selezionata: DIN 7991, testa D12, altezza 3,3, cono 90 gradi, chiave 4. Non sostituirla con un generico ISO 10642 senza ricontrollare la testa e la sede.
- I fermi di sovraccarico sono parti del basamento, normalmente separati dal carrier. La loro regolazione richiede la deflessione reale della cella montata e le tolleranze dell'insieme; un gioco disegnato non prova che i fermi intervengano al carico corretto.
- 20 kg e l'obiettivo di carico **utile**. Il peso del sottogruppo mobile va sottratto al margine della cella da 30 kg. La resistenza complessiva, il creep, l'assenza di contatti parassiti e la stabilita sono verifiche del prototipo completo.

## 5. Evidenza disponibile

Il file [component-specs-load.json](component-specs-load.json) distingue quote del produttore (`CERTAIN`), scelte di progetto (`DESIGNED`) e dati mancanti o da verificare (`UNCONFIRMED`). Sono conservati i due PDF originali e le pagine quotate renderizzate sotto `sources/`. Nessuna modifica a firmware, pinout o hardware installato.

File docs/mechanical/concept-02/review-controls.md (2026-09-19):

# Concept 02 - verifica indipendente dei comandi e degli innesti

Oggetto: lettura del generatore `generate_assembly.py` e confronto con le fonti dei componenti; realizzazione dell'helper separato `controls_cable_details.py` integrato nel generatore. Il revisore non modifica il generatore principale. Non e una prova di stampa, montaggio fisico, resistenza, tenuta o compatibilita elettrica.

## 1. Geometrie controllate

- Due tastierini BerryBase B-SM4T da 70 x 20 x 1 mm, su due sedi 71 x 21: le superfici sono piane e complanari alla fascia inclinata. Le due membrane hanno 11 mm di separazione nominale. Il piatto inizia a Y=-50, mentre il bordo posteriore della membrana superiore rimane circa a Y=-88: circa 38 mm liberi davanti al piatto. Tra bordo destro della cornice OLED e bordo sinistro delle membrane restano 38 mm. Non emerge un'interferenza geometrica del piatto sopra i comandi.
- La cornice OLED e separata e rimovibile. Sono modellate quattro viti M3 svasate e quattro dadi per cornice/scocca, due traversini posteriori con quattro viti M3 e relativi dadi. Le teste posteriori sono raggiungibili dopo l'apertura del fondo. Il fissaggio non inventa interassi del PCB posseduto.
- Il connettore USB-C ha flangia verso l'interno e dado esterno. Il foro nominale di progetto e 12,4 mm nella parete da 3 mm. Il corpo commerciale conserva il filetto M12 x 1 e lo sbalzo verso l'esterno. Dado e tappo sono esplicitamente inviluppi provvisori.
- Le porte della scheda UPS sono state ricavate dal STEP ufficiale, usando le facce anteriori degli involucri e non il centro dell'intero componente. Le coordinate sono in `ups-port-reference.json`: con la trasformazione dell'assieme, entrambe le porte si aprono verso -X. USB-C ingresso ha centro circa (56,588;47,940;50,771); USB-A uscita circa (57,216;64,727;52,752). I cavi devono raggiungerle dal lato sinistro dell'UPS.

## 2. Innesti rappresentati nel CAD corrente

1. **Passacavo tastiera coperto.** Due ponti 24 x 11 x 2,4 mm coprono il tratto dello slot che esce dall'impronta della membrana e proteggono la curva della coda. I sei ritagli adesivi da 0,13 mm stanno all'esterno del rettangolo 70 x 20, senza appoggiare sui tasti. La posizione di uscita e lo spessore esterno del connettore BerryBase restano da campione; le misure Adafruit non provano intercambiabilita.
2. **Code, spine e adattatore tastiera presenti.** Ogni coda ha centrolinea curva di 76 mm e connettore femmina lungo nominalmente 12 mm, totale 88 mm. Le pieghe avvengono solo nel piano YZ; la prima coda scende 5 mm piu della seconda, evitando sovrapposizioni senza forzare curve laterali della membrana. Due pettini maschio 1 x 5, i dieci contatti inclusi, due fasci diametro 4,2 mm e una terminazione 1 x 6 con sei contatti descrivono l'ingombro dell'adattatore su misura. La terminazione e centrata a (-40,5;-48;25), sul vassoio elettronica; rami nominali 152,339 e 139,017 mm, taglio 200 mm. La topologia elettrica e nelle fonti controlli; le giunzioni interne dei singoli fili e la crimpatura non sono modellate a livello di fabbricazione.
3. **Cavi USB e fermacavi presenti.** I due percorsi rappresentano prolunga USB-C e uscita USB-A/5 V. Le spine arrivano alle porte da -X come richiesto dalle facce del STEP ufficiale. Due fermacavi apribili con quattro viti M3 fissano i cavi al fondo; la forma stampata del canale segue il percorso nominale.
4. **Sede O-ring USB semplificata.** Il corpo contiene una gola anulare per evitare l'interpenetrazione dell'anello con la flangia. La gola non e una quota costruttiva pubblicata del componente: rimane provvisoria fino al campione. Il CAD del passapannello rappresenta innesti e ingombri, senza pretendere una replica completa del componente acquistato.
5. **Ritegno UPS sulla lastra corretta.** Il STEP ufficiale colloca la lastra acrilica sotto le batterie: Z globale 21..22,5, con PCB a 47,5..49,1. Z massimo 59,6 corrisponde a un componente superiore e non e una superficie di serraggio. Il generatore corrente trattiene il bordo della lastra inferiore con due staffe rimovibili; la verifica dei contatti contro i singoli solidi ufficiali appartiene all'audit dell'assieme.
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

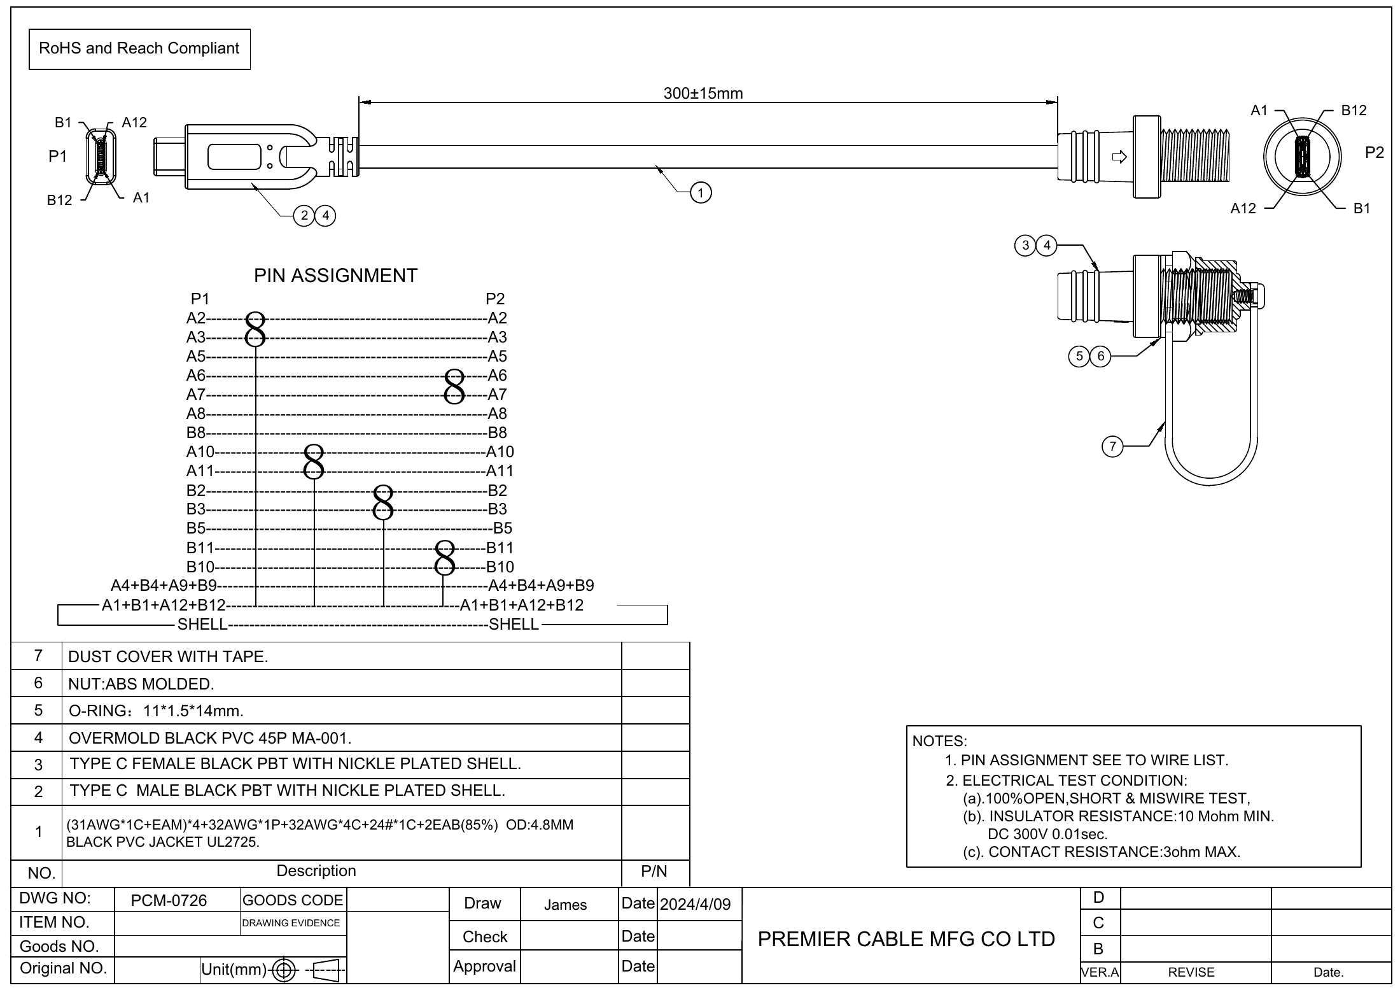
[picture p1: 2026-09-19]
docs/mechanical/concept-02/sources/adafruit-6069-full-drawing.png

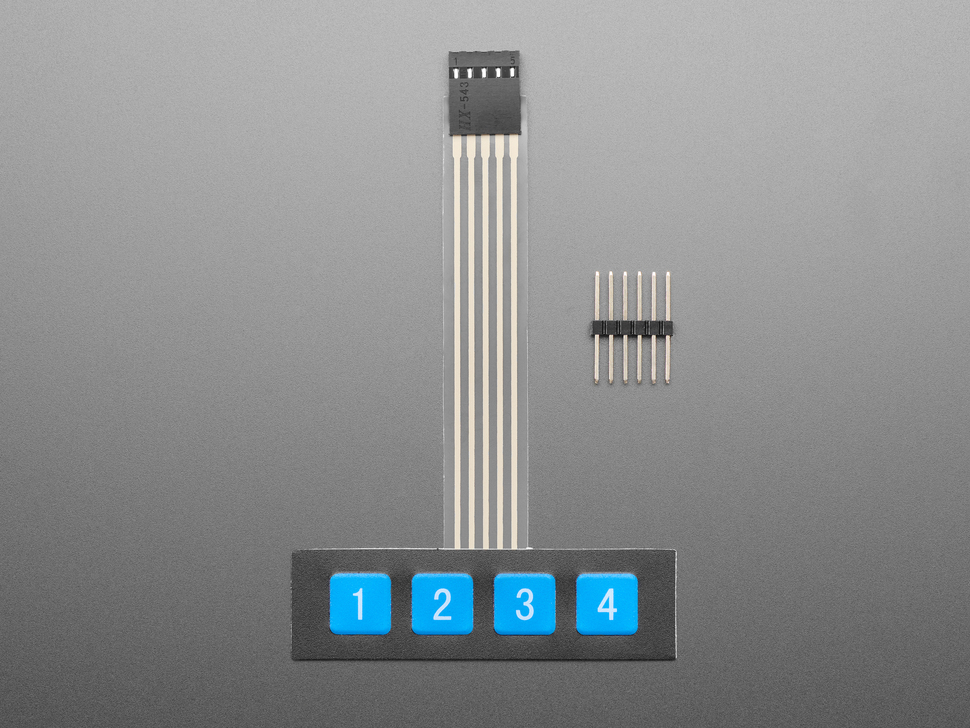
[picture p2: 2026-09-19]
docs/mechanical/concept-02/sources/adafruit-1332-top-reference.jpg

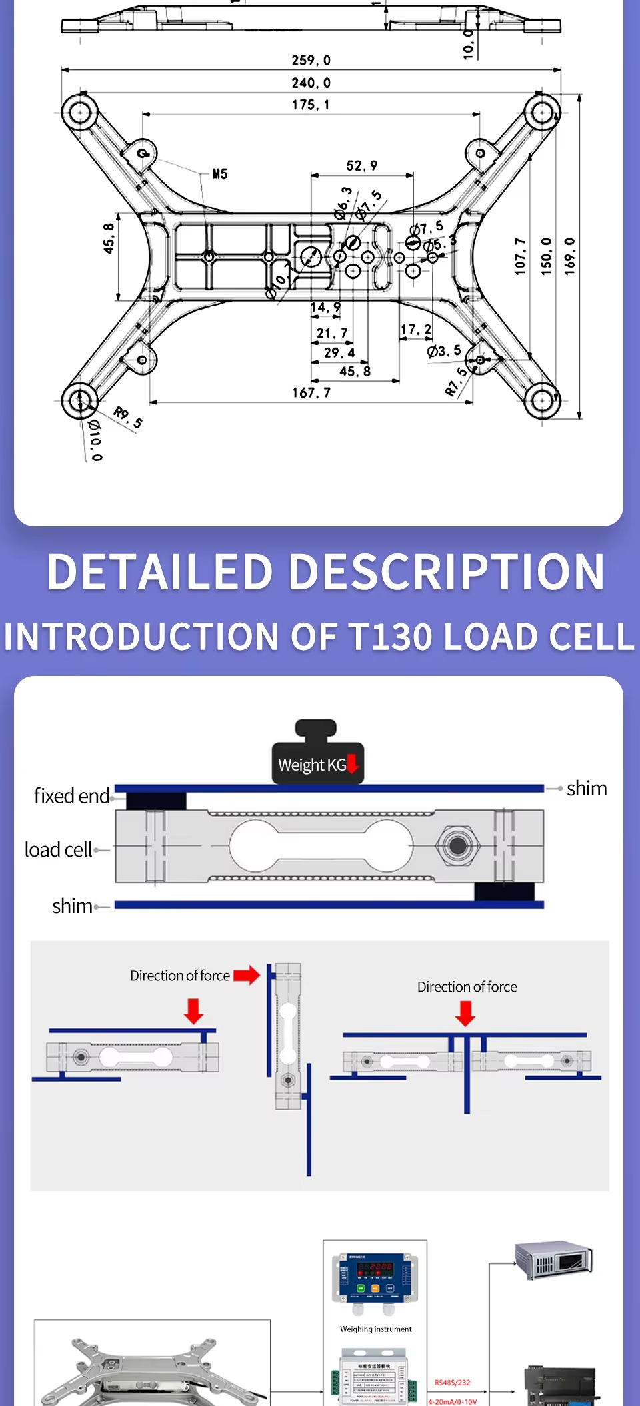
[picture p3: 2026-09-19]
docs/mechanical/prototype-affordability/sources/t130-03-drawing.png

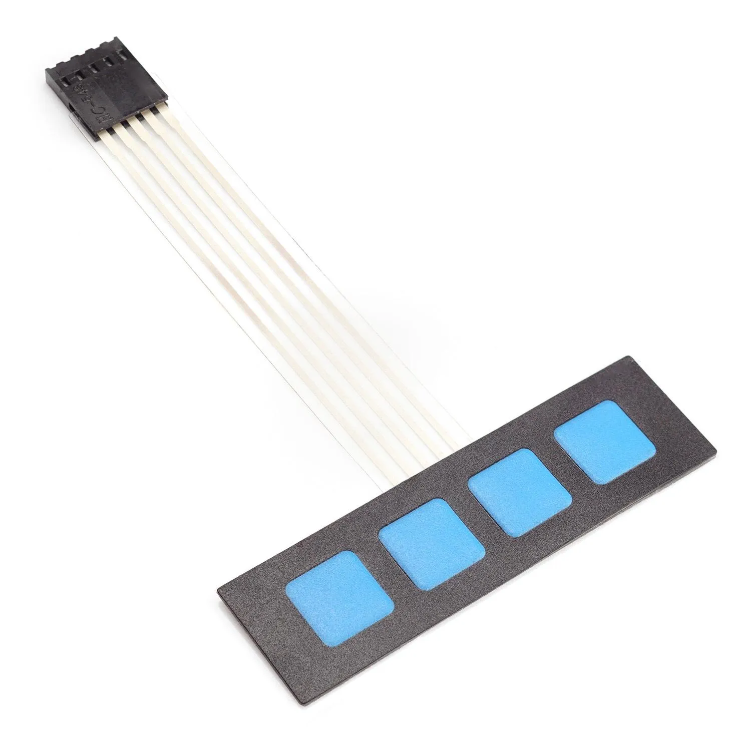
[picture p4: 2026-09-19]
docs/mechanical/concept-02/sources/berrybase-b-sm4t-reference.webp

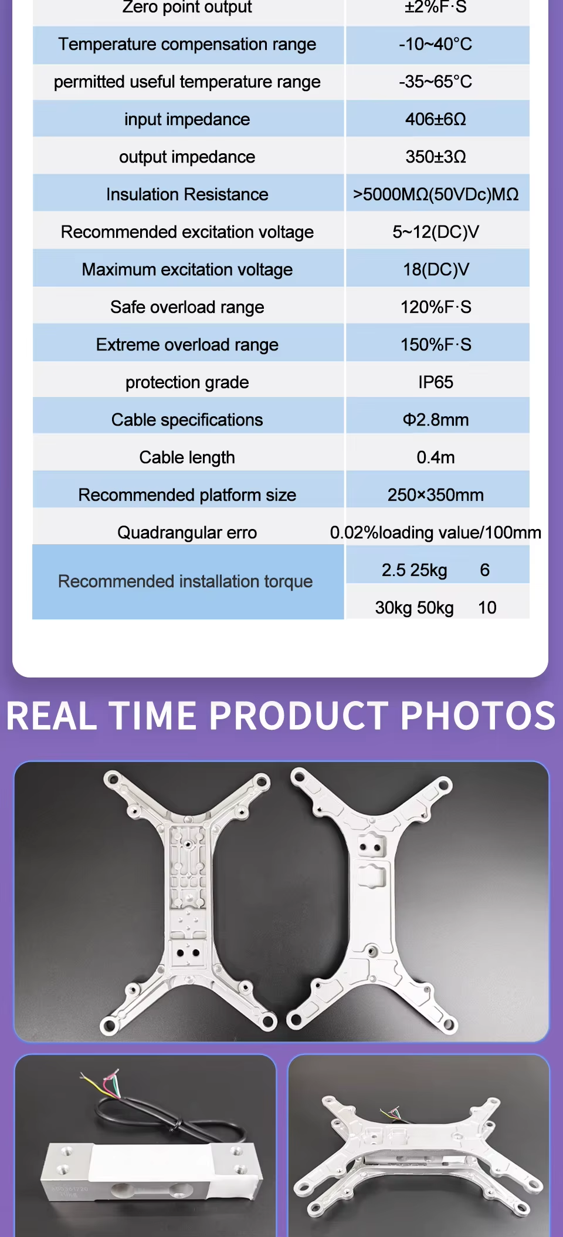
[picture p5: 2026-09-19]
docs/mechanical/prototype-affordability/sources/t130-04-specs.png

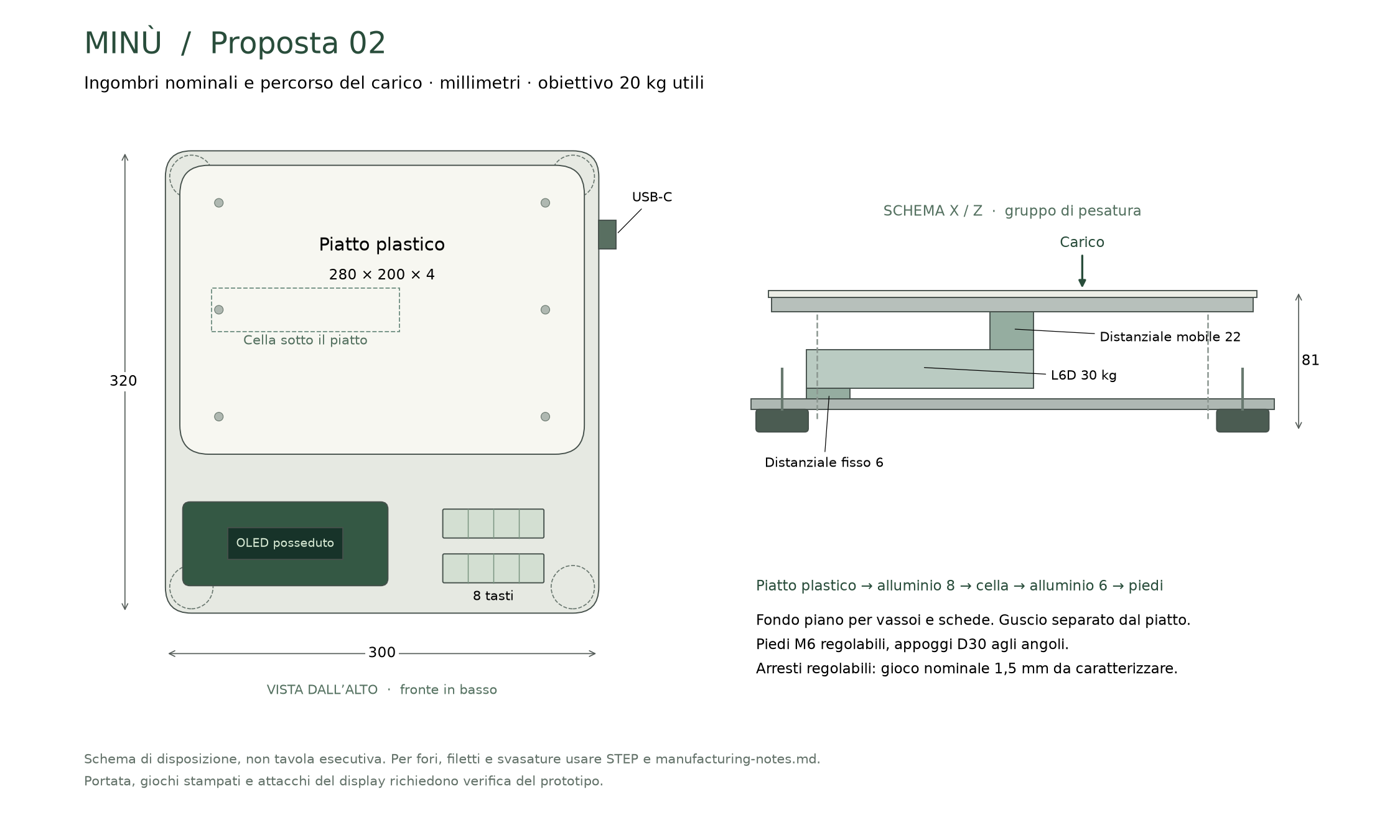
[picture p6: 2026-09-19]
docs/mechanical/concept-02/drawings/layout-and-load-path.png

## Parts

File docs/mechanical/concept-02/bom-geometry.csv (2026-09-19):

item | label | quantity | category | material | notes | source | cad_names
CNC_BASE_300x320x6 | Fondo portante piano alluminio 6 mm | 1 | custom | aluminium plate | Upper face smooth. Tapped holes shown at nominal major diameter; drawing must specify taps. |  | base_aluminium
PRINT_OUTER_SHELL | Scocca superiore rimovibile | 1 | printed | PA12 proposed | Non-load-bearing shell; 3 mm walls, captive M3 nuts. Validate printed fit. |  | outer_shell
CNC_CELL_FIXED_SPACER | Distanziale fisso cella 25 x30 x6 | 1 | custom | aluminium plate |  |  | cell_fixed_spacer
CNC_CELL_MOVING_SPACER | Distanziale mobile cella 25 x30 x22 | 1 | custom | aluminium bar |  |  | cell_moving_spacer
ZEMIC_L6D_C3_30KG_0_4B | Zemic L6D-C3-30kg - involucro meccanico | 1 | loadcell | aluminium purchased | Drawing envelope 130x30x22, holes M6 through 106x15. Internal strain geometry omitted. Platform axis acceptance and torque require supplier confirmation. | https://www.zemiceurope.com/media/Documentation/L6D_Datasheet.pdf | load_cell_l6d
CNC_CARRIER_276x196x8 | Portapiatto piano alluminio 8 mm | 1 | custom | aluminium plate | Two M6 countersinks; six tapped M3. No plastic load-bearing ribs. |  | plate_carrier_aluminium
PRINT_PAN_280x200x4 | Piatto plastico liscio 280 x200 x4 | 1 | printed | PA12 proposed | Supported over almost all its underside by the metal carrier; no food-contact certification. |  | plastic_pan
WASHER_M6_ISO7089 | Rondella M6 ISO7089 | 2 | fastener | steel 200HV |  |  | cell_fixed_washer_1; cell_fixed_washer_2
SCREW_M6x25_ISO4762 | Vite M6 x 25 testa cilindrica | 2 | fastener | steel | Simplified thread; nominal shank diameter. |  | cell_fixed_screw_1; cell_fixed_screw_2
SCREW_M6x45_DIN7991 | Vite svasata M6 x 45 | 2 | fastener | steel | M6 head D12 x 3.3; nominal simplified threads. |  | cell_moving_screw_1; cell_moving_screw_2
SCREW_M3x10_DIN7991 | Vite svasata M3 x 10 | 10 | fastener | steel | M6 head D12 x 3.3; nominal simplified threads. |  | pan_screw_1; pan_screw_2; pan_screw_3; pan_screw_4; pan_screw_5; pan_screw_6; display_bezel_screw_1; display_bezel_screw_2; display_bezel_screw_3; display_bezel_screw_4
SCREW_M3x16_ISO4762 | Vite M3 x 16 testa cilindrica | 12 | fastener | steel | Simplified thread; nominal shank diameter. |  | shell_screw_1; shell_screw_2; shell_screw_3; shell_screw_4; shell_screw_5; shell_screw_6; shell_screw_7; shell_screw_8; cable_clamp_screw_1_1; cable_clamp_screw_1_2; cable_clamp_screw_2_1; cable_clamp_screw_2_2
NUT_M3_DIN934 | Dado M3 | 16 | fastener | steel | Nominal thread; no helical geometry. |  | shell_nut_1; shell_nut_2; shell_nut_3; shell_nut_4; shell_nut_5; shell_nut_6; shell_nut_7; shell_nut_8; display_bar_nut_1_1; display_bar_nut_1_2; display_bar_nut_2_1; display_bar_nut_2_2; display_bezel_nut_1; display_bezel_nut_2; display_bezel_nut_3; display_bezel_nut_4
INCLUDED_FOOT_SBR | Pattino antiscivolo piede Elesa | 4 | feet | SBR supplied |  |  | foot_pad_1; foot_pad_2; foot_pad_3; foot_pad_4
ELESA_531051 | Piede Elesa LX.30-SW17-AS-M6x22 | 4 | feet | purchased foot simplified | Envelope D30, overall36 incl SBR. Profile simplified; stud measured nominal23 in EN drawing. | https://www.elesa.com/siteassets/PDF/PDF_EN/LX.pdf | adjustable_foot_1; adjustable_foot_2; adjustable_foot_3; adjustable_foot_4
NUT_M6_DIN934 | Dado M6 | 8 | fastener | steel | Nominal thread; no helical geometry. |  | foot_locknut_1; foot_locknut_2; foot_locknut_3; foot_locknut_4; overload_locknut_1; overload_locknut_2; overload_locknut_3; overload_locknut_4
SETSCREW_M6x60_DIN913_FLAT_END | Grano M6 x60 arresto regolabile | 4 | fastener | steel | Tip Z67.5; carrier Z69 => provisional1.5mm gap. Full6mm base engagement, locknut. Never preload the measuring plate. | https://www.rwproducts.nl/din-913-stelschroef-binnenzeskant-met-afschuining-elvz-m6x60 | overload_stop_1; overload_stop_2; overload_stop_3; overload_stop_4
PRINT_POWER_TRAY | Vassoio potenza rimovibile | 1 | printed | PA12 proposed | Generic edge-guided tray; no invented UPS PCB mounting pattern. |  | power_tray
PRINT_POWER_RETAINING_STRAP | Staffa rimovibile ritegno verticale UPS | 2 | printed | PA12 proposed | Clamps official lower acrylic sheet at Z22.5. Bridge top24.5 leaves nominal0.9mm below battery envelope. Verify printed fit; no PCB/pogo contact. |  | power_retaining_strap_1; power_retaining_strap_2
SCREW_M3x10_ISO4762 | Vite M3 x 10 testa cilindrica | 8 | fastener | steel | Simplified thread; nominal shank diameter. |  | power_tray_screw_1; power_tray_screw_2; power_tray_screw_3; power_tray_screw_4; display_bar_screw_1_1; display_bar_screw_1_2; display_bar_screw_2_1; display_bar_screw_2_2
PRINT_ELECTRONICS_TRAY | Piastra elettronica universale rimovibile - faccia piana | 1 | printed | PA12 proposed | Flat 145x62 area for existing boards; no assumed module holes. Use removable insulating mounts after measuring boards. |  | electronics_tray
SCREW_M3x8_ISO4762 | Vite M3 x 8 testa cilindrica | 4 | fastener | steel | Simplified thread; nominal shank diameter. |  | electronics_tray_screw_1; electronics_tray_screw_2; electronics_tray_screw_3; electronics_tray_screw_4
INCLUDED_UPS_VENDOR_GEOMETRY | PCB UPS HAT(D) 001 | 297 | electronics_detail | vendor STEP geometry | One of 297 named solids from the official supplied assembly. Included in one CN kit SKU25507, not a separate purchase. | https://www.waveshare.net/shop/UPS-HAT-D.htm | ups_vendor_001; ups_vendor_002; ups_vendor_003; ups_vendor_004; ups_vendor_005; ups_vendor_006; ups_vendor_007; ups_vendor_008; ups_vendor_009; ups_vendor_010; ups_vendor_011; ups_vendor_012; ups_vendor_013; ups_vendor_014; ups_vendor_015; ups_vendor_016; ups_vendor_017; ups_vendor_018; ups_vendor_019; ups_vendor_020; ups_vendor_021; ups_vendor_022; ups_vendor_023; ups_vendor_024; ups_vendor_025; ups_vendor_026; ups_vendor_027; ups_vendor_028; ups_vendor_029; ups_vendor_030; ups_vendor_031; ups_vendor_032; ups_vendor_033; ups_vendor_034; ups_vendor_035; ups_vendor_036; ups_vendor_037; ups_vendor_038; ups_vendor_039; ups_vendor_040; ups_vendor_041; ups_vendor_042; ups_vendor_043; ups_vendor_044; ups_vendor_045; ups_vendor_046; ups_vendor_047; ups_vendor_048; ups_vendor_049; ups_vendor_050; ups_vendor_051; ups_vendor_052; ups_vendor_053; ups_vendor_054; ups_vendor_055; ups_vendor_056; ups_vendor_057; ups_vendor_058; ups_vendor_059; ups_vendor_060; ups_vendor_061; ups_vendor_062; ups_vendor_063; ups_vendor_064; ups_vendor_065; ups_vendor_066; ups_vendor_067; ups_vendor_068; ups_vendor_069; ups_vendor_070; ups_vendor_071; ups_vendor_072; ups_vendor_073; ups_vendor_074; ups_vendor_075; ups_vendor_076; ups_vendor_077; ups_vendor_078; ups_vendor_079; ups_vendor_080; ups_vendor_081; ups_vendor_082; ups_vendor_083; ups_vendor_084; ups_vendor_085; ups_vendor_086; ups_vendor_087; ups_vendor_088; ups_vendor_089; ups_vendor_090; ups_vendor_091; ups_vendor_092; ups_vendor_093; ups_vendor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
PRINT_DISPLAY_BEZEL | Cornice OLED sostituibile con sede universale | 1 | printed | PA12 proposed | Pocket 101.5 x 34.5 x 11.3; owned SSD1322 module must be measured. |  | display_bezel
CUT_DISPLAY_WINDOW | Vetrino piano OLED 82 x 24 x 1.5 | 1 | custom | clear acrylic | Fit with thin perimeter adhesive; no food-contact claim. |  | display_window
REUSE_OLED_SSD1322 | OLED SSD1322 - inviluppo da confermare | 1 | electronics | reference envelope | Unverified owned module envelope; no invented board hole pattern. |  | oled_reference
PRINT_DISPLAY_REAR_BAR | Traversino fermo OLED | 2 | printed | PA12 proposed |  |  | display_rear_bar_1; display_rear_bar_2
KEYPAD_1x4_BERRYBASE_B_SM4T | Tastiera adesiva 1x4 - striscia 1 | 2 | controls | membrane purchased | 70x20x1 mm blank membrane; final function overlay is a custom print. Tail exit must be checked on purchased sample. | https://www.berrybase.de/en/membrane-keypad-4-keys-without-labelling-with-adhesive-layer | keypad_strip_1; keypad_strip_2
USB_C_PANEL_6069 | USB-C pannello PCM-0726 / Adafruit 6069 | 1 | controls | purchased connector | M12x1 x15; flange D18x6; rear D11x10. Internal flange; external nut. | https://www.adafruit.com/product/6069 | usb_c_panel_body
INCLUDED_USB_NUT | Dado plastico USB-C - ingombro provvisorio | 1 | fastener | ABS supplied | Outer D20 x4 assumed; maker does not dimension nut. |  | usb_c_panel_nut
INCLUDED_USB_ORING | O-ring USB-C incluso | 1 | fastener | elastomer supplied | Ring simplified as rectangular section; actual 11 ID x1.5 circular cross-section. |  | usb_c_panel_seal
INCLUDED_USB_CAP | Tappo USB-C parcheggiato - ingombro | 1 | controls | elastomer supplied | D18x4 assumed. Parked display position only; flexible tether is not dimensioned. |  | usb_c_protective_cap_parked
INCLUDED_USB_C_PLUG_BODY | Spina USB-C interna - inviluppo | 1 | controls | purchased connector envelope | Plug envelope assumed; board socket mouth comes from official STEP. |  | usb_c_internal_plug_body
INCLUDED_USB_C_PLUG_METAL | Innesto USB-C nella UPS | 1 | controls | metal connector envelope | Nominal envelope, electrical contact details omitted. |  | usb_c_internal_plug_metal
USB_A_OUTPUT_HARNESS_2697 | Spina USB-A uscita 5 V - inviluppo | 1 | controls | purchased connector envelope | Adafruit2697 22AWG harness cut to200mm; custom terminal end, no barrel connector remains. | https://www.adafruit.com/product/2697 | usb_a_output_plug_body
INCLUDED_USB_A_PLUG_METAL | Innesto USB-A nella UPS | 1 | controls | metal connector envelope | Nominal envelope, electrical contact details omitted. |  | usb_a_output_plug_metal
INCLUDED_USB_C_CABLE_300MM | Cavo USB-C pannello 300 mm - percorso | 1 | cable | routed cable envelope | Illustrative routed centreline 303.7 mm; supplied/cut cable nominal 300 mm. Connector bodies and service slack require sample fitting. |  | usb_c_passive_cable
CUSTOM_USB_A_5V_HARNESS_200MM | Cablaggio uscita 5 V 200 mm - percorso | 1 | cable | routed cable envelope | Illustrative routed centreline 188.9 mm; supplied/cut cable nominal 200 mm. Connector bodies and service slack require sample fitting. |  | usb_a_5v_output_cable
PRINT_CABLE_CLAMP_LOWER | Fermacavo apribile - base | 2 | printed | PA12 proposed | D5.4 cable channel; removable split clamp. |  | cable_clamp_lower_1; cable_clamp_lower_2
PRINT_CABLE_CLAMP_UPPER | Fermacavo apribile - coperchio | 2 | printed | PA12 proposed |  |  | cable_clamp_upper_1; cable_clamp_upper_2
CUSTOM_5V_TERMINATION | Terminazione 5 V sul vano elettronica - riferimento | 1 | electronics | terminal envelope | Interface location only. Actual existing5V rail connector and polarity must be verified before wiring. |  | 5v_terminal_reference
INCLUDED_L6D_4WIRE_CABLE_400MM | Cavo cella verso HX711 - percorso | 1 | cable | routed cable envelope | Illustrative routed centreline 386.1 mm; supplied/cut cable nominal 400 mm. Connector bodies and service slack require sample fitting. |  | load_cell_4wire_cable
INCLUDED_L6D_WIRE_END | Conduttore cella verso HX711 | 4 | cable | wire end envelope | Four free ends for E+/E-/A+/A-. Actual module solder/terminal location is not assumed. |  | load_cell_wire_end_1; load_cell_wire_end_2; load_cell_wire_end_3; load_cell_wire_end_4
PRINT_KEYPAD_CABLE_HOOD | Ponte copricoda tastiera adesivo | 2 | printed | PA12 proposed | 24x11x2.4 cover; adhesive feet outside 70x20 membrane. No claim of liquid sealing; fit bend on sample. |  | keypad_cable_hood_1; keypad_cable_hood_2
CUT_3M468MP_KEYPAD_HOOD_PAD | Adesivo copricoda 0.13 mm | 6 | custom | 3M468MP proposed | Manufacturer tape thickness0.13; adhesion to finished PA12 must be tested. Cut piece, not a full roll. | https://www.3m.com/3M/en_US/p/dc/v100808810/ | keypad_hood_adhesive_1_1; keypad_hood_adhesive_1_2; keypad_hood_adhesive_1_3; keypad_hood_adhesive_2_1; keypad_hood_adhesive_2_2; keypad_hood_adhesive_2_3
INCLUDED_KEYPAD_TAIL | Coda tastiera curva - inviluppo 88 mm con connettore | 2 | cable | flex envelope | 76mm routed flex +12mm provisional connector =88mm. Width14.28 and thickness0.3 assumed; BerryBase only publishes total length. Bend radii2/4mm require sample validation. |  | keypad_tail_1; keypad_tail_2
INCLUDED_KEYPAD_5P_FEMALE | Connettore femmina 5 pin incluso nella membrana | 2 | controls | purchased connector envelope | Pitch2.54 documented; 14.28x12x4 body and cavity details are provisional, measure selected BerryBase sample. |  | keypad_female_connector_1; keypad_female_connector_2
HEADER_1x5_2p54 | Pettine maschio 1x5 adattatore tastiera | 2 | controls | header body envelope | Nominal1x5 cut header; assembled adapter, verify pin assignment by continuity. |  | keypad_adapter_header_body_1; keypad_adapter_header_body_2
INCLUDED_HEADER_CONTACT | Contatto pettine tastiera | 10 | fastener | header contact | Nominal square0.64mm contact, included with1x5 header. |  | keypad_adapter_header_pin_1_1; keypad_adapter_header_pin_1_2; keypad_adapter_header_pin_1_3; keypad_adapter_header_pin_1_4; keypad_adapter_header_pin_1_5; keypad_adapter_header_pin_2_1; keypad_adapter_header_pin_2_2; keypad_adapter_header_pin_2_3; keypad_adapter_header_pin_2_4; keypad_adapter_header_pin_2_5
CUSTOM_KEYPAD_MATRIX_BRANCH | Cablaggio su misura matrice tastiera - ramo | 2 | cable | routed cable envelope | Illustrative routed centreline 152.3 mm; supplied/cut cable nominal 200 mm. Connector bodies and service slack require sample fitting. |  | keypad_adapter_branch_1; keypad_adapter_branch_2
HOUSING_1x6_2p54 | Terminazione adattatore tastiera 6 fili | 1 | controls | connector envelope | Generic6-way termination positioned above electronics tray. Pitch2.54; body depth/height provisional. Not a verified mating socket on owned ESP32; wire lengths and pin order require assembly. | https://www.berrybase.de/en/dupont-housing-1x6-pin | keypad_matrix_6p_termination
CRIMP_CONTACT_2p54 | Contatto terminazione tastiera 6 fili | 6 | fastener | connector contact envelope | Generic compatible crimp contact envelope; order contact and housing from one matched family. |  | keypad_matrix_terminal_contact_1; keypad_matrix_terminal_contact_2; keypad_matrix_terminal_contact_3; keypad_matrix_terminal_contact_4; keypad_matrix_terminal_contact_5; keypad_matrix_terminal_contact_6

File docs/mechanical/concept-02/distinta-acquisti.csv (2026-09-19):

id | quantity | order_quantity | order_unit | description | action | sku | url | notes | cad_parts
CNC_BASE_300x320x6 | 1 | 1 | pezzo | Fondo portante piano alluminio 6 mm | Lavorare su file | 6061-T6, pezzo a disegno | https://jlccnc.com/ | Faccia superiore piana. Fori filettati rappresentati al diametro nominale; usare le specifiche di maschiatura nelle note CNC. | base_aluminium
PRINT_OUTER_SHELL | 1 | 1 | pezzo | Scocca superiore rimovibile | Stampare su file | PA12 MJF/SLS, pezzo a disegno | https://jlc3dp.com/ | Guscio rimovibile, pareti da 3 mm e sedi per dadi M3. Giochi delle sedi da verificare con lo stampatore. | outer_shell
CNC_CELL_FIXED_SPACER | 1 | 1 | pezzo | Distanziale fisso cella 25 x30 x6 | Lavorare su file | 6061-T6, pezzo a disegno | https://jlccnc.com/ | Distanziale fisso da 6 mm; superfici di serraggio piane e sbavate secondo le note CNC. | cell_fixed_spacer
CNC_CELL_MOVING_SPACER | 1 | 1 | pezzo | Distanziale mobile cella 25 x30 x22 | Lavorare su file | 6061-T6, pezzo a disegno | https://jlccnc.com/ | Distanziale mobile da 22 mm; mantiene il portapiatto separato dal guscio. | cell_moving_spacer
ZEMIC_L6D_C3_30KG_0_4B | 1 | 1 | pezzo | Zemic L6D-C3-30kg - involucro meccanico | Acquistare | Essmann 11250496 | https://www.essmann-shop.com/en/single-point-load-cell-zemic-l6d-c3-30kg-0.4b/11250496 | Cella 30 kg; carico utile di progetto 20 kg, accuratezza 1 g non provata. | load_cell_l6d
CNC_CARRIER_276x196x8 | 1 | 1 | pezzo | Portapiatto piano alluminio 8 mm | Lavorare su file | 6061-T6, pezzo a disegno | https://jlccnc.com/ | Due svasature M6 e sei filetti M3. Sostiene quasi tutta la superficie inferiore del piatto plastico. | plate_carrier_aluminium
PRINT_PAN_280x200x4 | 1 | 1 | pezzo | Piatto plastico liscio 280 x200 x4 | Stampare su file | PA12 MJF/SLS, pezzo a disegno | https://jlc3dp.com/ | Piatto da stampare, sostenuto dal portapiatto metallico; sei viti M3 svasate. | plastic_pan
WASHER_M6_ISO7089 | 2 | 2 | pezzi | Rondella M6 ISO7089 | Acquistare | ISO7089 M6 200HV | https://www.westfieldfasteners.co.uk/BZP-Washer-M6.html | 6,4 x12 x1,6 mm. | cell_fixed_washer_1; cell_fixed_washer_2
SCREW_M6x25_ISO4762 | 2 | 2 | pezzi | Vite M6 x 25 testa cilindrica | Acquistare | Keller 240912625, 8.8 | https://www.keller-kalmbach.com/products/fasteners/screws/hexagon-socket-cap-screws/iso-4762--din-912-cap-screw/p/240912625 | Lato fisso della cella; rondella ISO7089. | cell_fixed_screw_1; cell_fixed_screw_2
SCREW_M6x45_DIN7991 | 2 | 2 | pezzi | Vite svasata M6 x 45 | Acquistare | Accu SSK-M6-45-10.9-Z | https://www.accu.co.uk/countersunk-socket-head-screws/495060-SSK-M6-45-10-9-Z | Lato mobile; testa D12, cono90. Coppia e giunto da confermare con Zemic. | cell_moving_screw_1; cell_moving_screw_2
SCREW_M3x10_DIN7991 | 10 | 10 | pezzi | Vite svasata M3 x 10 | Acquistare | Orbital 5500020 A4 | https://www.orbitalfasteners.co.uk/products/m3x10-csk-skt-screw-stst-a4-din-7991 | Testa D6; svasatura90; lunghezza totale10. | pan_screw_1; pan_screw_2; pan_screw_3; pan_screw_4; pan_screw_5; pan_screw_6; display_bezel_screw_1; display_bezel_screw_2; display_bezel_screw_3; display_bezel_screw_4
SCREW_M3x16_ISO4762 | 12 | 12 | pezzi | Vite M3 x 16 testa cilindrica | Acquistare | Westfield WF14263 A4 | https://www.westfieldfasteners.co.uk/Bolts-Screws-Metric/A4-Socket-Head-Cap-Screw-M3x16mm.html | Testa D5,5 x3. | shell_screw_1; shell_screw_2; shell_screw_3; shell_screw_4; shell_screw_5; shell_screw_6; shell_screw_7; shell_screw_8; cable_clamp_screw_1_1; cable_clamp_screw_1_2; cable_clamp_screw_2_1; cable_clamp_screw_2_2
NUT_M3_DIN934 | 16 | 16 | pezzi | Dado M3 | Acquistare | Westfield WF15111 | https://www.westfieldfasteners.co.uk/Metric-Nuts/Hex-Nut-M3-Bright-Zinc-Plate-Class-8.html | Chiave5,5, altezza2,4; sedi captive stampate. | shell_nut_1; shell_nut_2; shell_nut_3; shell_nut_4; shell_nut_5; shell_nut_6; shell_nut_7; shell_nut_8; display_bar_nut_1_1; display_bar_nut_1_2; display_bar_nut_2_1; display_bar_nut_2_2; display_bezel_nut_1; display_bezel_nut_2; display_bezel_nut_3; display_bezel_nut_4
INCLUDED_FOOT_SBR | 4 | 0 | pezzi | Pattino antiscivolo piede Elesa | Incluso nel componente | INCLUDED_FOOT_SBR |  | Non acquistare separatamente. | foot_pad_1; foot_pad_2; foot_pad_3; foot_pad_4
ELESA_531051 | 4 | 4 | pezzi | Piede Elesa LX.30-SW17-AS-M6x22 | Acquistare | Elesa 531051 | https://www.elesa-ganter.nl/p/lx-30-sw17-as-m6x22/127394/ | 4 piedi completi di pattino; filetto M6 nel basamento. | adjustable_foot_1; adjustable_foot_2; adjustable_foot_3; adjustable_foot_4
NUT_M6_DIN934 | 8 | 8 | pezzi | Dado M6 | Acquistare | M6 DIN934 zincato | https://www.essentracomponents.com/en-gb/p/standard-hex-nuts-metal/051060040952 | Chiave10, altezza5. Acquistabile a standard anche in ferramenta. | foot_locknut_1; foot_locknut_2; foot_locknut_3; foot_locknut_4; overload_locknut_1; overload_locknut_2; overload_locknut_3; overload_locknut_4
SETSCREW_M6x60_DIN913_FLAT_END | 4 | 4 | pezzi | Grano M6 x60 arresto regolabile | Acquistare | RW D913V060060, DIN913 45H | https://www.rwproducts.nl/din-913-stelschroef-binnenzeskant-met-afschuining-elvz-m6x60 | 4 fermi regolabili; gioco di progetto da tarare sul prototipo. | overload_stop_1; overload_stop_2; overload_stop_3; overload_stop_4
PRINT_POWER_TRAY | 1 | 1 | pezzo | Vassoio potenza rimovibile | Stampare su file | PA12 MJF/SLS, pezzo a disegno | https://jlc3dp.com/ | Vassoio isolante rimovibile del gruppo UPS, con quattro fissaggi al fondo. | power_tray
PRINT_POWER_RETAINING_STRAP | 2 | 2 | pezzi | Staffa rimovibile ritegno verticale UPS | Stampare su file | PA12 MJF/SLS, pezzo a disegno | https://jlc3dp.com/ | Due staffe trattengono il bordo della lastra acrilica inferiore del kit UPS; stampare entrambi i file, le sagome differiscono. | power_retaining_strap_1; power_retaining_strap_2
SCREW_M3x10_ISO4762 | 8 | 8 | pezzi | Vite M3 x 10 testa cilindrica | Acquistare | Westfield WF14261 A4 | https://www.westfieldfasteners.co.uk/A4-ScrewBolt-SHCap-M3.html | Selezionare M3 x10, testa D5,5 x3. | power_tray_screw_1; power_tray_screw_2; power_tray_screw_3; power_tray_screw_4; display_bar_screw_1_1; display_bar_screw_1_2; display_bar_screw_2_1; display_bar_screw_2_2
PRINT_ELECTRONICS_TRAY | 1 | 1 | pezzo | Piastra elettronica universale rimovibile - faccia piana | Stampare su file | PA12 MJF/SLS, pezzo a disegno | https://jlc3dp.com/ | Superficie piana isolante per le schede possedute. I loro singoli attacchi richiedono le misure dei PCB. | electronics_tray
SCREW_M3x8_ISO4762 | 4 | 4 | pezzi | Vite M3 x 8 testa cilindrica | Acquistare | Westfield WF14272 A4 | https://www.westfieldfasteners.co.uk/A4-ScrewBolt-SHCap-M3.html | Selezionare M3 x8, testa D5,5 x3. | electronics_tray_screw_1; electronics_tray_screw_2; electronics_tray_screw_3; electronics_tray_screw_4
PRINT_DISPLAY_BEZEL | 1 | 1 | pezzo | Cornice OLED sostituibile con sede universale | Stampare su file | PA12 MJF/SLS, pezzo a disegno | https://jlc3dp.com/ | Cornice sostituibile; sede del modulo e superficie sicura di serraggio da adattare al display posseduto. | display_bezel
CUT_DISPLAY_WINDOW | 1 | 1 | pezzo | Vetrino piano OLED 82 x 24 x 1.5 | Tagliare su file | PMMA trasparente 1,5 mm | https://jlccnc.com/ | Richiedere taglio/fresatura82x24x1,5; tolleranza e disponibilita lastra da preventivo. | display_window
REUSE_OLED_SSD1322 | 1 | 0 | pezzi | OLED SSD1322 - inviluppo da confermare | Riutilizzare | Posseduto: SSD1322 SPI256x64 3,12pollici |  | Non acquistare. Ingombro e serraggio carrier da adattare al modulo reale. | oled_reference
PRINT_DISPLAY_REAR_BAR | 2 | 2 | pezzi | Traversino fermo OLED | Stampare su file | PA12 MJF/SLS, pezzo a disegno | https://jlc3dp.com/ | Due traversini rimovibili. Verificare che il modulo reale abbia bordi liberi sui quali serrare. | display_rear_bar_1; display_rear_bar_2
KEYPAD_1x4_BERRYBASE_B_SM4T | 2 | 2 | pezzi | Tastiera adesiva 1x4 - striscia 1 | Acquistare | BerryBase B-SM4T | https://www.berrybase.de/en/membrane-keypad-4-keys-without-labelling-with-adhesive-layer | 2 membrane adesive70x20x1, totale8tasti. Pinout/coda da campione. Origine Cina. | keypad_strip_1; keypad_strip_2
USB_C_PANEL_6069 | 1 | 1 | pezzo | USB-C pannello PCM-0726 / Adafruit 6069 | Acquistare | Premier PCM-0726 / Adafruit6069 | https://www.adafruit.com/product/6069 | Prolunga USB-C300mm, include dado, O-ring e tappo. Alternativa diretta Cina in research-controls.md. | usb_c_panel_body
INCLUDED_USB_NUT | 1 | 0 | pezzi | Dado plastico USB-C - ingombro provvisorio | Incluso nel componente | INCLUDED_USB_NUT |  | Non acquistare separatamente. Outer D20 x4 assumed; maker does not dimension nut. | usb_c_panel_nut
INCLUDED_USB_ORING | 1 | 0 | pezzi | O-ring USB-C incluso | Incluso nel componente | INCLUDED_USB_ORING |  | Non acquistare separatamente. Ring simplified as rectangular section; actual 11 ID x1.5 circular cross-section. | usb_c_panel_seal
INCLUDED_USB_CAP | 1 | 0 | pezzi | Tappo USB-C parcheggiato - ingombro | Incluso nel componente | INCLUDED_USB_CAP |  | Non acquistare separatamente. D18x4 assumed. Parked display position only; flexible tether is not dimensioned. | usb_c_protective_cap_parked
INCLUDED_USB_C_PLUG_BODY | 1 | 0 | pezzi | Spina USB-C interna - inviluppo | Incluso nel componente | INCLUDED_USB_C_PLUG_BODY |  | Non acquistare separatamente. Plug envelope assumed; board socket mouth comes from official STEP. | usb_c_internal_plug_body
INCLUDED_USB_C_PLUG_METAL | 1 | 0 | pezzi | Innesto USB-C nella UPS | Incluso nel componente | INCLUDED_USB_C_PLUG_METAL |  | Non acquistare separatamente. Nominal envelope, electrical contact details omitted. | usb_c_internal_plug_metal
USB_A_OUTPUT_HARNESS_2697 | 1 | 1 | pezzo | Spina USB-A uscita 5 V - inviluppo | Acquistare | Adafruit 2697, 22 AWG | https://www.adafruit.com/product/2697 | Un cavo da 1 m: conservare USB-A, accorciare a circa 200 mm ed eliminare il jack. Terminare sulla distribuzione 5 V posseduta dopo verifica elettrica. | usb_a_output_plug_body
INCLUDED_USB_A_PLUG_METAL | 1 | 0 | pezzi | Innesto USB-A nella UPS | Incluso nel componente | INCLUDED_USB_A_PLUG_METAL |  | Non acquistare separatamente. Nominal envelope, electrical contact details omitted. | usb_a_output_plug_metal
INCLUDED_USB_C_CABLE_300MM | 1 | 0 | pezzi | Cavo USB-C pannello 300 mm - percorso | Incluso nel componente | INCLUDED_USB_C_CABLE_300MM |  | Non acquistare separatamente. Illustrative routed centreline 303.7 mm; supplied/cut cable nominal 300 mm. Connector bodies and service slack require sample fitting. | usb_c_passive_cable
CUSTOM_USB_A_5V_HARNESS_200MM | 1 | 0 | pezzi | Cablaggio uscita 5 V 200 mm - percorso | Incluso nel cablaggio | Adafruit2697 22AWG da accorciare | https://www.adafruit.com/product/2697 | Ricavato dal cavo Adafruit 2697 già elencato; non acquistare un secondo cavo. Percorso CAD indicativo; lunghezza e terminali secondo montaggio. Illustrative routed centreline 188.9 mm; supplied/cut cable nominal 200 mm. Connector bodies and service slack require sample fitting. | usb_a_5v_output_cable
PRINT_CABLE_CLAMP_LOWER | 2 | 2 | pezzi | Fermacavo apribile - base | Stampare su file | PA12 MJF/SLS, pezzo a disegno | https://jlc3dp.com/ | Due guide apribili per i percorsi USB; usare i file distinti per le due posizioni. | cable_clamp_lower_1; cable_clamp_lower_2
PRINT_CABLE_CLAMP_UPPER | 2 | 2 | pezzi | Fermacavo apribile - coperchio | Stampare su file | PA12 MJF/SLS, pezzo a disegno | https://jlc3dp.com/ | Coperchi delle guide con quattro viti M3 complessive. Diametro e curvatura dei cavi reali da verificare. | cable_clamp_upper_1; cable_clamp_upper_2
CUSTOM_5V_TERMINATION | 1 | 0 | pezzi | Terminazione 5 V sul vano elettronica - riferimento | Riutilizzare / adattare | Interfaccia alla distribuzione 5 V posseduta |  | Segnaposto di interfaccia, non un morsetto commerciale selezionato. Sagoma e innesto da adattare alla scheda reale. | 5v_terminal_reference
INCLUDED_L6D_4WIRE_CABLE_400MM | 1 | 0 | pezzi | Cavo cella verso HX711 - percorso | Incluso nel componente | INCLUDED_L6D_4WIRE_CABLE_400MM |  | Non acquistare separatamente. Illustrative routed centreline 386.1 mm; supplied/cut cable nominal 400 mm. Connector bodies and service slack require sample fitting. | load_cell_4wire_cable
INCLUDED_L6D_WIRE_END | 4 | 0 | pezzi | Conduttore cella verso HX711 | Incluso nel componente | INCLUDED_L6D_WIRE_END |  | Non acquistare separatamente. Four free ends for E+/E-/A+/A-. Actual module solder/terminal location is not assumed. | load_cell_wire_end_1; load_cell_wire_end_2; load_cell_wire_end_3; load_cell_wire_end_4
PRINT_KEYPAD_CABLE_HOOD | 2 | 2 | pezzi | Ponte copricoda tastiera adesivo | Stampare su file | PA12 MJF/SLS, pezzo a disegno | https://jlc3dp.com/ | Due ponti coprono le uscite delle code; appoggi adesivi esterni alle membrane, senza pressione sulle zone dei tasti. | keypad_cable_hood_1; keypad_cable_hood_2
CUT_3M468MP_KEYPAD_HOOD_PAD | 6 | 1 | ritaglio per 6 piazzole | Adesivo copricoda 0.13 mm | Consumabile da ritagliare | 3M468MP, spessore 0,13 mm | https://www.3m.com/3M/en_US/p/dc/v100808810/ | Ritagliare due piazzole 24×2 e quattro 2×6 mm. Spessore 0,13 mm; adesione sulla finitura stampata da verificare. | keypad_hood_adhesive_1_1; keypad_hood_adhesive_1_2; keypad_hood_adhesive_1_3; keypad_hood_adhesive_2_1; keypad_hood_adhesive_2_2; keypad_hood_adhesive_2_3
INCLUDED_KEYPAD_TAIL | 2 | 0 | pezzi | Coda tastiera curva - inviluppo 88 mm con connettore | Incluso nel componente | INCLUDED_KEYPAD_TAIL |  | Non acquistare separatamente. 76mm routed flex +12mm provisional connector =88mm. Width14.28 and thickness0.3 assumed; BerryBase only publishes total length. Bend radii2/4mm require sample validation. | keypad_tail_1; keypad_tail_2
INCLUDED_KEYPAD_5P_FEMALE | 2 | 0 | pezzi | Connettore femmina 5 pin incluso nella membrana | Incluso nel componente | INCLUDED_KEYPAD_5P_FEMALE |  | Non acquistare separatamente. Pitch2.54 documented; 14.28x12x4 body and cavity details are provisional, measure selected BerryBase sample. | keypad_female_connector_1; keypad_female_connector_2
HEADER_1x5_2p54 | 2 | 1 | strip da 20 poli | Pettine maschio 1x5 adattatore tastiera | Acquistare | BerryBase PINH-1X20P | https://www.berrybase.de/en/male-connector-1x-20-pin-rm-2.54-straight | Tagliare due pettini da 5 poli da una sola strip. Verificare profondità di innesto sul campione; pin inclusi. Alternativa Cina LCSC C2977586 con minimo 5 strip. | keypad_adapter_header_body_1; keypad_adapter_header_body_2
INCLUDED_HEADER_CONTACT | 10 | 0 | pezzi | Contatto pettine tastiera | Incluso nel componente | INCLUDED_HEADER_CONTACT |  | Non acquistare separatamente. Nominal square0.64mm contact, included with1x5 header. | keypad_adapter_header_pin_1_1; keypad_adapter_header_pin_1_2; keypad_adapter_header_pin_1_3; keypad_adapter_header_pin_1_4; keypad_adapter_header_pin_1_5; keypad_adapter_header_pin_2_1; keypad_adapter_header_pin_2_2; keypad_adapter_header_pin_2_3; keypad_adapter_header_pin_2_4; keypad_adapter_header_pin_2_5
CUSTOM_KEYPAD_MATRIX_BRANCH | 2 | 1 | nastro 10 fili da 1 m | Cablaggio su misura matrice tastiera - ramo | Cablaggio da assemblare | Adafruit6182 | https://www.adafruit.com/product/6182 | Ricavare due rami da 5 fili, taglio iniziale 200 mm ciascuno. Unire le quattro righe a monte dei sei contatti; saldare e isolare i giunti, non inserire due fili nello stesso crimp non specificato. Adeguare le lunghezze al montaggio. | keypad_adapter_branch_1; keypad_adapter_branch_2
HOUSING_1x6_2p54 | 1 | 1 | pezzo | Terminazione adattatore tastiera 6 fili | Acquistare | BerryBase DUPH-1X06 | https://www.berrybase.de/en/dupont-housing-1x6-pin | Quote dei connettori da verificare sul campione. | keypad_matrix_6p_termination
CRIMP_CONTACT_2p54 | 6 | 6 | pezzi | Contatto terminazione tastiera 6 fili | Acquistare | BerryBase DUPCP-F | https://www.berrybase.de/en/dupont-crimp-contact-for-cable-awg-22-28-female | Sei contatti femmina per fili AWG22–28; verificare ritenuta nel contenitore DUPH-1X06 e crimpatura sul filo AWG26 selezionato. | keypad_matrix_terminal_contact_1; keypad_matrix_terminal_contact_2; keypad_matrix_terminal_contact_3; keypad_matrix_terminal_contact_4; keypad_matrix_terminal_contact_5; keypad_matrix_terminal_contact_6
WAVESHARE_UPS_HAT_D_KIT | 1 | 1 | pezzo | Kit USB-C UPS HAT(D), due21700, protezione e viti | Acquistare | Waveshare25507 CN | https://www.waveshare.net/shop/UPS-HAT-D.htm | Un kit; 297 solidi del relativo gruppo nel CAD. EN25567 alternativo senza batterie. Variante batteria proposta, non ancora provata con firmware. | ups_vendor_001; ups_vendor_002; ups_vendor_003; ups_vendor_004; ups_vendor_005; ups_vendor_006; ups_vendor_007; ups_vendor_008; ups_vendor_009; ups_vendor_010; ups_vendor_011; ups_vendor_012; ups_vendor_013; ups_vendor_014; ups_vendor_015; ups_vendor_016; ups_vendor_017; ups_vendor_018; ups_vendor_019; ups_vendor_020; ups_vendor_021; ups_vendor_022; ups_vendor_023; ups_vendor_024; ups_vendor_025; ups_vendor_026; ups_vendor_027; ups_vendor_028; ups_vendor_029; ups_vendor_030; ups_vendor_031; ups_vendor_032; ups_vendor_033; ups_vendor_034; ups_vendor_035; ups_vendor_036; ups_vendor_037; ups_vendor_038; ups_vendor_039; ups_vendor_040; ups_vendor_041; ups_vendor_042; ups_vendor_043; ups_vendor_044; ups_vendor_045; ups_vendor_046; ups_vendor_047; ups_vendor_048; ups_vendor_049; ups_vendor_050; ups_vendor_051; ups_vendor_052; ups_vendor_053; ups_vendor_054; ups_vendor_055; ups_vendor_056; ups_vendor_057; ups_vendor_058; ups_vendor_059; ups_vendor_060; ups_vendor_061; ups_vendor_062; ups_vendor_063; ups_vendor_064; ups_vendor_065; ups_vendor_066; ups_vendor_067; ups_vendor_068; ups_vendor_069; ups_vendor_070; ups_vendor_071; ups_vendor_072; ups_vendor_073; ups_vendor_074; ups_vendor_075; ups_vendor_076; ups_vendor_077; ups_vendor_078; ups_vendor_079; ups_vendor_080; ups_vendor_081; ups_vendor_082; ups_vendor_083; ups_vendor_084; ups_vendor_085; ups_vendor_086; ups_vendor_087; ups_vendor_088; ups_vendor_089; ups_vendor_090; ups_vendor_091; ups_vendor_092; ups_vendor_093; ups_vendor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
EXTERNAL_USB_C_PSU | 1 | 1 | pezzo | Alimentatore USB-C esterno15W spina EU | Acquistare se necessario | Raspberry Pi USB-C5,1V3A | https://www.raspberrypi.com/products/power-supply/ | Esterno alla scocca; non fa parte degli STL.
DISPLAY_ADHESIVE | 1 | 1 | pezzo | Adesivo sottile per perimetro vetrino | Consumabile | 3M467MP, ritaglio | https://www.3m.com/3M/en_US/p/dc/v000185218/ | Spessore tipico0,05-0,06mm; adesione sul materiale stampato da verificare. Ritagliare senza coprire apertura80x22. | display_window
KEY_LABEL_OVERLAY | 2 | 2 | pezzi | Etichette funzioni per tastierini blank | Stampare grafica | Strisce grafiche su misura70x20mm |  | SKIP/WIFI/SLEEP/CLEAR e ENTER/TOTAL/MODE/TARE; allineare le zone sensibili al campione. Grafica illustrativa nel viewer. | keypad_strip_1; keypad_strip_2

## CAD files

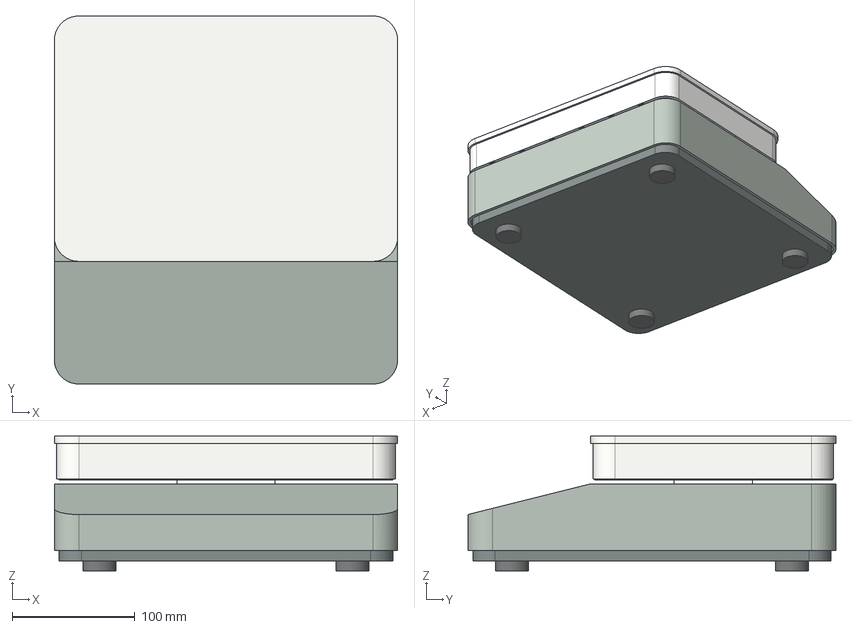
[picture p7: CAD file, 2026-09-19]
docs/mechanical/concept-01/step/MINU_concept_01_assembly_WITH_REFERENCES.step
280.0 x 300.0 x 110.0 mm
base
guscio
piatto
REFERENCE_ONLY_reserved_cell_volume
REFERENCE_ONLY_foot_1
REFERENCE_ONLY_foot_2
REFERENCE_ONLY_foot_3
REFERENCE_ONLY_foot_4

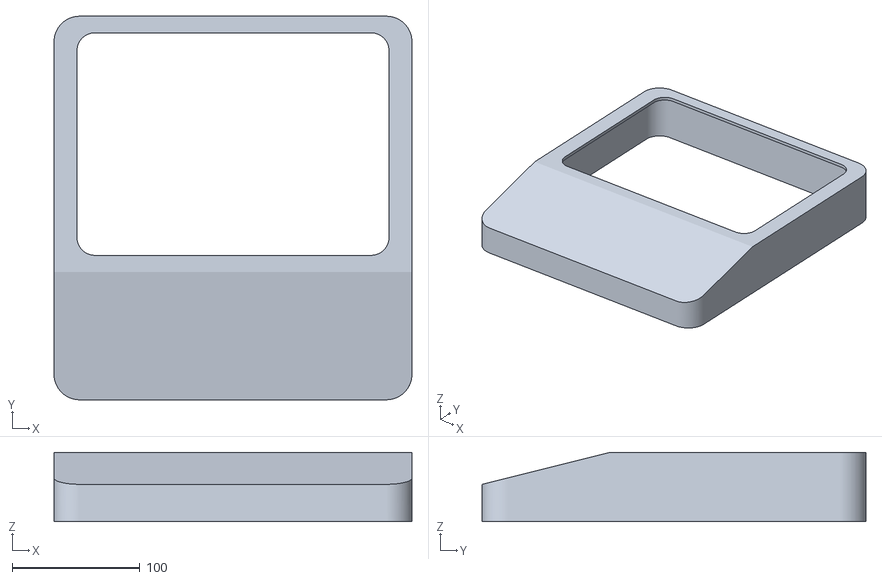
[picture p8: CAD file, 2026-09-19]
docs/mechanical/concept-01/stl-forma/guscio_FORMA_NON_MONTAGGIO.stl
280.0 x 300.0 x 54.2

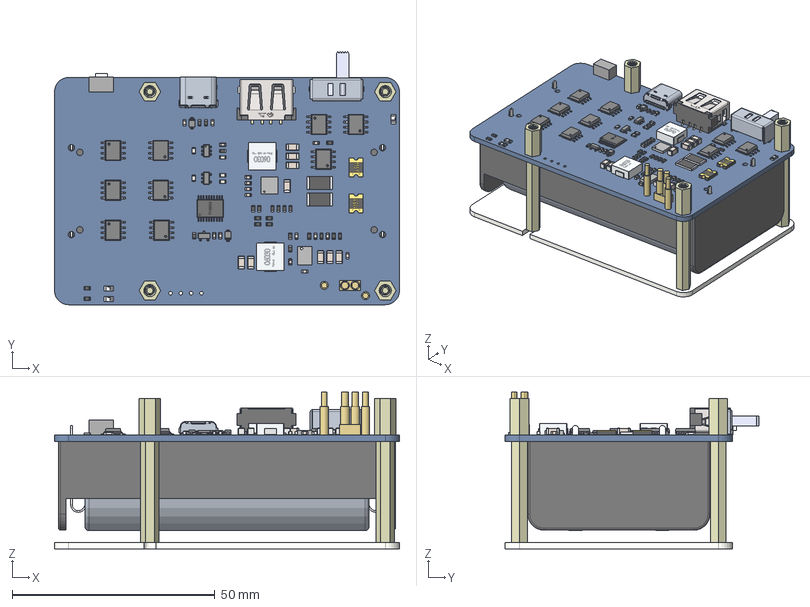
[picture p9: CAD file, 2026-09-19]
docs/mechanical/concept-02/sources/waveshare-ups-hat-d/UPS-HAT_D.stp
85.0 x 62.5 x 38.6 mm
OPEN_CASCADE_STEP_TRANSLATO-378
PIN1-3413 x 16
PIN2-5552 x 16
CERAMICBODY-7712 x 16
SOD-323-8062 x 2
SOD-323-8503 x 2
SOD-323-8944 x 2
SOD-323-9113 x 2
USER_LIBRARY-SOP-8 x 9
PIN1BODY-12932 x 23
PIN2BODY-13435 x 23
CERAMICBODY-13971 x 23
COATINGBODY-14140 x 23
SOT23-3-14350
SOT23-3-14791
SOT23-3-15232
SOT23-3-15673
TSSOP20
HOLD_21700_CON x 4
HOLD_21700-2P-34057
PIN1-44832 x 9
PIN2-46670 x 9
CERAMICBODY-48503 x 9
EXTRUDED-49086
EXTRUDED-49806
EXTRUDED-50025
EXTRUDED-50745
OPEN_CASCADE_STEP_TRANSLA-51072
OPEN_CASCADE_STEP_TRANSLA-83920
OPEN_CASCADE_STEP_TRANSLA-84361
OPEN_CASCADE_STEP_TRANSLA-84802
OPEN_CASCADE_STEP_TRANSLA-85309
OPEN_CASCADE_STEP_TRANSLA-85816
OPEN_CASCADE_STEP_TRANSLA-86727
OPEN_CASCADE_STEP_TRANSLA-87638
OPEN_CASCADE_STEP_TRANSLA-88516
OPEN_CASCADE_STEP_TRANSLA-89394
OPEN_CASCADE_STEP_TRANSLA-89868
OPEN_CASCADE_STEP_TRANSLA-90342
OPEN_CASCADE_STEP_TRANSLA-91630
OPEN_CASCADE_STEP_TRANSLA-92977
OPEN_CASCADE_STEP_TRANSLA-93888
OPEN_CASCADE_STEP_TRANSLA-95248
OPEN_CASCADE_STEP_TRANSLA-96155
OPEN_CASCADE_STEP_TRANSLA-97443
OPEN_CASCADE_STEP_TRANSLA-97950
OPEN_CASCADE_STEP_TRANSLA-98457
OPEN_CASCADE_STEP_TRANSL-100280
OPEN_CASCADE_STEP_TRANSL-102103
EXTRUDED-117798 x 4
EXTRUDED-117995 x 2
EXTRUDED-118187 x 2
EXTRUDED-118612 x 2
EXTRUDED-118809
EXTRUDED-119001
USER_LIBRARY-06030 x 2
PIN1BODY-134544 x 2
PIN2BODY-135053 x 2
CERAMICBODY-135562 x 2
COATINGBODY-135731 x 2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

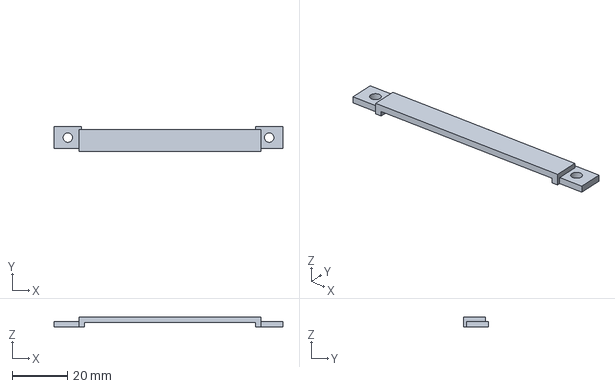
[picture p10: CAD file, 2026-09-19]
docs/mechanical/concept-02/step/power_retaining_strap_2.step
83.0 x 9.00 x 3.50 mm

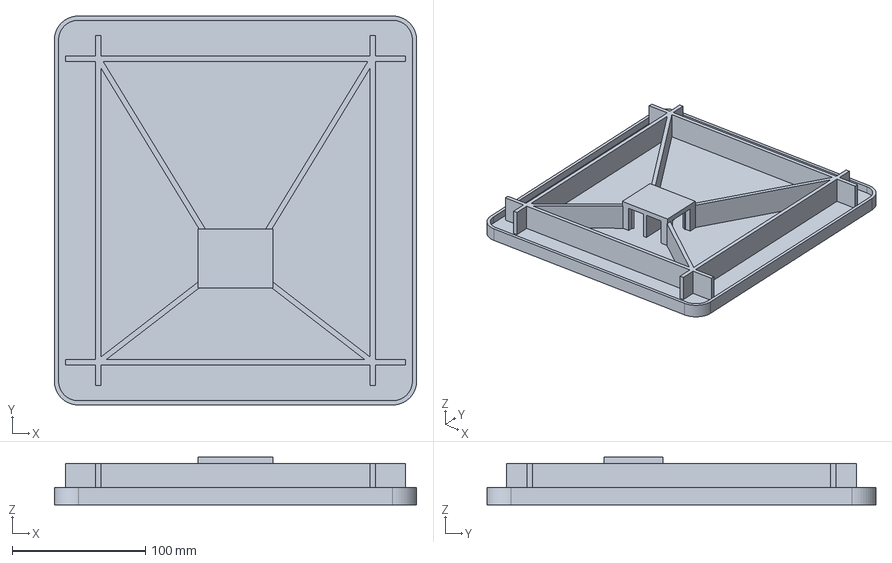
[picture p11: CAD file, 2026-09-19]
docs/mechanical/concept-01/step/base.step
272.0 x 292.0 x 36.0 mm

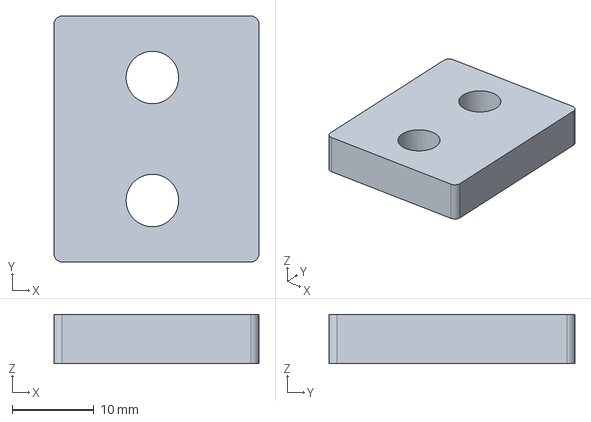
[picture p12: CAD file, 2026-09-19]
docs/mechanical/concept-02/step/cell_fixed_spacer.step
25.0 x 30.0 x 6.00 mm

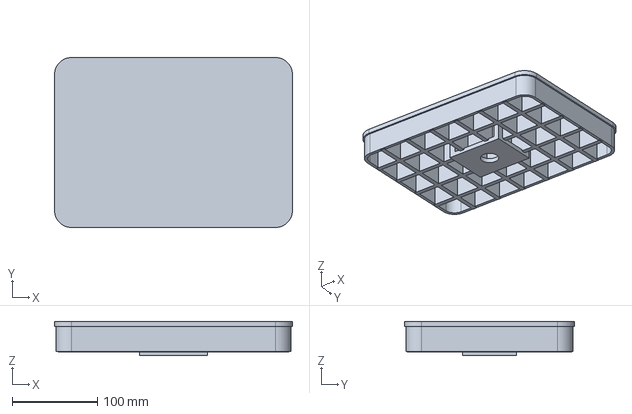
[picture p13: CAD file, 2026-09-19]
docs/mechanical/concept-01/step/piatto.step
280.0 x 200.0 x 40.0 mm

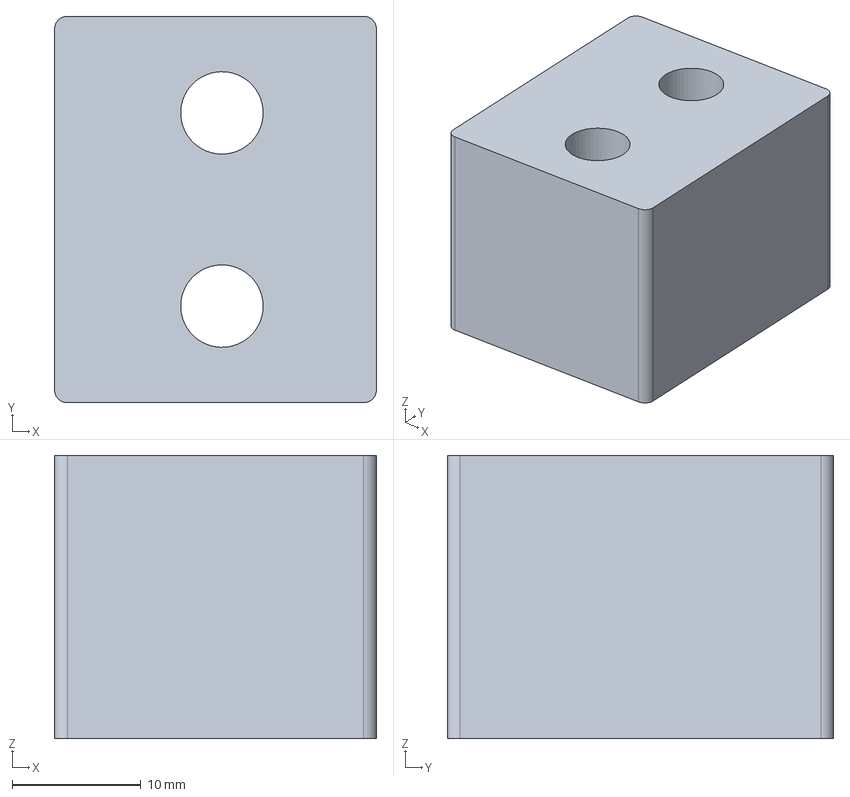
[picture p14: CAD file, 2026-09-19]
docs/mechanical/concept-02/step/cell_moving_spacer.step
25.0 x 30.0 x 22.0 mm

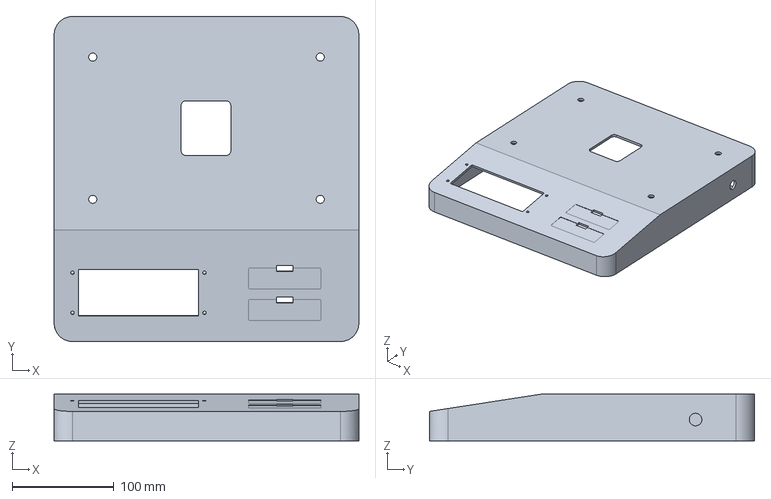
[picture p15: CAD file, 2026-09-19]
docs/mechanical/concept-02/step/outer_shell.step
300.0 x 320.0 x 46.0 mm

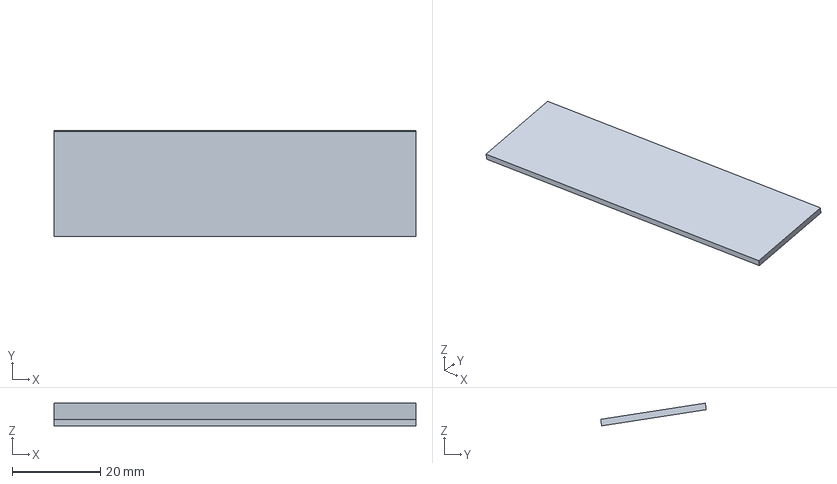
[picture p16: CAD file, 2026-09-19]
docs/mechanical/concept-02/step/display_window.step
82.0 x 23.9 x 5.15 mm

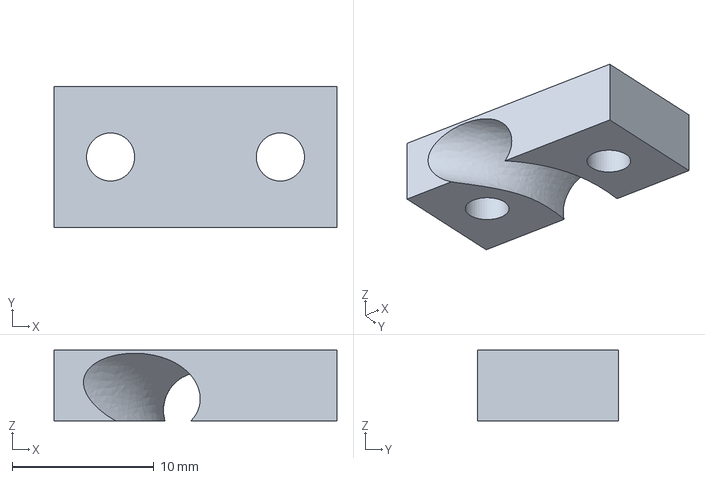
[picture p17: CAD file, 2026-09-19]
docs/mechanical/concept-02/step/cable_clamp_upper_1.step
20.0 x 10.0 x 5.00 mm

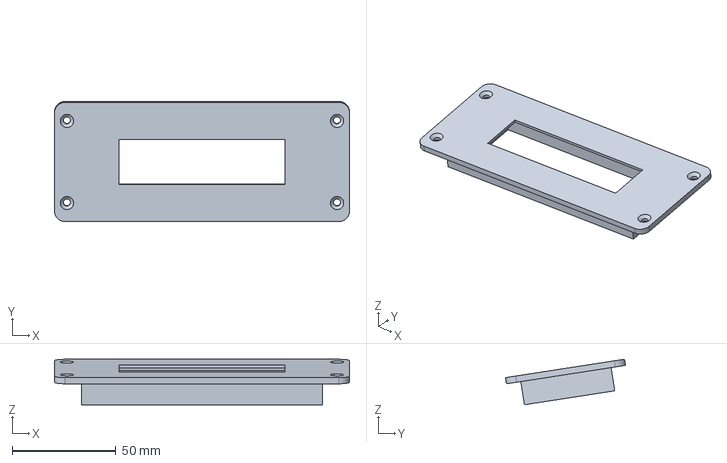
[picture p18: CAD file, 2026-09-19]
docs/mechanical/concept-02/step/display_bezel.step
142.0 x 57.8 x 21.9 mm

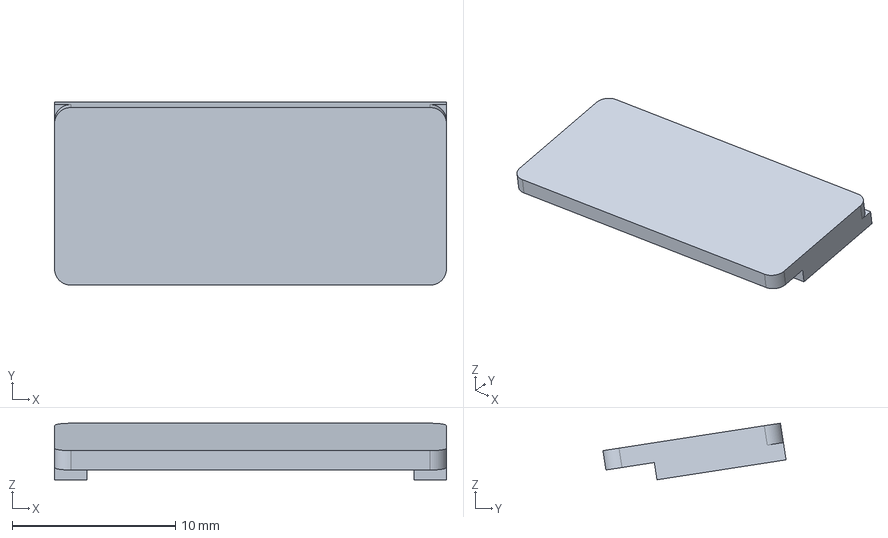
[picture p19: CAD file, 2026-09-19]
docs/mechanical/concept-02/step/keypad_cable_hood_2.step
24.0 x 11.2 x 3.47 mm

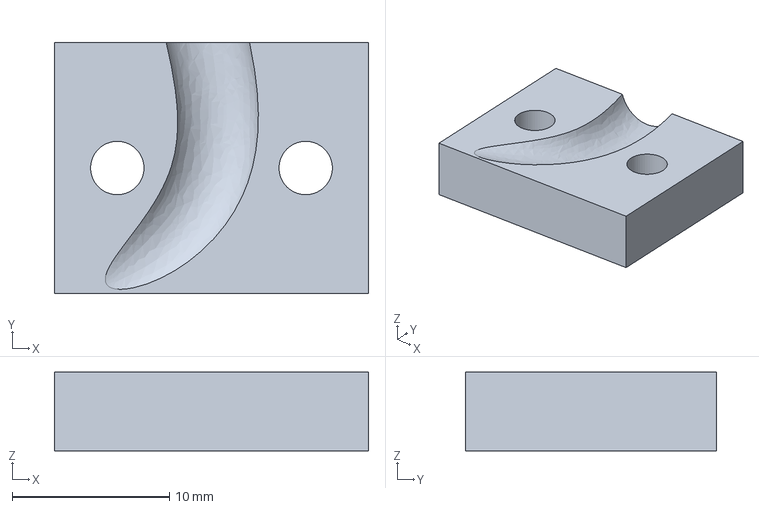
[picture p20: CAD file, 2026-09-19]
docs/mechanical/concept-02/step/cable_clamp_lower_1.step
20.0 x 16.0 x 5.00 mm

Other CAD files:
firmware_mqtt_protocol_harness.obj
docs/mechanical/concept-01/stl-forma/base_FORMA_NON_MONTAGGIO.stl
docs/mechanical/concept-01/stl-forma/piatto_FORMA_NON_MONTAGGIO.stl
docs/mechanical/concept-01/step/guscio.step
docs/mechanical/concept-02/step/base_aluminium.step
docs/mechanical/concept-02/step/cable_clamp_lower_2.step
docs/mechanical/concept-02/step/cable_clamp_upper_2.step
docs/mechanical/concept-02/step/display_rear_bar_1.step
docs/mechanical/concept-02/step/display_rear_bar_2.step
docs/mechanical/concept-02/step/electronics_tray.step
docs/mechanical/concept-02/step/keypad_cable_hood_1.step
docs/mechanical/concept-02/step/keypad_hood_adhesive_1_1.step
docs/mechanical/concept-02/step/keypad_hood_adhesive_1_2.step
docs/mechanical/concept-02/step/keypad_hood_adhesive_1_3.step
docs/mechanical/concept-02/step/keypad_hood_adhesive_2_1.step
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

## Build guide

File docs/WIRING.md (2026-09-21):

# Cablaggio hardware

Stato corrente del cablaggio usato dal firmware `firmware/esp32_hx711_serial`. Alimentazione montata: batteria USB-C NASTIMA LiFePO4 e Mini360 MP1482DS regolato a **5,11 V**, valore riferito da Andrea. Cablaggio completato e primo funzionamento apparentemente regolare riferiti il 18 settembre 2026; le tacche firmware usano fasce indicative LiFePO4 e l'icona di ricarica usa la tensione filtrata, senza modificare soglie e tempi delle protezioni.

Moduli: ESP32 DevKit, HX711 alimentato a 5 V, cella di carico a 4 fili, OLED SSD1322 SPI, INA219 I2C, tastiera 4x2, buzzer, DFPlayer Mini e LED di standby.

## 1) Cella di carico → HX711

- Rosso → **E+**
- Nero → **E-**
- Verde → **A+**
- Bianco → **A-**

Il colore dei fili può variare tra produttori: se la cella non segue questa convenzione, verificare il datasheet prima di alimentarla.

## 2) HX711 → ESP32

### Alimentazione

- HX711 **VCC → 5 V** stabile
- HX711 **GND → GND comune**

### SCK

- ESP32 **GPIO16 → resistenza 220 Ω in serie → SCK HX711**

L'HX711 accetta il livello HIGH a 3,3 V. Non usare un level shifter bidirezionale a MOSFET su SCK: i moduli per I2C/open-drain possono mantenere la linea alta e causare power-down o letture instabili.

### DOUT / DT

Il cablaggio corrente usa un partitore resistivo:

- **DOUT HX711 → 10 kΩ → GPIO35 ESP32**
- **GPIO35 ESP32 → 20 kΩ → GND**

Il partitore limita a circa 3,3 V un eventuale livello DOUT a 5 V. GPIO35 è input-only e non dispone di pull-up/pull-down interno. Con questo partitore, se DOUT o l'HX711 vengono scollegati, il pin tende a restare basso: il rilevamento del modulo scollegato non può quindi essere garantito in ogni condizione.

## 3) OLED SSD1322 SPI → ESP32

- **SCK → GPIO18**
- **MOSI → GPIO23**
- **CS → GPIO25**
- **DC → GPIO26**
- **RST → GPIO27**
- Alimentazione e livelli logici secondo le specifiche del modulo OLED usato
- **GND → GND comune**

## 4) INA219 I2C → ESP32

- **SDA → GPIO32**
- **SCL → GPIO33**
- **VCC → 3,3 V**, salvo diversa indicazione del modulo
- **GND → GND comune**

L'INA219 misura la tensione ai morsetti batteria e la corrente diretta al Mini360. **VIN+ riceve il positivo dopo F1; VIN− va a S1 e poi a IN+ del Mini360. VIN− è ancora il positivo, non GND.** SDA/SCL non trasportano la corrente del carico. La ricarica USB interna del pacco non attraversa questo shunt: il sensore non misura la corrente netta delle celle. L'icona firmware `charging` è una stima dalla tensione e non certifica la ricarica USB.

## 5) Tastiera 4x2 → ESP32

- **R1 → GPIO17**
- **R2 → GPIO5**
- **R3 → GPIO13**
- **R4 → GPIO14**
- **C1 → GPIO19**
- **C2 → GPIO21**

La matrice è gestita direttamente dal firmware; non collegare tensioni esterne alle righe o alle colonne.

## 6) Buzzer → ESP32

- Segnale buzzer → **GPIO22**
- Massa → **GND comune**

GPIO22 è riservato al buzzer e non è disponibile come alternativa per DOUT HX711 nel cablaggio corrente. Se il buzzer richiede più corrente di quella ammessa dal GPIO, pilotarlo tramite transistor.

## 7) DFPlayer Mini → ESP32

- **GPIO4 (TX ESP32) → resistenza 1 kΩ in serie → RX DFPlayer**
- **TX DFPlayer → GPIO34 (RX ESP32)**, collegamento opzionale
- **BUSY DFPlayer → GPIO39**
- **GPIO2 → circuito di power-gate**, `HIGH = ON`
- Altoparlante → **SPK1 / SPK2** del DFPlayer
- Alimentazione e condensatori secondo le specifiche del modulo
- **GND → GND comune**

GPIO34 e GPIO39 sono input-only e non hanno pull-up interno. Sul segnale BUSY è consigliata una pull-up esterna da **10–47 kΩ verso 3,3 V** se il modulo non garantisce un livello definito durante spegnimento o reset.

Il power-gate previsto dal firmware è un high-side con P-MOSFET comandato tramite NPN; non alimentare il DFPlayer direttamente da GPIO2.

## 8) LED di standby → ESP32

- **GPIO15 → resistenza 330 Ω–2,2 kΩ → anodo LED**
- Catodo LED → **GND**

Il firmware usa logica active-high: LED acceso durante standby/light sleep.

## 9) Alimentazione e masse

### Percorso montato

- **Batteria scelta:** NASTIMA **BK06-LF60-NATC**, LiFePO4 **6,4 V nominali / 6 Ah**, caricatore USB-C e BMS integrati. Il riferimento commerciale «6 V» non indica una batteria al piombo.
- **Ricarica:** alimentatore USB esterno → collegamento USB-C da scocca → ingresso USB-C del pacco, dichiarato **5 V / 1,5 A**. Il caricatore è dentro il pacco; la prolunga non è un caricatore.
- **Positivo di potenza:** batteria + → **F1 vicino alla batteria → INA219 VIN+ → VIN− → S1 → Mini360 IN+**.
- **Negativo:** batteria −, Mini360 IN− e OUT−, ESP32 e periferiche condividono GND.
- **Uscita:** Mini360 OUT+ → linea nominale 5 V, regolata sul montaggio a **5,11 V** → ESP32 **VIN/5V**, HX711, OLED compatibile e power-gate audio esistente. Non alimentare il pin 3V3 con questa linea.
- **S1:** interruttore semplice dopo VIN− dell'INA219 e prima di IN+ e dei condensatori d'ingresso. In OFF disalimenta il Mini360 dalla batteria; non interrompe la ricarica interna del pacco. Gli ingressi INA219 possono restare sul bus batteria con VCC spento, come ammesso dal [datasheet TI, §8.3.1](https://www.ti.com/lit/ds/symlink/ina219.pdf).

F1 **T2 A** resta il valore proposto nello schema per fili corti in rame ≥ 0,5 mm²; non sono stati riferiti valore effettivamente montato o misure degli spunti. CTK3S e SLA non sono componenti del percorso corrente.

### Condensatori e collocazione

| Posizione | Elettrolitico | Ceramico | Collegamento |
|---|---|---|---|
| Ingresso Mini360, dopo S1 | C1: **220 µF / 16 V** | C2: **100 nF** | Entrambi tra **IN+ e IN−** |
| Uscita Mini360 | C3: **470 µF / 10 V** | C4: **100 nF** | Entrambi tra **OUT+ e OUT−** |

Ogni coppia è in parallelo all'alimentazione. Saldare vicino ai rispettivi pad, direttamente sulla schedina se c'è spazio oppure subito accanto con collegamenti corti. Andrea ha montato il ceramico di uscita più vicino al Mini360 e poi l'elettrolitico: disposizione coerente con il cablaggio. Il + dell'elettrolitico va al + della relativa coppia; la banda − va a IN−/OUT−. I ceramici non hanno polarità. Restano previsti i condensatori locali **10–47 µF + 100 nF** presso VIN/5V e GND dell'ESP32.

### Stato delle verifiche e monitoraggio

Il montaggio risulta funzionante dalla prima prova riferita da Andrea. **5,11 V** è la regolazione comunicata, non una registrazione di stabilità su tutti i carichi. Autonomia, cadute con Wi-Fi/audio, temperatura, transitori USB e riavvio dopo stacco BMS non hanno misure riportate.

Le tacche firmware usano fasce indicative LiFePO4. L'icona `charging` si accende a tensione filtrata ≥ **6,70 V per 5 s** e si spegne a ≤ **6,68 V per 10 s**; nella banda intermedia conserva lo stato. Sono soglie indicative ricavate dalle letture riferite, non un rilevamento della presenza USB: a batteria bassa la ricarica può non raggiungerle. Avvisi sonori e protezioni di sleep restano attivi indipendentemente dalle tacche e dall'icona; campioni invalidi/scaduti non alimentano il rilevamento. Dettagli nel [README, monitoraggio batteria](../README.md#8-monitoraggio-batteria-ina219). Il light-sleep non è uno stacco elettrico del pacco.

L'USB del PC sull'ESP32 è distinta dall'USB di ricarica del pacco. OUT+ rimane collegato all'ESP32 anche con S1 OFF: se la scheda riporta la tensione USB su VIN/5V, può rialimentare il Mini360. La sola rialimentazione non dimostra un danno; questo caso non è stato caratterizzato sulla scheda specifica. Tavole, pinout del retro e dettagli: [Mini360](../artifacts/mini360/README.md).

### Masse e segnali

- Tutti i moduli che scambiano segnali devono condividere la massa con l'ESP32.
- Non applicare mai 5 V direttamente a un GPIO ESP32.
- Dimensionare buck, piste, cavi e protezioni per la corrente combinata di ESP32, OLED, HX711, INA219, buzzer e DFPlayer.
- Tenere i cavi della cella e dell'HX711 lontani dal DFPlayer, dall'altoparlante e dai percorsi di potenza per ridurre il rumore sulla misura.

## 10) Collegamenti da non usare

- Nessun level shifter MOSFET 3,3↔5 V su SCK HX711.
- Nessun collegamento diretto a 5 V su GPIO35.
- Nessun DOUT HX711 su GPIO22 senza una modifica coordinata di buzzer, firmware e documentazione.
- Nessun carico DFPlayer alimentato direttamente da GPIO2.

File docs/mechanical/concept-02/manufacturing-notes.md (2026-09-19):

# Note di lavorazione CNC - Concept 02

**Tutte le quote sono nominali, in millimetri.** Queste note completano i quattro STEP metallici: il prototipo richiede conferma delle tolleranze e delle giunzioni della cella prima dell'ordine. Materiale proposto: alluminio 6061-T6, da confermare nella richiesta di lavorazione.

## 1. Interpretazione dei file

I fori filettati sono rappresentati nello STEP come cilindri al **diametro nominale del filetto**, senza elica. Un cilindro D3 contrassegnato M3 non va fabbricato semplicemente con una punta da 3; lo stesso vale per D6/M6.

| Lavorazione richiesta | Preforo indicativo per maschiatura ad asportazione | Filetto finale |
|---|---:|---|
| M3 passante | D2,5 | M3 x 0,5 - 6H |
| M6 passante | D5,0 | M6 x 1 - 6H |
| Passaggio libero M3 | D3,4 | Nessun filetto |
| Passaggio libero M6 | D6,4 | Nessun filetto |

I prefori per maschiatura a deformazione possono essere diversi e vanno definiti dall'officina per il proprio utensile. Riferimento del produttore: [TR Fastenings - tapping sizes and clearance holes](https://www.trfastenings.com/Knowledge-Base/Engineering-Data/tapping-sizes-and-clearance-holes). **Le indicazioni di filetto in queste note prevalgono sul diametro cilindrico semplificato del modello.**

Origine delle coordinate globali: centro del basamento in pianta. X e la larghezza; Y positivo e il retro; Z e verso l'alto. Gli STEP conservano la posizione dell'assieme. Nelle tabelle locali di distanziali e carrier viene esplicitata anche l'origine del singolo pezzo.

Le superfici di appoggio cella devono essere piane, pulite e prive di bave. Non introdurre conicita o vernice sulle due superfici di serraggio. La scelta di tolleranze per planarita, parallelismo e posizione va concordata con officina e fornitore della cella; la sola precisione di stampa della scocca non definisce quella dei fissaggi metallici.

## 2. Basamento

File: `step/base_aluminium.step`. Un pezzo, **300 x 320 x 6**, angoli R18, Z13..19. Tutti i fori attraversano i 6 mm di spessore. Sono presenti **30 fori**, ripartiti come segue.

| Gruppo | Quantita | Coordinate globali XY | Lavorazione finale |
|---|---:|---|---|
| Chiusura scocca laterale | 6 | X=-142,+142; per ciascun X, Y=-118,-10,+105 | D3,4 passante |
| Chiusura scocca frontale | 2 | (-88,-152), (+88,-152) | D3,4 passante |
| Cella lato fisso | 2 | (-106;42,5), (-106;57,5) | D6,4 passante |
| Piedi regolabili | 4 | (-132,-142), (-132,+142), (+132,-142), (+132,+142) | **M6x1-6H passante**, preforo D5 |
| Fermi di sovraccarico | 4 | (-112,-20), (-112,120), (+112,-20), (+112,120) | **M6x1-6H passante**, preforo D5 |
| Vassoio potenza | 4 | (45,22), (45,88), (118,22), (118,88) | **M3x0,5-6H passante**, preforo D2,5 |
| Vassoio elettronica libero | 4 | (-107,-53), (-107,-3), (26,-53), (26,-3) | **M3x0,5-6H passante**, preforo D2,5 |
| Fermacavi | 4 | (126,-28), (138,-28), (16,18), (28,18) | **M3x0,5-6H passante**, preforo D2,5 |

I filetti dei piedi consentono di regolarne la quota; i controdadi superiori bloccano la regolazione. Non sostituire questi quattro filetti con semplici fori liberi mantenendo un solo dado superiore.

I grani arresto M6x60 attraversano tutto il filetto del basamento. La quota nominale della punta e Z67,5, che lascia 1,5 mm sotto il carrier; il lato inferiore e Z7,5. I quattro controdadi dei grani sono sopra il basamento. La scocca plastica dispone di quattro passaggi D8 allineati, che non si devono confondere con i fori filettati della base.

## 3. Carrier mobile del piatto

File: `step/plate_carrier_aluminium.step`. Un pezzo, **276 x 196 x 8**, angoli R16, centro globale XY(0,50), Z69..77. Origine locale al centro del pezzo in pianta.

| Gruppo | Quantita | Coordinate locali XY | Coordinate globali XY | Lavorazione finale |
|---|---:|---|---|---|
| Fissaggio cella mobile | 2 | (0;-7,5), (0;+7,5) | (0;42,5), (0;57,5) | D6,4 passante + svasatura superiore **90 gradi, diametro nominale D12,4** |
| Fissaggio piatto plastico | 6 | X=-113,+113; per ogni X, Y=-74,0,+74 | X=-113,+113; per ogni X, Y=-24,50,124 | **M3x0,5-6H passante**, preforo D2,5 |

Con D6,4 e D12,4 la profondita geometrica della svasatura a 90 gradi e `(12,4-6,4)/2 = 3,0 mm`; restano 5,0 mm di tratto cilindrico. La vite selezionata e **M6x45 DIN7991**, testa nominale D12 e altezza di catalogo 3,3 mm: questa altezza non definisce da sola l'angolo del cono. Verificare che la testa sia a filo o leggermente incassata e non sollevi il piatto plastico. Non sostituire il modello di vite senza confrontare testa e sede.

Il piatto plastico 280x200 sporge nominalmente 2 mm dal carrier e si avvita ai sei filetti M3. Non aggiungere rondelle sotto le teste coniche delle viti della cella.

## 4. Distanziale fisso

File: `step/cell_fixed_spacer.step`. Un pezzo, **25 x 30 x 6**, raccordi verticali R1, centro globale XY(-105,5;50), Z19..25.

| Quantita | Coordinate locali dal centro del pezzo | Coordinate globali | Lavorazione |
|---:|---|---|---|
| 2 fori | (-0,5;-7,5), (-0,5;+7,5) | (-106;42,5), (-106;57,5) | D6,4 passante, senza filetto |

L'offset locale di 0,5 mm e intenzionale: fa coincidere l'appoggio con il blocco terminale della cella e i fori con il suo disegno. Le due M6x25 si inseriscono dal basso attraverso rondella 1,6 mm, basamento 6 mm e distanziale 6 mm; il filetto della cella viene impegnato nominalmente per 11,4 mm.

## 5. Distanziale mobile

File: `step/cell_moving_spacer.step`. Un pezzo, **25 x 30 x 22**, raccordi verticali R1, centro globale XY(-0,5;50), Z47..69.

| Quantita | Coordinate locali dal centro del pezzo | Coordinate globali | Lavorazione |
|---:|---|---|---|
| 2 fori | (+0,5;-7,5), (+0,5;+7,5) | (0;42,5), (0;57,5) | D6,4 passante, senza filetto |

Le due M6x45 svasate si inseriscono dall'alto del carrier e attraversano 8+22 mm di alluminio; i 45 mm includono la testa. L'ingaggio nominale nella cella e 15 mm, senza raggiungere il lato inferiore del blocco da 22 mm.

## 6. Vincoli di montaggio da conservare

- Il basamento, la scocca e i fermi restano fissi. Carrier, piatto e distanziale mobile devono poter muoversi senza contatto con la scocca.
- I fermi non vanno precaricati contro il carrier. La quota 1,5 mm e provvisoria: regolarli sulla cella montata dopo misura di flessione e carichi eccentrici.
- Il datasheet L6D riporta filetti M6 passanti e viti 8.8 lubrificate, ma la coppia per la capacita esatta 30 kg e ambigua. Confermare con Zemic la coppia e la giunzione mobile con viti svasate 10.9.
- Confermare con Zemic l'orientamento del suo limite piattaforma 250x350 rispetto all'asse della cella. Il CAD sceglie la cella lungo X, parallelamente al lato 280 mm del piatto.

Queste note descrivono i quattro pezzi metallici del prototipo nominale. Non costituiscono una dichiarazione di portata, accuratezza o fit fisico gia collaudato.

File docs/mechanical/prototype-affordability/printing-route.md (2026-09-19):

# Un prototipo economico: stampa FDM e confronto Weerg

Stato: ricerca di fattibilità economica, verificata il 7 settembre 2026. Quantità richiesta: **un solo esemplare**. Nessun file è stato caricato presso fornitori, nessun venditore contattato e nessun preventivo del progetto ottenuto. Il CAD concept-02 resta un assieme nominale ibrido; questa nota non lo trasforma in un progetto integralmente stampabile né ne verifica la portata di 20 kg.

## Scelta pratica

La strada da approfondire è **3–5 componenti FDM in ABS o PETG, minuteria acquistabile e niente quattro lavorazioni CNC su misura**. ASA è un'alternativa se servono resistenza agli UV o specifiche termiche. Per il singolo prototipo la convenienza va confrontata sul prezzo del lotto completo, con finitura grezza e tempi non urgenti. Il PA12 industriale non è il materiale predefinito di questa proposta.

ABS è un candidato concreto, anche presso Weerg. L'aspetto della plastica delle bilance commerciali non prova però l'equivalenza fra una scocca stampata a iniezione e la stessa forma prodotta a filamento: orientamento degli strati e geometria dei collegamenti devono far parte del progetto.

## Che cosa offre Weerg

Il catalogo pubblico distingue chiaramente **stampa MJF/FDM/resina**, **lavorazione CNC dell'alluminio** e **taglio laser**. Non è stata trovata un'offerta Weerg verificabile di stampa metallica SLM/LPBF. Il riferimento dell'utente è quindi utile per ottenere componenti in alluminio online, ma non prova che siano stampati. [Catalogo stampa Weerg](https://www.weerg.com/it/stampa-3d-online), [alluminio CNC Weerg](https://www.weerg.com/it/materiali-lavorazioni-cnc/alluminio).

| Processo | Che cosa produce | Implicazione per il prototipo |
|---|---|---|
| FDM | Termoplastico depositato per strati, fra cui ABS/ASA e PETG secondo il servizio | Prima opzione da quotare per scocca, base e piatto riprogettati |
| MJF | Parti plastiche da polvere; Weerg propone, fra gli altri, PA12 e PA11 | Alternativa industriale da confrontare a preventivo, senza presumerla necessaria |
| SLS polimerico | Polvere plastica consolidata con laser | Processo diverso da FDM e da stampa dell'alluminio; non identificare automaticamente SLS e MJF |
| SLM/LPBF metallico | Metallo ottenuto da polvere mediante laser | È una tecnologia esistente per alluminio, ma non un servizio Weerg confermato da questa ricerca |
| CNC alluminio | Materiale asportato da un grezzo | Produce il pezzo disegnato su misura; non è un supporto già pronto a catalogo |

Riferimenti tecnici per la distinzione: [SLS secondo Formlabs](https://formlabs.com/blog/what-is-selective-laser-sintering/), [alluminio additivo EOS](https://www.eos.info/metal-solutions/metal-materials/aluminium), [LPBF secondo EOS](https://3d.eos.info/-eos-additive-manufacturing-v2).

**Quantità minima:** Weerg accetta un singolo pezzo sia stampato sia CNC. La FAQ descrive per CNC un caricamento STEP e una richiesta di offerta valutata da un esperto; non bisogna promettere che qualsiasi configurazione CNC riceva subito un prezzo automatico. Non è stato verificato un importo minimo generale dell'ordine: quantità minima 1 non significa minimo monetario zero. [FAQ prototipi e quantità](https://www.weerg.com/faq/order-prototypes-and-large-runs).

**Preventivo:** per la stampa servono file, materiale, finitura e data; STEP/STP/STL sono accettati fino a 150 MB. Il prezzo reale richiede l'invio della geometria. Non esiste in questa ricerca un prezzo Weerg dimostrato per la bilancia né un tariffario pubblico universale €/g applicabile al progetto. [Procedura di ordine](https://www.weerg.com/it/faq/come-si-realizza-un-ordine-su-weerg), [preventivazione stampa](https://www.weerg.com/it/stampa-3d-online).

### ABS e ASA Weerg: formato e tolleranze da risolvere

La pagina **ABS Alimentare** indica FDM, ingombro massimo **300×300×300 mm** e tolleranze **±0,60 mm sotto 100 mm; ±0,75% sopra 100 mm**. A titolo aritmetico, 0,75% di 280 mm è 2,1 mm: gli accoppiamenti nominali stretti del concept-02 non sono quindi già convalidati per questa offerta. Il nome alimentare non certifica automaticamente l'assieme finito. [Pagina ABS Weerg](https://www.weerg.com/it/materiali-stampa-3d/abs/abs-alimentare-food).

Anche la pagina **ASA** riporta 300×300×300 mm e le stesse tolleranze. La tabella tecnica generale pubblicata al percorso rev4.0 riporta invece per ABS un formato teorico 300×300×400 mm: è una discordanza delle fonti, da risolvere nel configuratore o con il servizio tecnico prima di progettare intorno al limite maggiore. [Pagina ASA](https://www.weerg.com/it/materiali-stampa-3d/abs/asa), [tabella tecnica Weerg](https://www.weerg.com/hubfs/Datasheets/Weerg%20Scheda%20Tecnica%20Materiali%20rev4.0-ITA.pdf).

Il corpo attuale 300×320 mm **non entra piatto** su un piano 300×300 mm. La possibilità di ruotarlo nello spazio non dimostra che quell'orientamento sia economico, privo di supporti o strutturalmente adatto. Per Weerg ABS occorre verificare orientamento e formato effettivo, oppure ridurre l'ingombro con un nuovo progetto; non dividere la base portante solo per aggirare il limite macchina.

## Servizi FDM per un solo esemplare

Le dimensioni dichiarate sono capacità del servizio, non approvazioni del nostro file. Materiale, colore e macchina disponibili insieme richiedono comunque verifica del preventivo.

| Servizio e fonte primaria | Evidenza quantità/materiale/formato | Prezzo pubblico e limite della verifica |
|---|---|---|
| [Weerg, Italia](https://www.weerg.com/it/stampa-3d-online) | Un pezzo; ABS e ASA FDM. Formato discordante come sopra. PETG ESD a catalogo: non equivale a PETG economico standard | Configuratore su file. Nessuna cifra del progetto verificata |
| [AManTech, Lucca](https://www.amantech.it/) | Un solo pezzo esplicitamente accettato; PETG FDM; spedizione italiana. Formato utile e disponibilità ABS/ASA non verificati | Prezzo automatico caricando STL; nessuna tariffa numerica generale verificata |
| [Eksaria, Zagabria](https://eksaria.com/) | Nessun minimo di quantità, PETG/ASA, macchina fino a 500×500×500 mm, consegne UE | Calcolatore basato su slicing; nessun prezzo senza file. Il corpo attuale rientra nell'inviluppo massimo dichiarato |
| [Imprimakers, Valencia](https://imprimakers.com/en/fdm-3d-printing/) | Nessun minimo di quantità, ABS/ASA/PETG, pezzo singolo fino a 500×500×500 mm, spedizione UE | Calcolatore online; esempio pubblico di custodia ABS da 200 g circa €50. È un esempio diverso dalla bilancia, non un prezzo proporzionale garantito |
| [LayerCrew, Romania](https://layercrew.com/pricing) | Nessun minimo di ordine; preventivatore immediato PETG/PLA, ABS/ASA su offerta | Tariffa pubblica utile come benchmark. Compatibilità macchina con corpo 300×320 mm non verificata, quindi non selezionato per il corpo senza ulteriore controllo |

## Quanto possiamo dire sui costi senza inviare file

I volumi geometrici del [concept-02](../concept-02/verification.json) danno soltanto una scala dimensionale:

| Parte attuale | Volume CAD |
|---|---:|
| Scocca esterna plastica | 404,405 cm³ |
| Copertura piatto plastica | 222,315 cm³ |
| Totale delle due plastiche principali | **626,720 cm³** |
| Base attuale in alluminio | 571,643 cm³ |
| Portapiatto attuale in alluminio | 429,918 cm³ |

Il volume del solido CAD non è la massa di filamento dello slicer: riempimenti, perimetri, supporti e orientamento cambiano il consumo. Mancano inoltre la nuova base nervata e il nuovo piatto strutturale. Sostituire semplicemente il materiale alle due piastre metalliche attuali non è una soluzione verificata.

Imprimakers pubblica inoltre un esempio **PETG da circa 100 cm³ a €19 IVA inclusa**, con riempimento standard del 20%; indica un minimo monetario d'ordine di €4,50. Questa configurazione economica non è una specifica strutturale per la bilancia: moltiplicare automaticamente €0,19/cm³ per i volumi sopra non produce un preventivo attendibile. Il prezzo di ingresso di pochi euro riguarda pezzi piccoli. [Tariffe Imprimakers 2026](https://imprimakers.com/it/prezzi-stampa-3d/).

LayerCrew pubblica un esempio PETG a €42/kg di materiale, €1/ora macchina e €50/ora operatore, esclusa IVA; il prezzo effettivo usa gli SKU correnti. Applicando soltanto quella formula a ipotesi dichiarate si ottiene: [tariffario primario](https://layercrew.com/pricing).

| Scenario ipotetico complessivo | Materiale | Macchina | Operatore | Risultato matematico, IVA esclusa |
|---|---:|---:|---:|---:|
| 1 kg, 25 h stampa, 30 min interventi | €42 | €25 | €25 | €92 |
| 2 kg, 50 h stampa, 60 min interventi | €84 | €50 | €50 | €184 |

**Questi due scenari non sono una stima validata della bilancia, né un preventivo o una fascia promessa.** Masse e tempi sono assunti; non derivano da slicing. Non includono spedizione, minuteria, elettronica, revisione del progetto o rilavorazioni. Servono a capire perché ridurre pezzi separati, supporti e interventi manuali incide sul costo. Non trasferire questo tariffario PETG a Weerg o all'ABS.

## Ridurre la complessità a 3–5 stampati

Architettura da progettare, non geometria già pronta:

1. **Base portante monopezzo:** superficie interna piana; nervature profonde solo sotto, raccordi ai nodi e attacchi piedi integrati. Sedi di dadi commerciali e bulloni passanti distribuiscono il serraggio. La rigidezza viene dall'altezza delle nervature e dal percorso del carico, non dal riempimento generico.
2. **Guscio rimovibile:** integrare fascia comandi, sede display e coperture dei passacavi; evitare tanti piccoli pezzi estetici e clip singole. Preservare accesso al montaggio e allo smontaggio.
3. **Piatto mobile plastico:** riprogettare il fondo nervato e l'attacco alla cella. Una semplice copertura attuale da 4 mm, privata del carrier metallico, non è un piatto portante da 20 kg.
4. **Una traversina/removibile fermaschede e batteria**, solo se necessaria: base interna liscia e componenti esistenti di dimensioni variabili richiedono comunque un ritegno positivo, non solo appoggio.
5. **Un adattatore della cella**, se indispensabile. Preferire distanziali/boccole e minuteria standard realmente quotati; un generico profilo acquistabile non garantisce automaticamente gli appoggi corretti della cella.

Con questa architettura si eliminano le quattro parti CNC su misura soltanto dopo aver ridisegnato il percorso strutturale. Piedi, viti, rondelle larghe, dadi e boccole commerciali restano compatibili con la richiesta di una scocca interamente stampata. I fermi di sovraccarico restano distanti dal piatto durante la misura.

## ABS, PETG o ASA e rischi da verificare

PETG è un riferimento economico per un prototipo da interno: buona adesione fra strati e basso ritiro facilitano le parti grandi. Il maggiore numero di perimetri può essere più utile del solo aumento di infill, ma nessuna percentuale dimostra la portata. [Guida PETG del produttore Prusa](https://help.prusa3d.com/article/petg_2059).

ABS è sensato se il servizio dispone di un processo controllato per scocche grandi e lo quota convenientemente. ASA aggiunge resistenza agli UV; resta soggetto a ritiro e deformazioni durante la stampa, soprattutto su grandi superfici, e richiede condizioni termiche controllate. [Guida ASA Prusa](https://help.prusa3d.com/article/asa_1809), [ABS FDM Weerg](https://www.weerg.com/it/materiali-stampa-3d/abs/abs-alimentare-food).

Per la nuova struttura restano da verificare, con geometria e materiale specifici:

- **Flessione:** carico centrale ed eccentrico da 20 kg sul vero piatto, con deformazione rispetto alla scocca e ai fermi; non basta che il pezzo non si rompa.
- **Serraggio e durata:** schiacciamento locale, separazione degli strati e deformazione lenta sotto precarico o peso sostenuto possono cambiare l'allineamento della cella. Prevedere bulloni passanti e appoggi ampi, senza imporre strutture metalliche su misura.
- **Metrologia:** ritorno a zero, isteresi e sensibilità al punto di applicazione dopo carico e scarico. Una prova di resistenza meccanica non dimostra precisione di 1 g.
- **Stabilità:** mantenere l'impronta dei piedi estesa e verificare il baricentro dell'assieme leggero finale; i margini del concept-02 che includono piastre metalliche non si trasferiscono automaticamente alla variante tutta plastica.
- **Planarità e assemblaggio:** base e piatto grandi, tolleranze del fornitore, accessibilità viti e gioco della parte mobile. I controlli CAD nominali già eseguiti non misurano le distorsioni di stampa.

Il passo utile successivo è scegliere un formato compatibile con ABS Weerg oppure con un servizio FDM da 500 mm, ridurre le parti nel CAD e ottenere un prezzo reale dei soli stampati QTY1. La portata richiesta rimane 20 kg; non è ancora una prestazione fisicamente verificata.

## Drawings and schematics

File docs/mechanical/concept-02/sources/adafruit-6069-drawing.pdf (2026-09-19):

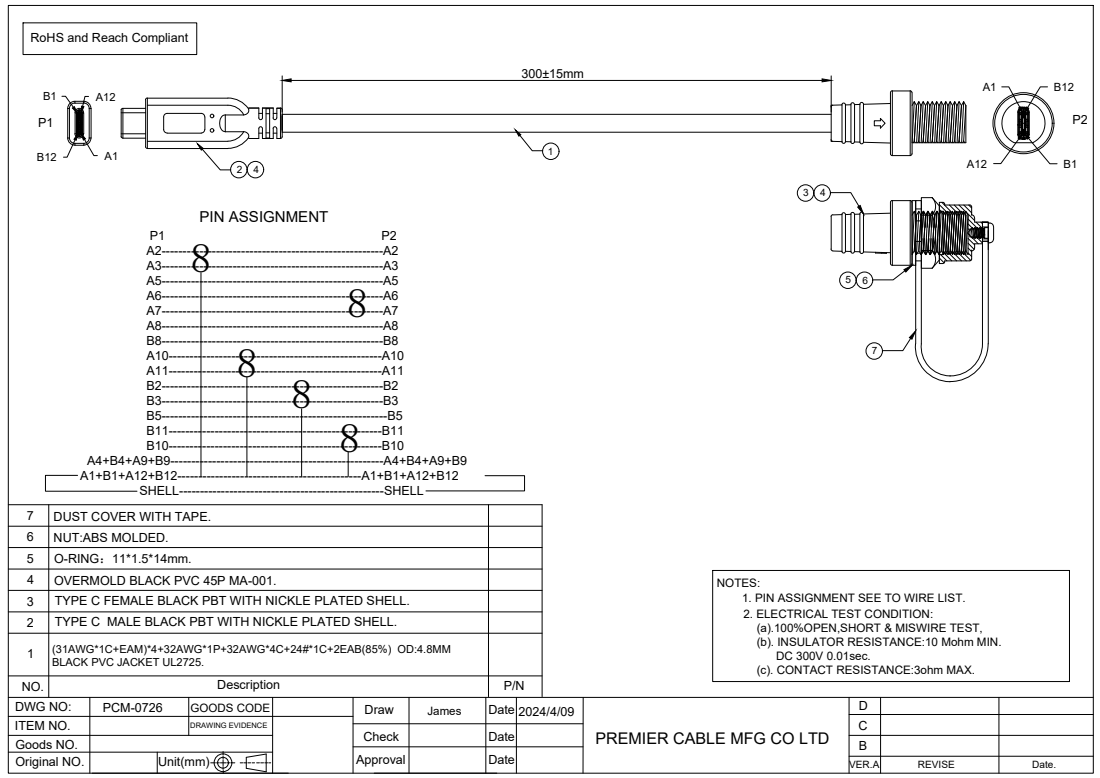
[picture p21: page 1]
Description; P/N Draw; 2024/4/09 Approval Check; Date; DBCVER.A; REVISE; Date. 2; GOODS CODE DRAWING EVIDENCE PCM-0726Unit(mm); PREMIER CABLE MFG CO LTD 3; James; Date Date 1 DWG NO: ITEM NO. Goods NO. Original NO. NO.; 1. PIN ASSIGNMENT SEE TO WIRE LIST. 2. ELECTRICAL TEST CONDITION: (a).100%OPEN,SHORT & MISWIRE TEST, (b). INSULATOR RESISTANCE:10 Mohm MIN. DC 300V 0.01sec. (c). CONTACT RESISTANCE:3ohm MAX. NOTES: TYPE C MALE BLACK PBT WITH NICKLE PLATED SHELL. 4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

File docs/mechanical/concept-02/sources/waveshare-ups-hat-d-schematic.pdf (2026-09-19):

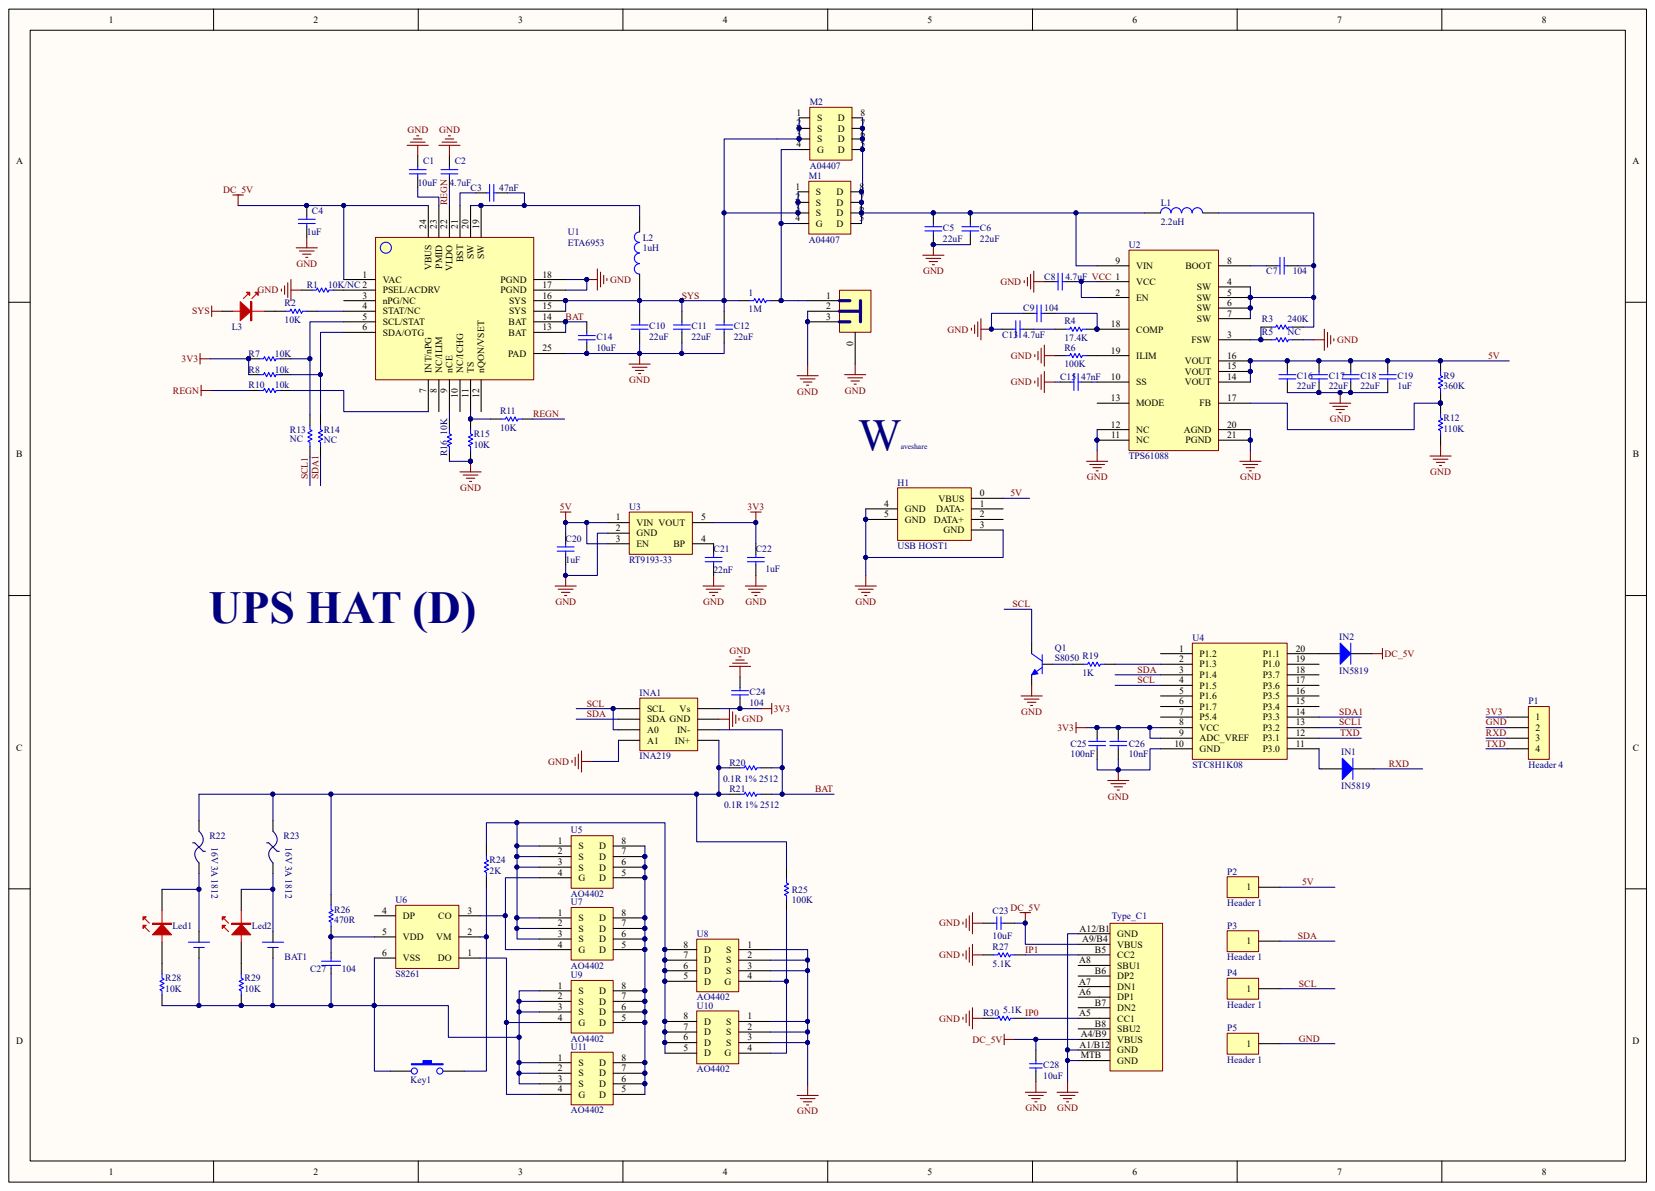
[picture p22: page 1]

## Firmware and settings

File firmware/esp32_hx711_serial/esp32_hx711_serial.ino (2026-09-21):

// =============================================================================
// ESP32 + HX711 + OLED SSD1322 + INA219 — Minù Bench Scale (Modular Refactor)
// =============================================================================
// Architettura modulare:
//   - config/config_pins.h   : Pin hardware
//   - config/config_audio.h  : Configurazione DFPlayer
//   - config/config_scale.h  : Parametri bilancia
//   - audio.h/cpp            : Modulo Audio (namespace Audio::)
//   - scale_filters.h/cpp    : Filtri (namespace ScaleFilters::)
//   - scale_state.h/cpp      : Stati (namespace ScaleState::)
// =============================================================================

#include <Arduino.h>
#include <Wire.h>
#include <Preferences.h>
#include <esp_sleep.h>
#include <esp_system.h>
#include <esp_task_wdt.h>
#include <driver/gpio.h>
#include <math.h>

// ========================= CONFIGURAZIONE =========================
#include "config/config_pins.h"
#include "config/config_audio.h"
#include "config/config_scale.h"
#include "config/config_battery.h"

// ========================= MODULI =========================
#include "audio.h"
#include "scale_filters.h"
#include "scale_state.h"

// ========================= DRIVER =========================
#include "hx711_driver.h"
#include "hx_health.h"
#include "battery_monitor.h"
#include "ui_display.h"
#include "keypad.h"
#include "buzzer.h"
#include "net_ota_cloud.h"
#include "wifi_store.h"
#include "ota_store.h"
#include "calibration_wizard.h"
#include "weigh_stack.h"

// ========================= ALIAS =========================
using namespace ScaleConfig;
using namespace AudioConfig;
using namespace BatteryConfig;

// ========================= VARIABILI GLOBALI =========================
// Necessaria per ui_display.cpp
bool stEnable = ST_ENABLE_DEFAULT;

// HX health
static HxHealth g_hxHealth;
static const HxHealthConfig HX_HEALTH_CFG = {
  .warnAfterMs       = HX_HEALTH_WARN_MS,
  .errorAfterMs      = HX_HEALTH_ERROR_MS,
  .hardAfterMs       = HX_HEALTH_HARD_MS,
  .okStableMs        = HX_HEALTH_OK_STABLE_MS,
  .lastValidMaxAgeMs = HX_HEALTH_LAST_VALID_MS
};

static bool g_hxBeginOk = false;
static bool g_isBooting = true;

// Ultimo valore raw filtrato (per calibrazione via seriale)
static long g_lastRawFiltered = 0;

// Timing
static uint32_t lastOledMs     = 0;
static uint32_t lastSampleMs   = 0;
static uint32_t g_lastKeyPressMs = 0;
static uint32_t g_lastZTtickMs = 0;

// Decimazione
static long     gWorkSum = 0;
static uint8_t  gWorkCnt = 0;
static long     gLiveSum = 0;
static uint8_t  gLiveCnt = 0;

// EMA Live
static float    gLiveEma        = 0.0f;
static bool     gLiveEmaInit    = false;
static bool     gLiveEmaPrevStEnable = true;

// Peso corrente
static float gLive = 0.0f;
static bool  g_overloadActive = false;

// Inattività
enum InactivityStage : uint8_t { INACT_NONE = 0, INACT_ZZZ = 1 };
static InactivityStage g_inactivitySleepStage = INACT_NONE;
static uint32_t g_inactivityStageStartMs = 0;
static bool     g_inactivitySleepArmed = true;
static bool     g_manualSleepRequested = false;

// WiFi
#if ENABLE_WIFI_OTA
static bool g_wifiUserEnabled = true;
static bool g_wifiSetupDone   = false;
static bool g_wifiPrevConnected = false;
static uint32_t g_wifiErrLastMs = 0;
static uint32_t g_wifiAudioSuppressUntilMs = 0;
static bool g_wifiSuppressNextConnectAnnounce = false;
static const uint32_t WIFI_ERR_COOLDOWN_MS = 60000;
#endif

// ========================= WEIGH STACK: LONG PRESS & OVERLAY =========================
static const uint32_t LONG_PRESS_MS = 2000;  // 2 seconds for long press

// CLEAR key long press tracking
static uint32_t g_clearPressStartMs   = 0;
static bool     g_clearLongPressFired = false;

// SLEEP key: short release starts standby; 2s toggles DFPlayer power.
static uint32_t g_sleepPressStartMs   = 0;
static bool     g_sleepLongPressFired = false;

// Overlay state (temporary display for TOTAL/NET/CLEAR feedback)
enum OverlayType : uint8_t {
  OVERLAY_NONE = 0,
  OVERLAY_STACK_COMPARE,
  OVERLAY_CLEAR_FEEDBACK,
  OVERLAY_AUDIO_STATUS,
  OVERLAY_BATTERY
};
static OverlayType g_overlayType      = OVERLAY_NONE;
static uint32_t    g_overlayStartMs   = 0;
static const uint32_t OVERLAY_TIMEOUT_MS = 10000; // 10 seconds auto-dismiss

// Cached overlay values (captured at overlay start)
static long g_overlayTotal    = 0;
static long g_overlayNet      = 0;
static int  g_overlayCount    = 0;
static char g_overlayMsg[12]  = {0};
static bool g_overlayAudioEnabled = true;

// ENTER: bounded, non-blocking acquisition when the normal STABLE gate is not
// ready. Result screens have their own readable, auto-dismiss timing.
enum EnterUiState : uint8_t {
  ENTER_UI_IDLE = 0,
  ENTER_UI_ACQUIRING,
  ENTER_UI_SUCCESS,
  ENTER_UI_FAILED_MOVING,
  ENTER_UI_FAILED
};
static EnterUiState g_enterUiState = ENTER_UI_IDLE;
static uint32_t g_enterUiStartMs = 0;
static long g_enterSamples[ENTER_CAPTURE_SAMPLE_BUF_N];
static uint32_t g_enterSampleMs[ENTER_CAPTURE_SAMPLE_BUF_N];
static uint8_t g_enterSampleHead = 0;
static uint8_t g_enterSampleCount = 0;
static uint8_t g_enterRawDecimationPhase = 0;
static long g_enterStartOffsetRaw = 0;
static long g_enterStartZtCounts = 0;
static float g_enterStartCpg = 0.0f;
#if ENABLE_MQTT
static bool g_enterStartHadMqttCommand = false;
static bool g_enterStartLocalFallback = false;
static char g_enterStartMqttUuid[37] = {0};
static char g_enterStartMqttSessionId[65] = {0};
static char g_enterStartMqttConnectionId[65] = {0};
static char g_enterStartMqttCommandId[65] = {0};
static uint32_t g_enterStartMqttProductId = 0;
static bool g_remoteConfirmActive = false;
#endif

// Manual TARE reference capture: save ref offset only after tare is applied
static bool g_captureReferenceAfterTare = false;
static bool g_clearStackAfterTare = false;
static bool g_manualTareArmed = false;
static uint32_t g_manualTareArmMs = 0;
static uint32_t g_tareKeyLockUntilMs = 0;
static bool g_skipShortPending = false;
static bool g_skipBlockedUntilRelease = false;
static bool g_remoteUndoAwaitingAck = false;
static char g_remoteUndoConfirmId[WeighStack::RESPONSE_ID_CAP] = {0};
static KeyCode g_deferredLocalKey = KEY_NONE;
static bool g_detachedUndoKeyGuard = false;
static bool g_syncIncidentNeedsTare = false;

static void showStackCompareOverlay(uint32_t nowMs) {
  float stackTotal = WeighStack::total();
  long totalDisp = (stackTotal >= 0.0f) ? (long)(stackTotal + 0.5f) : (long)(stackTotal - 0.5f);

  long netDisp = 0;
  if (WeighStack::hasReference()) {
    long refOffset = WeighStack::getReferenceOffset();
    float cpg = ScaleState::getScaleCpg();
    long rawNow = ScaleState::getLastRawAvg();
    float netG = (cpg > 0.01f) ? ((float)(rawNow - refOffset) / cpg) : 0.0f;
    netDisp = (netG >= 0.0f) ? (long)(netG + 0.5f) : (long)(netG - 0.5f);
  } else {
    netDisp = (long)(stEnable ? ScaleState::getDispWorkLast() : ScaleState::getDispLiveLast());
    Serial.println(F("[STACK] No reference yet, NET fallback to current display"));
  }

  g_overlayType = OVERLAY_STACK_COMPARE;
  g_overlayStartMs = nowMs;
  g_overlayTotal = totalDisp;
  g_overlayNet = netDisp;
  g_overlayCount = WeighStack::count();

  // Render subito per feedback immediato anche se la UI TARE e' attiva
  ui_renderStackCompare(g_overlayTotal, g_overlayNet, g_overlayCount);
  lastOledMs = nowMs;

  Serial.print(F("[STACK] TOT=")); Serial.print(totalDisp);
  Serial.print(F("g NET=")); Serial.print(netDisp);
  Serial.print(F("g DELTA=")); Serial.print(netDisp - totalDisp);
  Serial.println(F("g"));
}

static bool restoreTopStackEntryAfterUndo(uint32_t nowMs) {
  const WeighStack::Entry* top = WeighStack::peek();
  if (!top) return false;
  WeighStack::Entry entry = *top;

  ScaleState::setOffsetRaw(entry.oldOffset);
  ScaleState::setZtCounts(entry.oldZt);
  ScaleState::resetFiltersAndState();
  ScaleState::setTareUiActive(false);
  gLiveEma = 0.0f;
  gLiveEmaInit = false;
  gLiveEmaPrevStEnable = stEnable;
  if (!WeighStack::pop()) return false;

  g_overlayType = OVERLAY_CLEAR_FEEDBACK;
  g_overlayStartMs = nowMs;
  strlcpy(g_overlayMsg, "POP", sizeof(g_overlayMsg));
  g_overlayCount = WeighStack::count();
  g_tareKeyLockUntilMs = nowMs + TARE_OK_HOLD_MS;
  g_lastKeyPressMs = nowMs;
  lastOledMs = 0;

  Serial.print(F("[STACK] UNDO: "));
  Serial.print(entry.grams, 0);
  Serial.print(F("g (remaining="));
  Serial.print(g_overlayCount);
  Serial.println(F(")"));
  return true;
}

#if ENABLE_MQTT
static bool applyDetachedUndoNow() {
  if (!Net::mqttPopDetachedUndo()) return false;
  const WeighStack::Entry* top = WeighStack::peek();
  bool matchingEntry = g_remoteUndoAwaitingAck && top &&
    strcmp(top->confirmResponseId, g_remoteUndoConfirmId) == 0;
  bool restored = matchingEntry && restoreTopStackEntryAfterUndo(millis());
  Net::mqttReportDetachedUndoApplied(restored);
  g_remoteUndoAwaitingAck = false;
  g_remoteUndoConfirmId[0] = '\0';
  g_detachedUndoKeyGuard = restored;
  Serial.println(restored
    ? F("[STACK] UNDO locale applicato; sync continua in background")
    : F("[STACK] UNDO detached senza entry locale"));
  return true;
}

static void enterSyncIncidentTareGate(
    const __FlashStringHelper* logMessage) {
  WeighStack::clear();
  WeighStack::clearReference();
  g_remoteUndoAwaitingAck = false;
  g_remoteUndoConfirmId[0] = '\0';
  g_detachedUndoKeyGuard = false;
  g_deferredLocalKey = KEY_NONE;
  g_syncIncidentNeedsTare = true;
  Net::mqttSetTareRequired(true);
  CalWizard::cancelLongPress();
  if (CalWizard::isActive()) CalWizard::abort();
  g_skipShortPending = false;
  g_skipBlockedUntilRelease = keypad_is_pressed(KEY_SKIP);
  g_clearPressStartMs = 0;
  g_clearLongPressFired = false;
  g_overlayType = OVERLAY_NONE;
  lastOledMs = 0;
  Serial.println(logMessage);
  buzzerError();
  delay(120);
  buzzerError();
}
#endif

// Log HX
static bool     g_hxLogEnabled  = false;
static uint32_t g_hxLogPeriodMs = 250;
static uint32_t g_hxLogLastMs   = 0;

// Debug batteria
static uint32_t lastBattDebug = 0;

// ========================= HELPER SLEEP LED =========================
static inline void sleepLedOn()  { digitalWrite(SLEEP_LED_PIN, SLEEP_LED_ACTIVE_HIGH ? HIGH : LOW); }
static inline void sleepLedOff() { digitalWrite(SLEEP_LED_PIN, SLEEP_LED_ACTIVE_HIGH ? LOW : HIGH); }

// ========================= FORWARD DECLARATIONS =========================
void printHelp();
void serial_task();
void parseCommand(const char* cmd);
void handleKeyEvent(KeyCode key);
static bool isEnterSignalReady();
static bool enterPreflight(float currentWeight, long workingOffset, uint32_t nowMs, bool audible);
static bool commitEnterWeight(float currentWeight, long workingOffset, uint32_t commitNow);
static void startEnterCapture(uint32_t nowMs);
static void enterCaptureNoteRaw(long rawUse, uint32_t nowMs);
static void updateEnterCapture(uint32_t nowMs, bool haveNewWork);
static void updateEnterUiTimeout(uint32_t nowMs);
bool autoTareOnBoot(uint16_t maxSamples);
bool initHX711();
long readRawHXOnceBlocking(uint32_t timeoutMs);
static bool wasWatchdogReset();
static void setupLoopWatchdog();
static void feedLoopWatchdog();
static void enterInactivityLightSleep();
static bool maybeEnterSafeShutdown(uint32_t nowMs);

#if ENABLE_WIFI_OTA
static bool loadWifiUserEnabledFromNVS();
static void saveWifiUserEnabledToNVS(bool en);
static void wifiAudioUpdate(uint32_t now);
#endif

static bool wasWatchdogReset() {
  esp_reset_reason_t reason = esp_reset_reason();
  return reason == ESP_RST_WDT ||
         reason == ESP_RST_TASK_WDT ||
         reason == ESP_RST_INT_WDT;
}

// ========================= WATCHDOG =========================
static bool g_loopWdtActive = false;

static void setupLoopWatchdog() {
  esp_task_wdt_config_t wdtCfg = {
    .timeout_ms = LOOP_WDT_TIMEOUT_MS,
    .idle_core_mask = 0,
    .trigger_panic = true
  };

  esp_err_t initErr = esp_task_wdt_init(&wdtCfg);
  if (initErr == ESP_ERR_INVALID_STATE) {
    initErr = esp_task_wdt_reconfigure(&wdtCfg);
  }

  esp_err_t addErr = esp_task_wdt_add(NULL);
  esp_err_t statusErr = esp_task_wdt_status(NULL);
  g_loopWdtActive = (statusErr == ESP_OK);

  if (g_loopWdtActive) {
    feedLoopWatchdog();
    Serial.println(F("[WDT] OK"));
  } else {
    Serial.print(F("[WDT] FAIL i="));
    Serial.print((int)initErr);
    Serial.print(F(" a="));
    Serial.print((int)addErr);
    Serial.print(F(" s="));
    Serial.println((int)statusErr);
  }
}

static void feedLoopWatchdog() {
  if (g_loopWdtActive) {
    (void)esp_task_wdt_reset();
  }
}

// ========================= PRINT HELP =========================
void printHelp() {
  Serial.println(F("\n--- COMANDI SERIALI ---"));
  Serial.println(F("hxlog on/off, hxlog rate <ms>"));
  Serial.println(F("mp3 <track> [sec], mp3 status/reset/history, stop, vol <0-30>"));
  Serial.println(F("wifi set <slot> \"SSID\" \"PASS\", wifi creds, wifi apply"));
  Serial.println(F("ota status, ota set \"PASS\", ota clear"));
  Serial.println(F("mqtt set \"host\" \"user\" \"pass\", mqtt creds, mqtt clear, mqtt apply, mqtt status"));
  Serial.println(F("cal status, cal zero, cal ref <g>, cal save, cal load"));
  Serial.println(F("stack [status], stack list, stack clear"));
  Serial.println(F("-----------------------\n"));
}

// ========================= SERIAL TASK =========================
static char g_cmdBuf[128];
static uint8_t g_cmdLen = 0;

void serial_task() {
  while (Serial.available()) {
    char c = Serial.read();
    if (c == '\n' || c == '\r') {
      if (g_cmdLen > 0) {
        g_cmdBuf[g_cmdLen] = '\0';
        parseCommand(g_cmdBuf);
        g_cmdLen = 0;
      }
    } else if (g_cmdLen < sizeof(g_cmdBuf) - 1) {
      g_cmdBuf[g_cmdLen++] = c;
    }
  }
}

void parseCommand(const char* cmd) {
  if (g_syncIncidentNeedsTare) {
    bool stackMutation = strcmp(cmd, "stack clear") == 0;
    bool calMutation = strncmp(cmd, "cal ", 4) == 0 &&
      strcmp(cmd + 4, "status") != 0;
    if (stackMutation || calMutation) {
      Serial.println(F("[CMD] Bloccato: verifica peso/TARA richiesta"));
      return;
    }
  }
  if (g_enterUiState != ENTER_UI_IDLE) {
    bool stackMutation = strcmp(cmd, "stack clear") == 0;
    bool calMutation = strncmp(cmd, "cal ", 4) == 0 && strcmp(cmd + 4, "status") != 0;
    if (stackMutation || calMutation) {
      Serial.println(F("[CMD] Bloccato: acquisizione ENTER"));
      return;
    }
  }
#if ENABLE_MQTT
  if (Net::isMqttResponsePending()) {
    bool stackMutation = strcmp(cmd, "stack clear") == 0;
    bool calMutation = strncmp(cmd, "cal ", 4) == 0 && strcmp(cmd + 4, "status") != 0;
    if (stackMutation || calMutation) {
      Serial.println(F("[CMD] Bloccato: response ACK pending"));
      return;
    }
  }
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
void loop() {
  // Reset Task Watchdog (evita reboot se loop è vivo)
  feedLoopWatchdog();

  // Defer MQTT callbacks and related UI feedback during the bounded manual-
  // tare critical section. Connection establishment runs on a separate task.
  uint32_t loopStartMs = millis();
  if (g_manualTareArmed &&
      (uint32_t)(loopStartMs - g_manualTareArmMs) >= TARE_MANUAL_ARM_MAX_MS) {
    g_manualTareArmed = false;
    g_manualTareArmMs = 0;
    g_captureReferenceAfterTare = false;
    g_clearStackAfterTare = false;
    Serial.println(F("[TARE] Annullata (tasto trattenuto)"));
  }
  bool tareCritical = g_manualTareArmed || ScaleState::isTareActive();

#if ENABLE_WIFI_OTA
  if (!tareCritical) Net::update();
  wifiAudioUpdate(millis());
#endif

#if ENABLE_MQTT
  if (!tareCritical && Net::mqttPopActivity()) {
    uint32_t activityNow = millis();
    g_lastKeyPressMs = activityNow;
    if (g_inactivitySleepStage != INACT_NONE && !g_manualSleepRequested) {
      g_inactivitySleepStage = INACT_NONE;
      g_inactivityStageStartMs = 0;
      g_manualSleepRequested = false;
      Audio::stopNow(true);
      lastOledMs = 0;
    }
  }

  if (!tareCritical && g_enterUiState == ENTER_UI_IDLE) {
    char rejectedConfirmId[WeighStack::RESPONSE_ID_CAP] = {0};
    bool confirmRollbackSafe = false;
    if (Net::mqttPopConfirmReject(
          rejectedConfirmId, sizeof(rejectedConfirmId),
          &confirmRollbackSafe)) {
      const WeighStack::Entry* top = WeighStack::peek();
      bool exactNewestCommit = confirmRollbackSafe && top &&
        rejectedConfirmId[0] != '\0' &&
        strcmp(top->confirmResponseId, rejectedConfirmId) == 0;
      bool rolledBack = exactNewestCommit &&
        restoreTopStackEntryAfterUndo(millis());
      if (rolledBack) {
        Net::mqttSetTareRequired(false);
        Serial.println(F("[STACK] CONFIRM quarantine: exact commit rolled back"));
        buzzerWarn();
      } else {
        // The Manager did not commit this weighing and local work may already
        // have advanced. Never manufacture an ACK/undo for the missing receipt.
        enterSyncIncidentTareGate(
          F("[STACK] CONFIRM quarantine: history invalid, TARE required"));
      }
    }
    if (Net::mqttPopDetachedUndoReject()) {
      // The detached undo has already changed the offset and the operator may
      // have continued locally. A late Manager quarantine cannot be safely
      // compensated without risking newer work: invalidate history and force
      // an explicit physical tare check.
      enterSyncIncidentTareGate(
        F("[STACK] UNDO quarantine after detach: history invalid, TARE required"));
    }
    if (Net::mqttPopUndoReject()) {
      g_remoteUndoAwaitingAck = false;
      g_remoteUndoConfirmId[0] = '\0';
      g_detachedUndoKeyGuard = false;
      Serial.println(F("[STACK] UNDO quarantined; local stack unchanged"));
      buzzerWarn();
    }
    (void)applyDetachedUndoNow();
  }

  if (!tareCritical && g_enterUiState == ENTER_UI_IDLE && Net::mqttPopUndoAck()) {
    const WeighStack::Entry* top = WeighStack::peek();
    bool matchingEntry = g_remoteUndoAwaitingAck && top &&
      strcmp(top->confirmResponseId, g_remoteUndoConfirmId) == 0;
    bool restored = matchingEntry && restoreTopStackEntryAfterUndo(millis());
    g_remoteUndoAwaitingAck = false;
    g_remoteUndoConfirmId[0] = '\0';
    if (restored) buzzerOk();
    else {
      Serial.println(F("[STACK] ACK undo senza entry staged"));
      buzzerError();
    }
  }

  // Due bip di avviso se MQTT si disconnette (WiFi ancora up)
  if (!tareCritical && g_enterUiState == ENTER_UI_IDLE &&
      Net::mqttPopDisconnectBeep() && WiFi.isConnected()) {
    buzzerWarn();
    delay(120);
    buzzerWarn();
  }

  // Bip distintivo quando arriva un nuovo comando weigh da MQTT
  if (!tareCritical && g_enterUiState == ENTER_UI_IDLE && Net::mqttPopCommandRxBeep()) {
    buzzerMqttRx();
  }
#endif

  serial_task();

  uint32_t now = millis();
  updateEnterUiTimeout(now);

#if ENABLE_MQTT
  if (!tareCritical && Net::mqttPopConfirmRequest()) {
    bool remoteBusy = g_enterUiState != ENTER_UI_IDLE ||
      isTareBehaviorLocked(now) || CalWizard::isActive() ||
      CalWizard::isLongPressInProgress() || g_syncIncidentNeedsTare;
#if ENABLE_WIFI_OTA
    remoteBusy = remoteBusy || Net::isOtaInProgress();
#endif
    if (remoteBusy) {
      Net::mqttFailConfirmRequest("busy");
    } else {
      Serial.println(F("[ENTER] Richiesta dal Manager"));
      g_remoteConfirmActive = true;
      beginEnterAction(now, true);
    }
  }
#endif

  // Audio
  Audio::task(now);

  // Tastiera
  keypad_update(now);
  KeyCode key = keypad_get_event();

#if ENABLE_MQTT
  if (g_detachedUndoKeyGuard && !isTareBehaviorLocked(now)) {
    g_detachedUndoKeyGuard = false;
  }
  if (g_detachedUndoKeyGuard &&
      (key == KEY_TARE || key == KEY_ENTER)) {
    g_deferredLocalKey = key;
    key = KEY_NONE;
  } else if (!g_detachedUndoKeyGuard && key == KEY_NONE &&
             g_deferredLocalKey != KEY_NONE &&
             g_enterUiState == ENTER_UI_IDLE &&
             !isTareBehaviorLocked(now)) {
    key = g_deferredLocalKey;
    g_deferredLocalKey = KEY_NONE;
    Serial.println(F("[KEYPAD] Input locale ripreso dopo UNDO"));
  }
#endif

#if ENABLE_MQTT
  bool mqttOutboxPending = Net::isMqttResponsePending();
  bool mqttOperatorLocked = Net::isMqttResponseOperatorLocked();
  bool mqttLocalFallback = Net::isMqttLocalFallbackActive();
#else
  bool mqttOutboxPending = false;
  bool mqttOperatorLocked = false;
  bool mqttLocalFallback = false;
#endif

  // ENTER acquisition/results are self-closing and ignore every key so a
  // second press cannot create a duplicate commit or dismiss the feedback.
  if (g_syncIncidentNeedsTare) {
    CalWizard::cancelLongPress();
    if (CalWizard::isActive()) CalWizard::abort();
    g_skipShortPending = false;
    if (keypad_is_pressed(KEY_SKIP)) g_skipBlockedUntilRelease = true;
    g_clearPressStartMs = 0;
    g_clearLongPressFired = false;
    if (key == KEY_ENTER || key == KEY_SKIP || key == KEY_CLEAR) {
      Serial.println(F("[KEYPAD] Bloccato: verifica peso/TARA richiesta"));
      buzzerError();
      key = KEY_NONE;
    }
  } else if (g_enterUiState != ENTER_UI_IDLE) {
    CalWizard::cancelLongPress();
    g_skipShortPending = false;
    if (keypad_is_pressed(KEY_SKIP)) g_skipBlockedUntilRelease = true;
    if (key != KEY_NONE) {
      Serial.println(F("[KEYPAD] Ignorato durante ENTER"));
      key = KEY_NONE;
    }
  // A RAM outbox is a locked transaction until durable browser ACK.
  } else if (mqttOutboxPending) {
    CalWizard::cancelLongPress();
    g_skipShortPending = false;
    if (keypad_is_pressed(KEY_SKIP)) g_skipBlockedUntilRelease = true;
#if ENABLE_MQTT
    bool localOverrideKey = key == KEY_TARE || key == KEY_ENTER;
    if (mqttOperatorLocked && localOverrideKey &&
        Net::mqttDetachForLocalInput()) {
      mqttOperatorLocked = false;
      mqttLocalFallback = true;
      if (applyDetachedUndoNow()) {
        g_deferredLocalKey = key;
        key = KEY_NONE;
      }
    }
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

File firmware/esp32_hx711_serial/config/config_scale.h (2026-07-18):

#pragma once

#include <Arduino.h>

// =============================================================================
// CONFIG_SCALE.H - Configurazione bilancia per Minù Bench Scale
// =============================================================================

namespace ScaleConfig {

// ========================= CALIBRAZIONE (seed) =========================
// Valori indicativi, sovrascritti da NVS + CAL
static const long  DEFAULT_REF_RAW  = 265290;   // raw medio con 2000 g
static const long  DEFAULT_ZERO_RAW = 51471;    // raw medio a vuoto
static const long  DEFAULT_REF_G    = 2000;     // grammi di riferimento

inline float defaultCpg() {
  return (float)(DEFAULT_REF_RAW - DEFAULT_ZERO_RAW) / (float)DEFAULT_REF_G;
}

// ========================= HX711 =========================
static const uint8_t  HX711_PULSE_US       = 1;     // Micro-delay per lettura
static const uint32_t HX711_INIT_TIMEOUT_MS = 1200;  // Timeout init

// ========================= WATCHDOG / BUS TIMEOUT =========================
static const uint32_t LOOP_WDT_TIMEOUT_MS      = 8000;   // Task watchdog loop
static const uint16_t I2C_TIMEOUT_MS           = 50;     // Timeout transazioni Wire

// ========================= AUTO-TARE BOOT =========================
static const bool     AUTO_TARE_ON_BOOT         = true;
static const uint16_t AUTO_TARE_SETTLE_MS       = 300;
static const uint16_t AUTO_TARE_MAX_MS          = 2000;
static const uint8_t  AUTO_TARE_TARGET_SAMPLES  = 64;
static const uint8_t  AUTO_TARE_MIN_SAMPLES     = 32;
static const uint8_t  AUTO_TARE_TRIM_SAMPLES    = 8;

// ========================= TARE UI =========================
static const uint8_t  TARE_SAMPLE_BUF_N      = 64;    // Finestra mobile campioni tara
static const uint32_t TARE_OK_HOLD_MS        = 200;   // Feedback breve a tara applicata
static const uint32_t TARE_FAIL_HOLD_MS      = 1200;  // Remains visible after the error beep

// Manual tare at 80-95 SPS. It starts after the debounced key release and
// averages ambient vibration instead of requiring a perfectly quiet bench.
static const uint32_t TARE_MANUAL_SETTLE_MS         = 60;
static const uint32_t TARE_MANUAL_MIN_MS            = 700;
static const uint32_t TARE_MANUAL_MAX_MS            = 1600;
static const uint32_t TARE_MANUAL_ARM_MAX_MS        = 1500;
static const uint8_t  TARE_MANUAL_WINDOW_SAMPLES    = 64;
static const uint8_t  TARE_MANUAL_TRIM_SAMPLES      = 8;
static const uint8_t  TARE_MANUAL_EDGE_SAMPLES      = 16;
static const uint8_t  TARE_MANUAL_STABLE_SAMPLES    = 1;
static const uint32_t TARE_MANUAL_SAMPLE_MAX_AGE_MS = 75;
static const uint32_t TARE_MANUAL_WINDOW_MAX_MS     = 1000;
// Only sustained drift rejects a manual tare. Sample range is diagnostic:
// periodic vibration widens it without moving the robust center.
static const float    TARE_MANUAL_MAX_SLOPE_GPS     = 10.0f;

// LIVE ENTER keeps its stricter quiet-weight gate; it is intentionally
// independent from the more tolerant explicit TARE operation.
static const float    LIVE_ENTER_RANGE_G            = 2.5f;
static const float    LIVE_ENTER_SLOPE_GPS          = 2.0f;

// Bounded ENTER acquisition used when the normal STABLE gate is not ready.
// Raw samples are decimated to about 40 Hz so the 64-slot window spans most
// of the 1.5 s progress bar. Range is diagnostic; sustained drift rejects.
// The fallback slope is deliberately looser than the normal LIVE gate so a
// centered liquid oscillation is not mistaken for continued pouring.
static const uint32_t ENTER_CAPTURE_MAX_MS            = 1500;
static const uint32_t ENTER_CAPTURE_SETTLE_MS         = 60;
static const uint8_t  ENTER_CAPTURE_SAMPLE_BUF_N      = 64;
static const uint8_t  ENTER_CAPTURE_MIN_SAMPLES       = 48;
static const uint8_t  ENTER_CAPTURE_RAW_DECIMATION    = 2;
static const uint32_t ENTER_CAPTURE_SAMPLE_MAX_AGE_MS = 75;
static const uint32_t ENTER_CAPTURE_WINDOW_MIN_MS     = 1000;
static const uint32_t ENTER_CAPTURE_WINDOW_MAX_MS     = 1600;
static const float    ENTER_CAPTURE_MAX_SLOPE_GPS     = 4.0f;
static const uint32_t ENTER_SUCCESS_HOLD_MS            = 1300;
static const uint32_t ENTER_FAIL_HOLD_MS               = 2000;

// The post-ENTER working tare never opens a second sampling window: the quiet
// path uses the current filtered WORK raw; the fallback uses its robust center.

// ========================= LIMITE DISPLAY =========================
static const float MAX_DISPLAY_G   = 16000.0f;      // Soglia fault simmetrica ±16 kg
static const float OVERLOAD_EXIT_G = 15950.0f;      // 50 g hysteresis

// ========================= FILTRI =========================
static const int   MA_DEFAULT      = 6;             // Media mobile (work)
static const int   MA_FINE         = 4;             // Media mobile (live)
static const float DB_UNSTABLE_N   = 0.10f;         // Deadband UNSTABLE (normal)
static const float DB_UNSTABLE_F   = 0.05f;         // Deadband UNSTABLE (fine)
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

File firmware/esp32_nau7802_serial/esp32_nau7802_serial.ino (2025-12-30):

// =======================================================
// ESP32 DevKit + NAU7802 (5 V) + OLED SSD1322 256x64
// Versione "light" con stati STABLE/UNSTABLE + ZT + OLED
//  • NAU7802 su I2C (D27 = SDA, D26 = SCL)
//  • OLED SSD1322 su SPI hardware (CLK=18, MOSI=23)
//    CS=D21, DC=D22, RST=D19  (tutti lato basso destro)
// =======================================================

#include <Arduino.h>
#include <Wire.h>
#include <SPI.h>
#include <U8g2lib.h>
#include "SparkFun_Qwiic_Scale_NAU7802_Arduino_Library.h"
#include "battery_monitor.h"
#include "ui_display.h"
#include "keypad.h"
#include "scale_core.h"
#include <Preferences.h>
#include <math.h>
#include "battery_monitor.h"
#include "buzzer.h"
#include "net_ota_cloud.h"
Preferences prefs; 
NAU7802 myScale;

// Stato boot (per gestire errori "hard" vs "ack")
static bool g_nauBeginOk = false;

// ========================= CONFIG =========================

// [0] Calibrazione seed (valori indicativi, sovrascritti da NVS + CAL)
const long  DEFAULT_REF_RAW  = 265290;   // raw medio con 2000 g
const long  DEFAULT_ZERO_RAW = 51471;    // raw medio a vuoto
const long  DEFAULT_REF_G    = 2000;     // grammi di riferimento
const float DEFAULT_CPG      = float(DEFAULT_REF_RAW - DEFAULT_ZERO_RAW) / float(DEFAULT_REF_G);
// ≈ 106.91 counts/grammo

// [1] Auto-TARE all’avvio (semplice, niente logiche complicate)
const bool     AUTO_TARE_ON_BOOT   = true;
const uint16_t AUTO_TARE_SAMPLES   = 25;
const uint16_t AUTO_TARE_SETTLE_MS = 800;

// [2] Limite operativo visuale (±16 kg)
const float MAX_DISPLAY_G = 16000.0f;
const bool  FLAG_OVERLOAD = true; // logga over=1 se clamp

// [3] Filtri display
int   MA_DEFAULT       = 6;      // normal / work
int   MA_FINE          = 4;      // fine / live
float DB_UNSTABLE_N    = 0.10f;  // deadband in UNSTABLE (normal)
float DB_UNSTABLE_F    = 0.05f;  // deadband in UNSTABLE (fine)
float       deadbandUnstable = DB_UNSTABLE_N;

// [4] Stati STABLE/UNSTABLE (semplificati)
const bool  ST_ENABLE_DEFAULT   = true;
float       ST_LEAVE_DELTA_G    = 0.80f;  // se |gLive - gLatch| ≥ 0.80 g → UNSTABLE
float       ST_ENTER_RANGE_G    = 0.60f;  // range < 0.60 g → STABLE
uint32_t    ST_TO_STABLE_MS     = 1200;   // finestra per valutare il rientro (1.2 s)

// [5] Zero-Tracking (solo near-zero + snap allo scarico)
const bool  ZT_ENABLE_DEFAULT   = true;

// 5a) Micro-correzione lenta vicino a 0
float       ZT_WINDOW_G         = 1.5f;     // attivo se |g| ≤ 1.5 g
uint32_t    ZT_QUIET_MS         = 1200;     // serve “quiete” per almeno 1.2 s
float       ZT_QUIET_RANGE_G    = 0.4f;     // range ≤ 0.4 g
float       ZT_QUIET_SLOPE_GPS  = 0.3f;     // |slope| ≤ 0.3 g/s
uint32_t    ZT_PERIOD_MS        = 1000;     // passo ogni 1.0 s
float       ZT_STEP_G           = 0.02f;    // ~0.02 g per passo
float       ZT_MAX_G            = 3.0f;     // cap totale ±3 g

// 5b) Snap-to-zero su scarico
const bool  UNLOAD_SNAP_ENABLE   = true;
float       UNLOAD_CROSS_WIN_G   = 6.0f;    // esegui snap se |g| ≤ 6 g
float       UNLOAD_SLOPE_GPS_NEG = -3.0f;   // pendenza ≤ −3 g/s
uint32_t    UNLOAD_SLOPE_WIN_MS  = 400;     // finestra per slope scarico
float       UNLOAD_STABLE_RANGE_G= 0.8f;    // range “quiete” per snap
uint32_t    UNLOAD_STABLE_MS     = 300;     // ms di quiete
uint32_t    UNLOAD_COOLDOWN_MS   = 2000;    // minimo tra due snap
float       UNLOAD_SNAP_MAX_G    = 5.0f;    // correzione max snap (g)

// [6] Campionamento logica (non il sample rate del NAU)
const uint32_t SAMPLE_MS = 60; // ~16 Hz logica, NAU a 40 SPS

// [OLED] Cadenzamento refresh
const uint32_t OLED_UPDATE_MS = 60;

// ========================= PIN & OGGETTI =========================

// NAU7802: I2C spostato su D27 (SDA) e D26 (SCL) per averli vicini
const int I2C_SDA = 32;  // etichetta scheda: D27 (GPIO27)
const int I2C_SCL = 33;  // etichetta scheda: D26 (GPIO26)



// ========================= CALIBRAZIONE RUNTIME =========================
// g = (rawAvg - (OFFSET_RAW + zero_track_counts)) / SCALE_CPG
long  OFFSET_RAW = 0;
float SCALE_CPG  = DEFAULT_CPG;
long  REF_G      = DEFAULT_REF_G;

// Zero-Tracking accumulatore (solo software)
long  zero_track_counts = 0;
bool  ztEnable = ZT_ENABLE_DEFAULT;


// ========================= FILTRI =========================
long medBuf[3] = {0,0,0};
int  medIdx=0, medCount=0;

long median3(long a,long b,long c){
  long M = max(a, max(b,c));
  long m = min(a, min(b,c));
  return a + b + c - M - m;
}

long pushMedian3(long x){
  medBuf[medIdx] = x;
  medIdx = (medIdx + 1) % 3;
  if (medCount < 3) medCount++;
  if (medCount < 3){
    long s=0;
    for(int i=0;i<medCount;i++) s += medBuf[i];
    return s / (medCount ? medCount : 1);
  }
  return median3(medBuf[0], medBuf[1], medBuf[2]);
}

void resetMedian(){
  medIdx=0; medCount=0;
  medBuf[0]=medBuf[1]=medBuf[2]=0;
}

long maBuf[8];
int  maIdx=0, maCount=0, maN=MA_DEFAULT;
long maSum=0;

void setMA(int n){
  maN = constrain(n,1,8);
  maIdx=0; maCount=0; maSum=0;
  for(int i=0;i<8;i++) maBuf[i]=0;
}

long pushMA(long x){
  if (maCount == maN) {
    maSum -= maBuf[maIdx];
  } else {
    maCount++;
  }
  maBuf[maIdx] = x;
  maSum += x;
  maIdx++;
  if (maIdx >= maN) maIdx = 0;
  return maSum / (maCount ? maCount : 1);
}
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

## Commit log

2025-11-22 aggiornamento oled, pin e readme
2025-11-30 fix vari, manca il buzzer che fruscia
    [buzzer.cpp, esp32_nau7802_serial.ino, keypad.cpp]
2025-12-10 Cambiato pin tastiera e readme aggiornato
2025-12-20 fix pad e rimozione flipping
    [keypad.cpp, ui_display.cpp]
2026-01-01 media per ridurre il rumore
2026-01-03 cambio pin led sleep
2026-01-04 aggiornato sistema di sospensione player
2026-01-04 suoni e logiche di inattività
2026-01-09 FIX audio e standby attivato solo se sono si sta pesando
    [battery_monitor.cpp, esp32_hx711_serial.ino]
2026-02-05 fix: OtaStore::clearPassword() → OtaStore::clear()
    https://claude.ai/code/session_01CnZFP3EZqJpGsuuATN2mBt
    [esp32_hx711_serial.ino]
2026-02-05 fix: rename Track::WIFI_ON/OFF to avoid ESP32 macro conflict
    WIFI_OFF is a macro in ESP32 WiFi lib (→ WIFI_MODE_NULL).
    Renamed to WIFI_MODULE_ON/OFF to avoid namespace collision.
    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
    [config_audio.h, esp32_hx711_serial.ino]
2026-02-05 debug: add tare diagnostic logging
    Print sample count and elapsed time when tare is applied
    to diagnose why tare might not be working.
    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
2026-02-05 debug: add more tare diagnostics
    Log tareStart() call with timestamp and verify g_tareActive.
    Log first sample accumulation in tareAccumSample().
    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
2026-02-05 fix: use fresh millis() in tareMaybeApply to prevent timing bug
    The bug: tareStart() was called with millis() during keypad handling,
    but tareMaybeApply() was called with 'now' calculated at loop start.
    This caused elapsed time to be negative (overflow) when the tare
    button was pressed late in the loop iteration.
    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
    [esp32_hx711_serial.ino]
2026-02-06 refactor: complete firmware improvements and fixes
    1. FIX: inactivity now resets on weight change (popWeightActivity pattern)
    2. Remove dead code: scale_core.cpp/h, ui_renderHxRuntimeError
    3. Add Task Watchdog (8s timeout, auto-reboot on hang)
    4. Create config/config_battery.h for battery/shutdown constants
    5. Split net_ota_cloud.h into .h/.cpp (proper separation)
    6. Add serial calibration commands: cal status/zero/ref/save/load
    7. Update README with new architecture and calibration docs
    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
    [config_battery.h, esp32_hx711_serial.ino, net_ota_cloud.cpp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]
2026-02-06 feat: add on-display calibration wizard
    - Add CalWizard:: namespace with 4-step calibration workflow
    - Step ZERO: acquire empty plate offset
    - Step PLACE: acquire reference weight raw
    - Step VALUE: select weight value (500-20000g)
    - Step CONFIRM: verify and save calibration
    - Add long press detection (3s on TARE) to trigger wizard
    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
2026-02-07 fix: calibration wizard improvements
    - Change activation from long press to TARE+CLEAR combo
    (avoids accidental activation during normal tare)
    - Fix sample accumulation: track last raw to avoid duplicates
    (fixes flickering progress bar)
    - Widen CPG validation range from 50-500 to 20-1000
    (supports more load cell types)
    - Add detailed serial debug output for each step
    - Update README with new activation method
    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
    [calibration_wizard.cpp, calibration_wizard.h]
2026-02-07 fix: change calibration wizard activation to CLEAR then TARE combo
    - Changed wizard activation from simultaneous key press to sequential
    combo: press CLEAR, then TARE within 1 second
    - Added checkComboAndStart() API to handle combo detection from main loop
    - Fixed TARE button regression caused by wizard consuming key events
    - Moved CalWizard::update() after keypad_get_event() in main loop
    - Updated README documentation with new combo sequence
    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
    [calibration_wizard.cpp, calibration_wizard.h, esp32_hx711_serial.ino]
2026-02-07 fix: change calibration wizard activation to SKIP long press (5 sec)
    - Changed wizard activation from CLEAR+TARE combo to holding SKIP for 5 seconds
    - Added updateLongPress(), isLongPressInProgress(), getLongPressProgress() API
    - Removed checkComboAndStart() function (no longer needed)
    - Updated UI to show "Tieni premuto SKIP" instead of TARE
    - Updated README documentation with new activation method
    - Long press progress bar shown while holding SKIP
    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
    [calibration_wizard.cpp, calibration_wizard.h, esp32_hx711_serial.ino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]
2026-02-07 fix: delay wizard UI display and fix ENTER key not working
    - Added 2 second delay before showing long press UI (LONG_PRESS_SHOW_UI_MS)
    - Progress bar now shows 0% at 2s and 100% at 5s
    - Fixed ENTER key not working: pass key to update() instead of
    calling keypad_get_event() internally (event was already consumed)
    - Changed update() signature to accept KeyCode parameter
    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
    [calibration_wizard.cpp, calibration_wizard.h, esp32_hx711_serial.ino]
2026-02-07 debug: add detailed output to wizard calibration for diagnosis
    Added verbose debug output to help diagnose calibration issues:
    - STEP_ZERO: prints zero raw value
    - STEP_PLACE: prints ref raw, zero raw, and delta
    - STEP_CONFIRM: prints complete CPG calculation breakdown
    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
    [calibration_wizard.cpp]
2026-02-07 debug: add verification of saved calibration values
    Print the actual saved values after wizard calibration completes
    to verify they match what was calculated.
    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
2026-02-07 debug: add sample accumulation output for calibration diagnosis
    Show each sample value and accumulator state to diagnose
    why wizard calibration is producing incorrect CPG values.
    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
2026-02-07 fix: stop accumulating samples after reaching SAMPLES_NEEDED
    The wizard was continuing to accumulate samples even after reaching
    32 samples, causing g_sampleCount (uint8_t) to overflow from 255 to 0.
    This resulted in incorrect average calculations and wrong calibration.
    Now we check at the start of accumulateSample() and return immediately
    if we already have enough samples.
    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
    [calibration_wizard.cpp]
2026-02-07 fix: wait for weight detection before sampling in STEP_PLACE
    The wizard was starting to sample immediately after STEP_ZERO completed,
    before the user had time to place the weight on the scale. This resulted
    in sampling the empty scale values instead of the weight.
    Now in STEP_PLACE:
    1. Wait until raw value differs from zeroRaw by > 50000 counts
    2. Beep when weight is detected
    3. Reset sampling and start fresh
    4. Then accumulate 32 samples of the actual weight
    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
    [calibration_wizard.cpp]
2026-02-07 fix: start sampling only after user presses ENTER in STEP_PLACE
    Previously, sampling started automatically when weight was detected,
    but the weight was often still settling. Now the flow is:
    1. User places weight on scale
    2. User presses ENTER when weight is stable
    3. If weight detected (diff > threshold), start sampling
    4. After 32 samples, user presses ENTER again to confirm
    This ensures samples are taken only when the weight is stable.
    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
    [calibration_wizard.cpp]
2026-06-08 correzioni bug bilancia e file agentico
    [config_scale.h, esp32_hx711_serial.ino, net_ota_cloud.cpp]
2026-07-22 fix mqtt
    [firmware_mqtt_protocol_harness.obj]
2026-09-19 aggiornamenti ina
    [MINU_concept_01_assembly_WITH_REFERENCES.step, UPS-HAT_D.stp, base.step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]
2026-11-02 led e schemi aggiornati
